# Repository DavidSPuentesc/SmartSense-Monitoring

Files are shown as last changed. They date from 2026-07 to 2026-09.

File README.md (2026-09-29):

# SmartSense Monitoring



Proyecto académico de monitoreo de temperatura superficial industrial con
PT100 de tres hilos, MAX31865, ESP32-C6, comunicación LoRa y consulta histórica
en un dashboard local. Apoya monitoreo de condición; no implementa ni valida
mantenimiento predictivo.

## Contenido del repositorio

- [SmartSense_Trabajo_Grado.tex](SmartSense_Trabajo_Grado.tex): tesis monográfica de una columna, clase `report`, fuera del formato IEEE.
- `tesis/`: preliminares, diez capítulos, anexos, bibliografía autor-fecha y registro compartido `datos-evidencia.tex`.
- [hardwarex/SmartSense_HardwareX.tex](hardwarex/SmartSense_HardwareX.tex): artículo HardwareX.
- `SmartSense_IEEE.tex`: fuente histórica conservada.
- `figuras/`: imágenes y fotografías usadas por ambos documentos.
- `figuras_anteproyecto/`: diagramas del anteproyecto.
- `Entrega_SmartSense/`: entregas anteriores.
- `compilar_trabajo_grado.ps1` y `hardwarex/compilar_hardwarex.ps1`: compilación de los documentos actuales en Windows.
- `compilar_ieee.ps1`: compilación del documento histórico.
- `COMPILAR_LATEX.md`: instrucciones de compilación.

La carpeta `.tools` no se sube porque contiene un ejecutable local. Cada
integrante puede instalar Tectonic o una distribución de LaTeX en su equipo.

## PDF para compartir

| Documento | Entregable actual |
|---|---|
| Trabajo de grado | [SmartSense_Trabajo_Grado.pdf](PDF_Para_Compartir/SmartSense_Trabajo_Grado.pdf) |
| Artículo HardwareX | [SmartSense_HardwareX.pdf](PDF_Para_Compartir/SmartSense_HardwareX.pdf) |

Los archivos previos `PDF_Para_Compartir/Articulo_SmartSense_HardwareX.pdf` y
`PDF_Para_Compartir/Tesis_SmartSense_Monitoring.pdf`, cuando estén presentes,
pertenecen al usuario y deben conservarse sin sobrescribir. Los nuevos
entregables usan los nombres de la tabla. Las fuentes, los PDF compilados
actuales y las nuevas copias de entrega quedan versionados en esta rama.

## Compilación

En Windows:

```powershell
powershell.exe -NoProfile -ExecutionPolicy Bypass -File .\compilar_trabajo_grado.ps1
powershell.exe -NoProfile -ExecutionPolicy Bypass -File .\hardwarex\compilar_hardwarex.ps1
```

Los resultados son `SmartSense_Trabajo_Grado.pdf` en la raíz y
`hardwarex/SmartSense_HardwareX.pdf`. Los scripts no copian automáticamente a
la carpeta de entrega. Véase [COMPILAR_LATEX.md](COMPILAR_LATEX.md) para la
selección de compilador, limpieza limitada de auxiliares, verificación y copia.

## Evidencia y reproducibilidad

Los tres archivos de nodos suman 51.338 muestras: A/C abarcan 8 de mayo a 9 de
junio de 2026 (32 días); B abarca 10 de mayo a 20 de julio. No son 32 días
completos comunes. Disponibilidad durante actividad inferida y PDR estimado
usan filtros distintos. La autonomía se extrapola de cinco días; 688 m es
una cota inferior del recorrido. Frente al Fluke, seis parejas con foto y hora
verificables contra el CSV difieren 0,15 °C de media absoluta y 0,23 °C como máximo.

Hay firmware, hardware, carcasa STL/3MF, BOM, figuras, scripts y las fuentes de la
tesis y del artículo. Faltan los CSV primarios del piloto, cuya publicación depende
de la empresa aliada, y la clase de tolerancia de la PT100. El repositorio está
publicado como versión `v1.0-tesis` y archivado en Zenodo con el DOI de concepto
[10.5281/zenodo.22903028](https://doi.org/10.5281/zenodo.22903028), que resuelve a la
versión más reciente (esta versión: 10.5281/zenodo.22903029).

Las licencias están descritas en [LICENSES/README.md](LICENSES/README.md):
CERN-OHL-S v2 para hardware (incluida la BOM), MIT para firmware/software/análisis
y CC-BY 4.0 para documentación. La réplica local está en `docker/` y el firmware
LoRa en `sensores espnow lora/version con lora y pagina local/`.

Para colaborar, repartir capítulos o figuras en ramas y revisar los cambios
antes de integrarlos. No presentar ensayos nuevos sin sus registros primarios.

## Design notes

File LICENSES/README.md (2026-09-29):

# Licencias de SmartSense Monitoring

Este proyecto es open source. Cada parte tiene su licencia (como exige HardwareX):

| Parte del proyecto | Archivos | Licencia |
|---|---|---|
| **Hardware** (esquemáticos KiCad, cableado, carcasa PLA / CAD / STL) | `hardware/`, `figuras/esquematico-*`, CAD de la carcasa | **CERN-OHL-S v2** — `CERN-OHL-S-v2.txt` |
| **Firmware y software** (sketches Arduino, réplica Docker, scripts de análisis) | `sensores espnow lora/`, `docker/`, `analisis/` | **MIT** — `MIT.txt` |
| **Documentación** (manuscritos, figuras, tablas, README y PDF) | `SmartSense_IEEE.tex`, `hardwarex/`, `SmartSense_Trabajo_Grado.tex`, `tesis/`, `*.md`; los PDF de trabajo `SmartSense_Trabajo_Grado.pdf` y `hardwarex/SmartSense_HardwareX.pdf`; y los PDF de entrega versionados `PDF_Para_Compartir/SmartSense_Trabajo_Grado.pdf` y `PDF_Para_Compartir/SmartSense_HardwareX.pdf` | **CC-BY 4.0** — `CC-BY-4.0.txt` |

Las copias históricas conservadas localmente en `PDF_Para_Compartir/Articulo_SmartSense_HardwareX.pdf` y `PDF_Para_Compartir/Tesis_SmartSense_Monitoring.pdf` también son documentación bajo CC-BY 4.0, pero no forman parte de la entrega versionada. Los dos PDF de entrega vigentes sí son `PDF_Para_Compartir/SmartSense_Trabajo_Grado.pdf` y `PDF_Para_Compartir/SmartSense_HardwareX.pdf`. Esta asignación no modifica las licencias de los materiales de terceros citados o incorporados bajo sus propios términos.

El mapa es coherente con las declaraciones del artículo HardwareX: CERN-OHL-S v2 para hardware, MIT para firmware/software/análisis y CC-BY 4.0 para documentación. La tesis y sus PDF aplican esta misma licencia de documentación.

## Depósito en Zenodo

Versión `v1.0-tesis` archivada el 22 de septiembre de 2026: DOI de concepto
[10.5281/zenodo.22903028](https://doi.org/10.5281/zenodo.22903028), que resuelve a la
versión más reciente (esta versión: 10.5281/zenodo.22903029). El depósito incluye los
esquemáticos KiCad editables, la BOM y las conexiones, el firmware, la réplica Docker,
los scripts de análisis, los STL/3MF de la carcasa, las fuentes de la tesis y del
artículo y estos archivos de licencia. Cada release nuevo en GitHub genera una versión
nueva bajo el mismo DOI de concepto.

`secrets.h` está fuera del repositorio y el árbol versionado no contiene credenciales.
La clave que quedó en el historial de git es la del punto de acceso del propio
prototipo, sin valor fuera de él.

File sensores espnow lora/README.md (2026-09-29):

# Sensores ESP-NOW y LoRa

Repositorio de desarrollo del sistema SmartSense para adquisición de
temperatura, comunicación entre nodos y visualización local.

## Versiones incluidas

- `version con espnow/`: prototipo de comunicación ESP-NOW.
- `version con pagina web en wifi local/`: versión con interfaz web en la red
  Wi-Fi local.
- `version con lora y pagina local/`: versión actual con nodos LoRa, maestro
  con pantalla, dashboard local y módulos de alarma.

La copia `.rar`, los cachés de Python y los ajustes personales de VS Code no
se versionan.

## Trabajo en paralelo

Antes de comenzar una tarea:

```powershell
git switch main
git pull
git switch -c nombre/tarea
```

Al terminar:

```powershell
git add .
git commit -m "Describe el cambio"
git push -u origin nombre/tarea
```

Después se abre un *pull request* hacia `main`. Cada persona debe trabajar en
una rama diferente y evitar editar simultáneamente el mismo sketch.

## Seguridad

Las credenciales locales de las pruebas de Wi-Fi y actualización OTA van en
`secrets.h`, que Git ignora; cada sketch trae una plantilla `secrets.example.h`.

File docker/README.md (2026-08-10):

# Réplica Docker — SmartSense Monitoring

Réplica local y **neutra** (sin marca de empresa) del dashboard, pensada para:

- Cargar de forma masiva los exportes CSV de la planta (botón **Cargar CSV**).
- Explorar el histórico por sensor y generar las figuras del artículo/tesis.
- Servir de demo genérica reutilizable para cualquier empresa (nombre configurable en `.env`).

Está programado en **Python (Flask)** con almacenamiento **SQLite**; la página es HTML + JavaScript plano.

## Uso

```bash
docker compose up --build
```

Abrir <http://localhost:8500>. Los datos quedan en `./data/lecturas.db` (SQLite, persistente entre reinicios).

> El puerto por defecto es **8500** porque la franja 8080–8161 la ocupan los contenedores de securapp en esta máquina (por eso al abrir el 8080 aparecía la app de RAMO).

El `.env` es **opcional**: si existe, Compose lo lee solo (copiar de `.env.example` para cambiar el nombre visible o el puerto).

## Formato del CSV

Encabezado flexible (se aceptan `,` o `;` y coma decimal de Excel). Columnas reconocidas:

| Dato | Encabezados aceptados | Obligatorio |
|---|---|---|
| Sensor | `sensor`, `mac`, `nodo`, `nombre`, `id` | Sí |
| Fecha y hora | `timestamp`, `ts`, `fecha_hora`, `datetime` — o `fecha` + `hora` en columnas separadas | Sí |
| Temperatura (°C) | `temperatura`, `temp`, `temp_c`, `temperature` | Sí |
| Batería (%) | `bateria`, `battery`, `bat` | No |

Formato canónico recomendado:

```csv
sensor,timestamp,temperatura_c,bateria_pct
Nodo-1,2026-01-15 10:00:00,25.4,87
```

Las filas duplicadas (mismo sensor + misma marca de tiempo) se ignoran, así que se puede recargar el mismo archivo sin duplicar datos.

## Validaciones incluidas

- Archivo: solo `.csv`/`.txt`, no vacío, máximo 64 MB.
- Encabezado irreconocible → mensaje que dice exactamente qué columna falta y qué nombres se aceptan.
- Por fila: fecha/hora inválida, temperatura no numérica o fuera del rango físico de una PT100 (−200 a 850 °C) → la fila se rechaza y se reporta con número de línea y motivo (primeras 10).
- Batería fuera de 0–100 % → se descarta la batería pero **se conserva** la lectura de temperatura.
- Fechas del histórico: formato AAAA-MM-DD; si el rango viene invertido se corrige solo.
- Todos los errores del servidor responden JSON con mensaje claro (nunca una página HTML de error).

## Verificación rápida

```bash
python app.py selftest
```

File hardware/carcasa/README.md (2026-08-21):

# Carcasas impresas en PLA (design files)

Archivos de la carcasa del nodo sensor y del gateway, para impresión 3D.

| Archivo | Qué es |
|---|---|
| `carcasa-sensor.stl` | Cuerpo de la carcasa del nodo sensor |
| `tapa-sensor.stl` | Tapa del nodo sensor |
| `carcasa-gateway.stl` | Cuerpo de la carcasa del gateway/visualizador |
| `tapa-gateway.stl` | Tapa del gateway |
| `sensor.3mf.zip` | Proyecto 3MF del nodo (laminado/orientación de impresión) |

**Formato:** solo STL + 3MF (archivos para imprimir). No se dispone del CAD
editable original. Para HardwareX, el STL es un design file válido; el CAD
editable se documentará si se rehace el modelo.

**Nota IP:** la carcasa PLA impresa no tiene una clasificación IP certificada;
está pensada para ambiente controlado / interior. Para exteriores o zonas con
polvo/humedad se recomienda rediseñar con sellos apuntando a IP54/IP65.

Licencia: CERN-OHL-S v2 (ver `LICENSES/`).

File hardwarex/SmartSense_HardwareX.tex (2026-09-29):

% SmartSense Monitoring - HardwareX article
% Built on the official HardwareX article template (Version 2, June 2021).
% Template instructions (italic text) have been removed as required before submission.
\documentclass[11pt, letterpaper]{article}
\usepackage[utf8]{inputenc}
\usepackage[margin=1.5cm]{geometry}
\usepackage{titlesec}
\usepackage{tabu}
\usepackage{enumitem}
\usepackage{amssymb}
\usepackage{xcolor}
\usepackage{graphicx}
\graphicspath{{../figuras/}}
\usepackage{placeins}

\usepackage{lmodern}
\usepackage{hyperref}
\hypersetup{colorlinks=true, linkcolor=blue, filecolor=magenta, urlcolor=blue}
\urlstyle{same}

\titleformat{\section}[block]{\hspace{1em}\bfseries}{\thesection.}{0.5em}{}
\titleformat{\subsection}[block]{\hspace{1em}}{\thesubsection}{0.5em}{}

\setlength{\parindent}{0pt}
\setlength{\parskip}{10pt}

\begin{document}
\begin{flushleft}

\textbf{Article title}\\
SmartSense Monitoring: an open-source wireless PT100 node and gateway for surface-temperature monitoring of industrial equipment

\textbf{Authors}\\
Jesus Andre Bojaca Lopez, David Santiago Puentes Cardenas*, Jhon Edwin Vera, Sergio Francisco Mora Martinez

\textbf{Affiliations}\\
Electronic Engineering Program, Faculty of Engineering, Universidad ECCI, Bogota D.C., Colombia

\textbf{Corresponding author's email address and Twitter handle}\\
davids.puentesc@ecci.edu.co

\textbf{Abstract}\\
SmartSense Monitoring is an open-source wireless PT100 node and gateway for industrial surface-temperature monitoring. Each battery-powered node combines a XIAO ESP32-C6, a three-wire PT100 probe, a MAX31865 front-end and an Ebyte E220 LoRa radio at 433~MHz. The gateway stores a rolling 30-day history locally and serves a Wi-Fi dashboard without a cloud service. A three-node evaluation includes a 32-day pilot deployment and an extended Node B record, totalling 51{,}338 samples across the individual recording windows. Raw availability was 76.0\%, 32.3\% and 75.1\%; link availability conditioned on inferred gateway-active periods was 97.8--98.4\%. Arrival intervals support an inferred PDR of 95.3--96.6\%. Six time-stamped paired readings against an infrared thermometer, taken with the surface stable, differ by 0.15~$^{\circ}$C on average and 0.23~$^{\circ}$C at most after offset adjustment, without establishing absolute accuracy. A five-day partial discharge supports estimated autonomy of 177 days by linear extrapolation and 291--307 days using a LiPo-curve model, not demonstrated service lifetime. A temperature rise was later associated with a bearing anomaly during inspection, supporting condition monitoring without validated diagnosis or prediction. Hardware, firmware, software and analysis artifacts are versioned in a public repository; absent primary CSV files and incomplete component identification limit full replication of the evaluation.

\textbf{Keywords}\\
Open-source hardware; LoRa; PT100; RTD; MAX31865; ESP32-C6; industrial temperature monitoring; condition monitoring

\newpage
\textbf{Specifications table}\\
\vskip 0.2cm
\tabulinesep=1ex
\begin{tabu} to \linewidth {|X[l]|X[3,l]|}
\hline \textbf{Hardware name} & SmartSense Monitoring \\
\hline \textbf{Subject area} &
  \begin{itemize}[noitemsep, topsep=0pt]
  \item Engineering and material science
  \item Educational tools and open source alternatives to existing infrastructure
  \end{itemize} \\
\hline \textbf{Hardware type} &
  \begin{itemize}[noitemsep, topsep=0pt]
  \item Measuring physical properties and in-lab sensors
  \item Field measurements and sensors
  \item Electrical engineering and computer science
  \end{itemize} \\
\hline \textbf{Closest commercial analog} & Industrial wireless RTD/condition-monitoring loggers such as the Advantech WISE-2410 and commercial PT100 wireless data loggers. \\
\hline \textbf{Open source license} & Hardware: CERN-OHL-S v2. Firmware and software: MIT License. Documentation: CC-BY 4.0. \\
\hline \textbf{Cost of hardware} & Itemized total: 627{,}000~COP ($\approx$157~USD at the project conversion assumption of 4{,}000~COP/USD). Node-specific parts: 149{,}000~COP ($\approx$37~USD), before shared wiring; see Bill of materials. \\
\hline \textbf{Source file repository} & \href{https://github.com/DavidSPuentesc/SmartSense-Monitoring}{SmartSense-Monitoring on GitHub}; archived on Zenodo, DOI \href{https://doi.org/10.5281/zenodo.22903028}{10.5281/zenodo.22903028} (concept DOI resolving to the latest version; release v1.0-tesis: 10.5281/zenodo.22903029). \\
\hline
\end{tabu}
\end{flushleft}

\newpage
\section{Hardware in context}

Continuous temperature monitoring of motors and other industrial equipment helps identify conditions associated with friction, overload, poor ventilation or mechanical degradation. In a manual inspection, an operator obtains only the value at the instant of measurement; if that value is not systematically recorded, the thermal evolution of the equipment cannot be reconstructed or related to its operating and stop cycles.

Wireless sensor networks distribute measurement points without installing communication cabling at each location [1,2,6]. For low-data-rate applications, LoRa provides a long-range, low-power alternative suited to battery-powered nodes, whose range and scalability have been characterised experimentally [3,7,8]. Relevant precedents include LoRaWAN temperature monitoring with a local-server option [9], an open condition-monitoring sensor with vibration and acoustic measurements [10], and the local SD-based HIGROTERM logger [12]. SmartSense contributes the integration of an external three-wire PT100 and MAX31865, point-to-point radio, battery operation and a gateway-hosted daily history and dashboard. Its contribution is this documented platform and pilot evaluation, rather than invention of its constituent technologies or superiority over all existing systems. It supports condition-based maintenance [4,11] but does not implement or validate a predictive-maintenance algorithm.

A PT100 RTD was selected for its established industrial use, three-wire lead compensation with the MAX31865 and availability in a magnetic surface probe suitable for motor housings. The installed probe is a ZUIDID magnetic three-wire PT100 (AliExpress item 1005008619909588): a thin-film element in a 19~$\times$~9.5~mm probe with a protective tube and spring sheath, epoxy-encapsulated with thermally conductive silicone, a standard cable rated $-60$ to 200~$^{\circ}$C and a three-wire U-terminal [14]. The seller does not state the tolerance class, and the $-60$ to 200~$^{\circ}$C figure is the cable rating, so the generic RTD conversion range cannot be assigned to the complete installed probe. The field comparison below characterises agreement in a narrow temperature interval, not the full measurement range or inter-node repeatability.

Compared with proprietary industrial loggers such as the Advantech WISE-2410, SmartSense Monitoring trades integrated vibration sensing for full openness and local-first operation. Table~\ref{tab:comparison} contrasts both systems by capability rather than price alone, making it suitable for pilot plants and educational settings where flexibility and reproducibility matter more than a turnkey platform.

\begin{table}[h]
\centering
\tabulinesep=1ex
\begin{tabu} to \linewidth {|X|X[c]|X[c]|X[0.6,c]|}
\hline
\textbf{Feature} & \textbf{SmartSense} & \textbf{WISE-2410} & \textbf{Advantage} \\\hline
Open hardware & Project schematics and enclosure files, CERN-OHL-S v2 & Commercial design; no open hardware release identified & SmartSense \\\hline
External PT100 & Yes, three-wire surface probe & Integrated temperature sensor; no external PT100 specified & SmartSense \\\hline
Communication & LoRa 433~MHz (point-to-point) & LoRaWAN & Different \\\hline
Vibration sensing & No & Yes & WISE-2410 \\\hline
Local history & microSD or LittleFS; rolling 30-day store & Depends on gateway/application integration & SmartSense \\\hline
Cloud dependency & None for local dashboard & LoRaWAN gateway/server required; cloud is not inherently mandatory & SmartSense \\\hline
IP rating & Not demonstrated & IP66 specified & WISE-2410 \\\hline
Autonomy evidence & Estimated from 5-day partial discharge: 177 or 291--307 days; 1000~mAh, 120~s cycle & Up to 2 years specified; hourly updates [5] & WISE-2410 (specified); SmartSense pending \\\hline
Software openness & MIT node/gateway firmware and software & WISE Studio utility; open firmware not identified & SmartSense \\\hline
Cost basis & 149{,}000~COP per node in listed parts ($\approx$37~USD); excludes shared wiring & No comparable dated quotation available & Not comparable \\\hline
\end{tabu}
\caption{Functional comparison with Advantech WISE-2410 [5]. WISE-2410 retains advantages in vibration, IP66 protection and specified lifetime. Autonomy uses different update intervals and evidence types; no controlled superiority claim follows. SmartSense cost uses the project BOM and a 4{,}000~COP/USD conversion assumption.}
\label{tab:comparison}
\end{table}

\section{Hardware description}

SmartSense Monitoring consists of one or more battery-powered sensor nodes and a gateway/visualizer. Each node acquires the surface temperature of a machine with a magnetic PT100 probe and a MAX31865 RTD front-end, estimates its battery state, and transmits the reading over a 433~MHz LoRa link before entering deep sleep. The gateway receives the frames, identifies each node by its MAC address, applies a configurable offset, stores the samples locally and presents them on an integrated touch display and a Wi-Fi web dashboard.

The documented radio configuration uses 9600~bit/s UART (8N1), 2.4~kbit/s air rate, channel 23 in the stated 433~MHz band and fixed addressing. The radio is an Ebyte E220-400T22D (Semtech LLCC68, 410.125--493.125~MHz), so channel 23 corresponds to 433.125~MHz, its factory frequency. The transmit power is 22~dBm, the module's maximum and factory default, which is also the value (power code 0) written by the firmware's one-time configuration routine; the datasheet gives a typical receiver sensitivity of $-127$~dBm at 2.4~kbit/s [13]. A 120~s nominal cycle provides 720 expected samples per node per day, balancing thermal-history resolution with traffic, storage and battery demand for this pilot.

\begin{itemize}
\item[$\bullet$] It provides automatic periodic surface-temperature logging using commercially available modules and an itemized bill of materials.
\item[$\bullet$] It operates fully offline: the gateway serves its own dashboard over a local Wi-Fi access point, so no cloud account or Internet connection is required.
\item[$\bullet$] It preserves a per-sensor daily history, enabling the study of thermal trends, transients and machine on/off cycles that a spot measurement cannot capture.
\item[$\bullet$] It is a modular basis for further work: additional nodes, alternative RTD probes, or extra variables (e.g. current, vibration) can be integrated by reusing the node design.
\item[$\bullet$] Published project schematics and source code support teaching wireless sensor networks, RTD acquisition and local data handling; the purchased modules retain their manufacturer-specific internals.
\end{itemize}

\section*{\textit{Design files}}

The complete repository, with the editable KiCad schematics, node and gateway firmware, software, BOM, enclosure files, analysis scripts, figures, licenses and the manuscript sources, is released as version \texttt{v1.0-tesis} on GitHub (\href{https://github.com/DavidSPuentesc/SmartSense-Monitoring}{DavidSPuentesc/SmartSense-Monitoring}) and archived on Zenodo under the concept DOI \href{https://doi.org/10.5281/zenodo.22903028}{10.5281/zenodo.22903028}, which resolves to the latest version (this release: 10.5281/zenodo.22903029).

The primary historical and range-test CSV files read by the scripts are not included in the archived version; their publication depends on the partner company\textquotesingle s authorization. The tolerance class of the PT100 probe is not stated by its seller. The repository therefore supports inspection and reconstruction of the documented design, but not yet exact replication of every reported experiment.

\section{Design files summary}
\vskip 0.1cm
\begingroup\small
\tabulinesep=1ex
\begin{tabu} to \linewidth {|X[1.4,l]|X[1,l]|X[1,l]|X[1.5,l]|}
\hline
\textbf{Design filename} & \textbf{File type} & \textbf{Open source license} & \textbf{Location of the file} \\\hline
Node schematic (nodo\_sensor) & KiCad schematic + PDF/SVG & CERN-OHL-S v2 & \texttt{hardware/kicad/} in identified snapshot \\\hline
Gateway schematic (gateway) & KiCad schematic + PDF/SVG & CERN-OHL-S v2 & \texttt{hardware/kicad/} in identified snapshot \\\hline
\nolinkurl{smartsense.kicad_sym} & KiCad symbol library & CERN-OHL-S v2 & \texttt{hardware/kicad/} \\\hline
Node firmware (Nodo\_Lora) & Arduino C++ (.ino) & MIT & Firmware directory specified below \\\hline
Gateway firmware (\nolinkurl{maestro_Lora_pantalla}) & Arduino C++ (.ino) + web assets & MIT & Firmware directory specified below \\\hline
Bill of materials (BOM.csv) & CSV spreadsheet & CERN-OHL-S v2 & \texttt{hardware/BOM.csv} \\\hline
Enclosure (node, gateway, lids) & STL + zipped 3MF & CERN-OHL-S v2 & \texttt{hardware/carcasa/} \\\hline
\end{tabu}
\endgroup

\vskip 0.3cm
The schematics document SPI, UART, switched sensor power and the battery divider. Both firmware folders are under \texttt{sensores espnow lora/version con lora y pagina local/}; they contain acquisition, reception, storage and dashboard logic. The BOM and existing PLA enclosure STL/3MF files are in the paths above. These project files do not replace missing probe specifications or a frozen record of the pilot configuration.

\section*{\textit{Bill of materials}}

Costs reproduce the project BOM, reviewed on 15 September 2026, in Colombian pesos (COP). USD equivalents use the project's approximate conversion assumption of 1~USD~=~4{,}000~COP, not a verified dated exchange-rate quotation. Supplier invoices and purchase dates are not included. The table covers three nodes and one gateway; prices are historical project entries rather than current market quotations.

\section{Bill of materials summary}
\vskip 0.2cm
\begingroup\small
\tabulinesep=1ex
\begin{tabu} to \linewidth {|X[0.8,l]|X[1.6,l]|X[0.4,c]|X[0.9,r]|X[0.9,r]|X[1.2,l]|X[1.1,l]|}
\hline
\textbf{ID} & \textbf{Component} & \textbf{Qty.} & \textbf{Unit cost (COP)} & \textbf{Total (COP)} & \textbf{Source} & \textbf{Material} \\\hline
U1 & Seeed Studio XIAO ESP32-C6 (node) & 3 & 30{,}000 & 90{,}000 & \href{https://www.seeedstudio.com/}{Seeed Studio} & Semiconductor \\\hline
U2 & ESP32-C6 Touch LCD 1.47 board (gateway) & 1 & 90{,}000 & 90{,}000 & Local distributor & Semiconductor \\\hline
U3 & Ebyte E220-400T22D LoRa module (LLCC68, 22~dBm) + antenna & 4 & 30{,}000 & 120{,}000 & \href{https://www.cdebyte.com/products/E220-400T22D}{Ebyte} & Semiconductor \\\hline
RT1 & ZUIDID magnetic three-wire PT100 probe (thin film; cable rated $-60$ to 200~$^{\circ}$C) & 3 & 30{,}000 & 90{,}000 & \href{https://www.aliexpress.com/item/1005008619909588.html}{AliExpress} [14] & Metal \\\hline
U4 & MAX31865 RTD front-end module & 3 & 14{,}000 & 42{,}000 & \href{https://www.sigmaelectronica.net/}{Sigma Electr\'onica} & Semiconductor \\\hline
BT1 & LiPo battery 3.7~V 1000~mAh & 3 & 30{,}000 & 90{,}000 & \href{https://www.didacticaselectronicas.com/}{Did\'acticas Electr\'onicas} & Other \\\hline
U5 & LiPo charge and protection module (TP4056 or equiv.) & 3 & 5{,}000 & 15{,}000 & Local distributor & Semiconductor \\\hline
R1 & Resistor 344.8~k$\Omega$ (battery divider) & 3 & -- & -- & Local distributor & Other \\\hline
R2 & Resistor 994.3~k$\Omega$ (battery divider) & 3 & -- & -- & Local distributor & Other \\\hline
MEC1 & 3D-printed PLA enclosure & 4 & 10{,}000 & 40{,}000 & Self-printed & Polymer \\\hline
W1 & Wires, connectors, headers, hardware, adhesives & 1 & 50{,}000 & 50{,}000 & Local distributor & Other \\\hline
\end{tabu}
\endgroup
\vskip 0.2cm
Itemized total: 627{,}000~COP ($\approx$157~USD at the stated conversion). Node-specific parts sum to 149{,}000~COP per node, including the 1000~mAh cell and enclosure; gateway board, radio and enclosure sum to 130{,}000~COP. Shared wiring/hardware contributes 50{,}000~COP, including battery-divider resistors. These entries do not establish a labor, shipping or certification cost.

\section{Build instructions}

The following steps describe the construction of one sensor node and the gateway. Refer to the node and gateway schematics (Design files) and to the Bill of materials for component designators.

\textbf{Sensor node}
\begin{enumerate}[noitemsep]
\item Use a three-wire magnetic PT100 probe (the pilot used a ZUIDID thin-film probe, AliExpress item 1005008619909588, cable rated $-60$ to 200~$^{\circ}$C, tolerance class not stated [14]); record the tolerance class when available before replication. Configure the MAX31865 module in three-wire mode (bridge the 2/3-wire jumper), and connect the PT100 leads: the two leads from the same probe end to F+ and RTD+, and the remaining lead to RTD-, bridged to F-.
\item Wire the MAX31865 SPI bus to the XIAO ESP32-C6: CLK\,$\rightarrow$\,D6 (GPIO16), SDO\,$\rightarrow$\,D5 (GPIO23), SDI\,$\rightarrow$\,D4 (GPIO22), CS\,$\rightarrow$\,D3 (GPIO21). Power the module VIN from D2 (GPIO2) so the firmware can switch it off during deep sleep.
\item Connect the E220 LoRa module by UART: E220 TXD\,$\rightarrow$\,D7 (GPIO17), RXD\,$\rightarrow$\,D8 (GPIO19), M0\,$\rightarrow$\,D10 (GPIO18), M1\,$\rightarrow$\,D9 (GPIO20); power VCC/GND from 3V3/GND.
\item Build the battery divider: VBAT\,--\,R1 (344.8~k$\Omega$)\,--\,A0 (GPIO0)\,--\,R2 (994.3~k$\Omega$)\,--\,GND. Connect the LiPo cell through the TP4056 charge/protection module to the XIAO battery pads.
\item Flash the node firmware (\texttt{Nodo\_Lora.ino}) with the Arduino IDE and the ESP32 board package. Install the Adafruit\_MAX31865 library. Set \texttt{RREF} to the measured reference resistance of your MAX31865 module (421.1~$\Omega$ in this build).
\item Fit the components in the 3D-printed PLA enclosure and attach the PT100 magnetically to the target surface.
\end{enumerate}

\textbf{Gateway}
\begin{enumerate}[noitemsep]
\item Connect the E220 module to the ESP32-C6 Touch LCD board: E220 TXD\,$\rightarrow$\,GPIO8 (gateway RX), RXD\,$\rightarrow$\,GPIO7 (gateway TX), and both M0 and M1 to GPIO9; power VCC/GND from 3V3/GND.
\item Optionally wire a critical-alarm output (LED, buzzer or relay driver) to GPIO16.
\item Flash the gateway firmware (\texttt{maestro\_Lora\_pantalla.ino}) and upload the web dashboard assets to the on-board storage (LittleFS). Insert a microSD card for the history.
\end{enumerate}

\textbf{Safety.} Use a fused LiPo cell with the TP4056 protection module and observe LiPo handling precautions. Ensure the PT100 and enclosure are rated for the surface temperature of the monitored equipment and mounted so they do not interfere with moving parts.

\begin{figure}[h]\centering
\begin{minipage}[b]{0.44\linewidth}\centering
  
\end{minipage}\hfill
\begin{minipage}[b]{0.44\linewidth}\centering
  
\end{minipage}
\caption{Assembled sensor node mounted on a motor housing: the PT100 probe with the MAX31865 module (left) and the node enclosure with the LoRa antenna (right).}
\label{fig:node-photo}
\end{figure}

\begin{figure}[h]\centering
\hspace{3mm}
\hspace{3mm}

\caption{Final 3D-printed PLA enclosures. Left: cylindrical node enclosure with the SMA antenna. Centre: node lid with the USB-C charging port and antenna. Right: gateway enclosure with the touch-screen window, antenna and the label of its paired node. STL and 3MF files are in \texttt{hardware/carcasa/}.}
\label{fig:enclosures}
\end{figure}

\section{Operation instructions}

\begin{enumerate}[noitemsep]
\item Power the gateway. It creates a Wi-Fi access point (\texttt{Sensores\_Temp}) and serves the dashboard at \texttt{http://192.168.4.1}.
\item Power each node. The reviewed firmware defaults to 60~s of sleep, configurable between 5 and 7200~s; the pilot used 120~s. Activity after waking adds to this sleep duration. Verify the retained setting before replication. The gateway registers each node by its MAC address.
\item In the dashboard, assign names to sensors, group them by machine, set the sampling interval, apply a per-node temperature offset, and configure warning and critical thresholds.
\item Monitor the live values (temperature, battery, connectivity) and consult the per-day 24-hour history, including minimum, maximum and average, and compare sensors of the same machine.
\item Preserve copies of the per-sensor stored history before the 30-day rotation removes older dates. The project analysed exported CSVs and the software replica can import them; direct web CSV download is not verified in the reviewed gateway firmware and is not claimed as a demonstrated interface function.
\end{enumerate}

\begin{figure}[h]\centering

\caption{Local web dashboard: per-sensor temperature history over the deployment, with minimum, maximum and mean statistics. Shown here running on the open-source software replica with generic sensor labels.}
\label{fig:dashboard}
\end{figure}

\textbf{Safety.} The critical-alarm output is a supervisory aid, not a safety interlock; do not use it as the sole protection for equipment or personnel.

\section{Validation and characterization}

The three-node evaluation includes a 32-day pilot deployment (8 May--9 June 2026 for Nodes A and C), with Node B recorded from 10 May to 20 July 2026. The 51{,}338 samples are the sum of these individual files, not a count over 32 complete days common to all three nodes. Figures comparing nodes use their overlapping interval. The nominal cycle was 120~s and the documented median inter-arrival interval was 121~s. Separate partial-discharge and radio-range tests were performed in August.

\textbf{Availability.} Table~\ref{tab:avail} separates raw system-level data availability from link availability conditioned on inferred gateway-active periods. The generator \texttt{analisis/figuras\_validacion.py} uses 121~s as the expected cadence. Raw availability divides received samples by the expected count across each node's first-to-last-record span. Conditioned availability removes the entire duration of each inter-arrival gap exceeding 363~s before computing the expected count. Simultaneous gaps in Fig.~\ref{fig:cobertura} support a common-cause interpretation, including gateway power interruptions during plant stoppages; they do not independently prove the power state or distinguish reception, clock and storage failures. Thus 97.8--98.4\% describes classified active periods, not overall system availability, and the excluded hours cannot all be asserted to be confirmed power-off hours.

\begin{table}[h]
\centering
\tabulinesep=1ex
\begin{tabu} to \linewidth {|X|X[c]|X[c]|X[c]|X[c]|X[c]|}
\hline
\textbf{Node} & \textbf{Samples} & \textbf{Raw avail.} & \textbf{Conditioned link avail.} & \textbf{Gaps} & \textbf{Hours excluded} \\\hline
Node A & 17{,}537 & 76.0\% & 98.4\% & 66 & 176 \\\hline
Node B & 16{,}487 & 32.3\% & 98.3\% & 73 & 1154 \\\hline
Node C & 17{,}314 & 75.1\% & 97.8\% & 81 & 180 \\\hline
\end{tabu}
\caption{Documented availability in the individual recording windows. Node B's longer file includes a gap of approximately 33 days; its raw availability is not a comparison over the same calendar span as A and C. Gap counts and excluded hours are temporal classifications, not a direct power log.}
\label{tab:avail}
\end{table}

\textbf{Reception cadence and inferred packet delivery.} Retained short intervals cluster near a 121~s median (Fig.~\ref{fig:intervalos}). The separate generator \texttt{analisis/perdida\_paquetes.py} uses a 120~s nominal cycle and excludes intervals longer than 1800~s. For retained gaps it rounds the interval divided by 120~s to $k$, infers $k-1$ missing frames when $k\geq2$, and computes received/(received + inferred missing). The documented inferred PDR is 96.55\%, 96.07\% and 95.32\% for A, B and C, respectively: 95.3--96.6\% rounded, with inferred loss of 3.5--4.7\%. Each estimate uses its individual node file, including Node B's extension. These filters and denominators differ from availability; neither metric is a direct sent-versus-received count. Without a historical sequence counter and send log, cadence assumptions cannot distinguish radio loss from absent acquisition or persistence.

\textbf{Representative 60-minute window.} The historical window of 10 May 2026, 00:00--01:00 (Fig.~\ref{fig:prueba60}), contains 29, 30 and 30 records for A, B and C against 30 nominally expected at a 120~s cycle: received/expected ratios of 96.7\%, 100\% and 100\%. The denominator is a schedule, not an observed transmission count. The script selects a window with at least 25 records per node, so this is a coverage-selected illustration, not an independent test or an unbiased estimate for all hours. RSSI was enabled later for the range test; the interface used did not expose SNR. A sequence counter added after the deployment supports future direct PDR testing but cannot recover historical sends. End-to-end latency and service recovery require synchronized node/gateway measurements.

\textbf{Range test.} On 20 August 2026 a node moved away from the gateway and back in an urban non-line-of-sight path with buildings in between (Fig.~\ref{fig:distancia}). Valid packets were received at the farthest observed distance, approximately 688~m, with RSSI near $-98$~dBm at 20:44--20:54, compared with approximately $-15$~dBm nearby. The test ended voluntarily with the link still operational: at least 688~m is a demonstrated lower bound in this geometry. Against the E220-400T22D datasheet sensitivity of $-127$~dBm typical at 2.4~kbit/s ($-126$ to $-129$~dBm) [13], the $-98$~dBm RSSI leaves a margin of about 29~dB; this is a margin to the manufacturer's figure, not a measured link-failure point. The recorded battery indicator stayed near 94\% during 2.6~h; this voltage-derived indication does not measure charge consumption. Motion and changing obstacles prevent a controlled RSSI--distance characterization; fixed positions and repeated trials remain future work.

\begin{figure}[h]\centering

\caption{Urban obstructed-path test of 20 August 2026: per-packet RSSI (blue) and voltage-derived battery indication (green) against time during a mobile outward and return route. The link remained operational near 688~m at approximately $-98$~dBm; distance was not a controlled fixed-position sweep.}
\label{fig:distancia}
\end{figure}

\begin{figure}[h]\centering

\caption{Temperature during a coverage-selected historical hour with three nodes. The original plot label ``test'' identifies this illustrative window, not a separate trial with a transmission counter.}
\label{fig:prueba60}
\end{figure}

\textbf{Temperature field comparison.} The purpose was to assess consistency of the installed node with a field reference on the suction-fan motor. Each Fluke 62 MAX reading was photographed next to the probe, and the photo time recorded by the phone locates it in the exported CSV; the node reading at that instant is interpolated between the two surrounding samples (\texttt{analisis/parejas\_fluke.py}), so every pair can be checked against the record (Table~\ref{tab:thermal-pairs}). The six pairs taken with the surface stable (changing less than 0.1~$^{\circ}$C/min), over three visits, give a signed mean difference of $-0.07$~$^{\circ}$C, a mean absolute difference of 0.15~$^{\circ}$C, an RMSE of 0.16~$^{\circ}$C and a maximum of 0.23~$^{\circ}$C between 51.6 and 67.6~$^{\circ}$C. The pair of 10 May was taken while the motor was starting after a stop and the surface rose 0.34~$^{\circ}$C/min; the housing seen by the Fluke warms ahead of the magnetic probe's contact point, and its $-3.6$~$^{\circ}$C difference reflects that thermal lag. With all seven pairs the mean absolute difference is 0.64~$^{\circ}$C and the RMSE 1.37~$^{\circ}$C. Earlier field readings from a visit whose record was not exported are not used.

\begin{table}[h]
\centering
\begin{tabular}{lrrrr}
\hline
Date and time & Fluke ($^{\circ}$C) & SmartSense ($^{\circ}$C) & $\Delta T$ ($^{\circ}$C) & Rate ($^{\circ}$C/min) \\
\hline
10 May 22:54:00 & 37.4 & 33.8 & $-3.6$ & $+0.34$ \\
12 May 14:17:15 & 51.7 & 51.6 & $-0.1$ & $-0.08$ \\
25 May 17:09:02 & 67.7 & 67.6 & $-0.1$ & $-0.01$ \\
25 May 17:15:18 & 67.7 & 67.5 & $-0.2$ & $-0.01$ \\
25 May 19:20:49 & 65.3 & 65.2 & $-0.1$ & $-0.02$ \\
5 June 17:14:19 & 62.5 & 62.3 & $-0.2$ & $-0.04$ \\
5 June 17:30:01 & 61.4 & 61.6 & $+0.2$ & $-0.04$ \\
\hline
\end{tabular}
\caption{Field-comparison pairs with photo time. SmartSense is the Node A reading interpolated at the photo time; the rate is the surface change over the surrounding ten minutes.}
\label{tab:thermal-pairs}
\end{table}

The FLIR image (Fig.~\ref{fig:termica}), attributed in the field record to a C8 camera, corroborates the location and approximate 70--71~$^{\circ}$C magnitude of the hotspot; it is not synchronized with the paired readings. The result is field consistency, not traceable calibration. The Fluke was also used to adjust the offset, so the comparison is not independent. The project cites instrument specifications of $\pm$1.5~$^{\circ}$C for the Fluke and $\pm$2~$^{\circ}$C for the FLIR, with no current Fluke calibration certificate. These limits exceed the order of the 1~$^{\circ}$C target and are not a combined uncertainty budget for the installed system. Emissivity and viewed area affect infrared readings; contact and mounting affect the PT100. Complementary characterization must use a calibrated contact reference, separate adjustment from verification, compare the three nodes at multiple temperatures and account for reference, conversion, lead, mounting and repeatability contributions. Absolute accuracy and inter-node repeatability remain unestablished.

\textbf{Field observation (case study).} The suction-fan motor history includes rises and falls and a recorded maximum of 70.0~$^{\circ}$C (Fig.~\ref{fig:serie}). Plant observations associated rising segments with periods when the machine stopped while the fan continued spinning unloaded; no synchronized machine-state log establishes the timing or lag of each transition. The thermal image then provides spatial context for the hotspot (Fig.~\ref{fig:termica}). Subsequent inspection associated the case with a bearing anomaly, which the plant team serviced during the machine stops of 30--31 May and 7--8 June 2026, after the 23 May peak; the exported history shows the probe near ambient temperature during those stops. This sequence---thermal history, operational context, thermal image and later inspection association---illustrates the use of historical data in condition monitoring. It does not establish diagnosis, prediction, lead time, causality, sensitivity or false-alarm performance; load, ventilation, mounting and other factors were not controlled.

\begin{figure}[h]\centering

\caption{Thermal image of the suction-fan motor, attributed to a FLIR C8 in the field record, locating a hotspot near 70--71~$^{\circ}$C. It supplies spatial context without proving a bearing cause or the PT100's absolute accuracy.}
\label{fig:termica}
\end{figure}

\textbf{Instrumented activity and temperature range.} A firmware-instrumented interval was 2.279~s in eight of ten documented starts, with small variations reported for the remaining two. Instrumentation begins after initial serial setup and delay, so this is not total physical power-on-to-service time or synchronized network latency. Dividing by the 120~s cycle gives approximately 1.9\% instrumented duty cycle; complete reset recovery remains to be measured through reception and persistence at the gateway. Across the individual historical files, surface temperature spanned 15.3--70.0~$^{\circ}$C, with per-node means of 39.5--45.4~$^{\circ}$C. These statistics describe recorded thermal behaviour, not calibrated range or measurement uncertainty.

\textbf{Estimated battery autonomy.} A controlled five-day partial discharge under the nominal 120~s operating cycle used the same 1000~mAh cell type fitted to the nodes, from 13 to 18 August 2026. Two voltage readings, 4.112~V and 4.089~V over 120~h, give a slope of approximately 0.19~mV/h. The generator \texttt{analisis/autonomia\_bateria.py} extrapolates that slope to 3.30~V for a conservative linear estimate of 177 days. Its assumed typical LiPo open-circuit-voltage/state-of-charge curve, fitted to the same two points, gives 291--307 days at cutoffs of 3.30 and 3.00~V, respectively (Fig.~\ref{fig:autonomia}). This range expresses two cutoffs under one model, not a statistical confidence interval. The curve is a project modeling assumption without a documented primary cell characterization. A component-level model built from datasheet currents and firmware timings (\texttt{analisis/modelo\_consumo.py}, Monte Carlo) gives 42--54 days, i.e. 3.5--6.4 times more consumption than the discharge implies; until node current is measured, autonomy is bounded between about 1.5 and 10 months.

Both values are estimated autonomy, not experimentally demonstrated lifetime. The linear result is conservative relative to the LiPo model but is not a guaranteed physical lower bound. Temperature, load, relaxation, ADC resolution, aging and self-discharge can alter the projection from this small voltage drop. Model-implied average current is approximately 0.13--0.24~mA; neither it nor the assumed microcontroller sleep current is an integrated measurement of the complete node. The 1.9\% instrumented duty cycle does not establish energy consumption. A full discharge to a specified cutoff and current logging by operating state are needed.

\begin{figure}[h]\centering

\caption{Two measured voltage points over five days with a 1000~mAh cell and extrapolated curves. Estimated autonomy is 177 days (linear, 3.30~V cutoff) or 291--307 days (assumed LiPo curve, 3.30/3.00~V cutoffs). The original plot's lower-bound label compares models; it does not guarantee service lifetime.}
\label{fig:autonomia}
\end{figure}

\begin{figure}[h]\centering

\caption{Node A surface-temperature history during the 32-day pilot deployment. The 70.0~$^{\circ}$C peak is a historical observation; its annotation does not identify a mechanical cause.}
\label{fig:serie}
\end{figure}

\begin{figure}[h]\centering

\caption{Data coverage in the three-node overlapping interval. White gaps retain missing data. The original ``gateway down'' plot label is an interpretation compatible with simultaneous interruptions, not an independently verified power-state record.}
\label{fig:cobertura}
\end{figure}

\begin{figure}[h]\centering

\caption{Short inter-arrival intervals retained after excluding gaps longer than 363~s, with logarithmic frame-count axis. The plotted range concentrates around the 121~s median and does not represent the full outage distribution.}
\label{fig:intervalos}
\end{figure}

\textbf{Capabilities and limitations.}
\begin{itemize}[noitemsep]
\item Acquires periodic surface-temperature readings with a three-wire PT100 and configurable per-node offset; the tolerance class of the probe is not stated by the seller.
\item Raw availability is 76.0\%, 32.3\% and 75.1\% in the individual windows; conditioned link availability is 97.8--98.4\% and PDR is inferred at 95.3--96.6\%, using different gap filters.
\item Operates locally with a rolling 30-day per-sensor store; older dates are removed after rotation. Pre-rotation exports preserved the records analysed beyond 30 days, including Node B's longer history. LittleFS is an alternative storage medium, not a mirrored backup. Direct web CSV export is unverified and primary CSVs are absent from the reviewed repository.
\item Six time-stamped pairs in steady state agree with the same Fluke used for the offset within 0.23~$^{\circ}$C; a pair taken during a warm-up differs by 3.6~$^{\circ}$C. Absolute accuracy requires an independent calibrated contact reference and an uncertainty budget.
\item A five-day partial discharge supports estimated autonomy of 177 days or 291--307 days under the stated model and cutoff assumptions; extended lifetime and complete-node current consumption were not experimentally demonstrated.
\item LoRa range of at least $\approx$688~m in a non-line-of-sight urban path, with the link operating down to $\approx-98$~dBm RSSI (test stopped voluntarily, not by link failure).
\item The interface used did not expose SNR, and synchronized end-to-end latency and complete service recovery were not measured. Three deployed nodes do not constitute controlled inter-node repeatability or a network-capacity test.
\end{itemize}

\FloatBarrier

\noindent
\textbf{Ethics statements}\\
This work did not involve human subjects or animal experiments.

\noindent
\textbf{CRediT author statement}\\
\textbf{Jesus Andre Bojaca Lopez}: Conceptualization, Methodology, Software, Investigation, Writing -- Original draft. \textbf{David Santiago Puentes Cardenas}: Conceptualization, Hardware, Software, Validation, Data curation, Writing -- Review \& Editing. \textbf{Jhon Edwin Vera}: Supervision. \textbf{Sergio Francisco Mora Martinez}: Supervision.

\noindent
\textbf{Declaration of generative AI and AI-assisted technologies in the writing process}\\
During the preparation of this work the authors used generative AI tools (ChatGPT, OpenAI, and Claude, Anthropic) to assist with language editing, restructuring and consistency checks of the manuscript. After using these tools, the authors reviewed and edited the content as needed and take full responsibility for the content of the publication.

\noindent
\textbf{Acknowledgements}\\
The authors thank the partner company that provided access to the pilot plant. This research did not receive any specific grant from funding agencies in the public, commercial, or not-for-profit sectors.

\noindent
\textbf{References}\par
\begin{enumerate}[label={[\arabic*]}, noitemsep]
\item I. F. Akyildiz, W. Su, Y. Sankarasubramaniam, and E. Cayirci, ``Wireless sensor networks: A survey,'' \textit{Computer Networks}, vol. 38, no. 4, pp. 393--422, 2002.
\item J. Yick, B. Mukherjee, and D. Ghosal, ``Wireless sensor network survey,'' \textit{Computer Networks}, vol. 52, no. 12, pp. 2292--2330, 2008.
\item M. Centenaro, L. Vangelista, A. Zanella, and M. Zorzi, ``Long-range communications in unlicensed bands: the rising stars in the IoT and smart city scenarios,'' \textit{IEEE Wireless Communications}, vol. 23, no. 5, pp. 60--67, 2016.
\item A. K. S. Jardine, D. Lin, and D. Banjevic, ``A review on machinery diagnostics and prognostics implementing condition-based maintenance,'' \textit{Mechanical Systems and Signal Processing}, vol. 20, no. 7, pp. 1483--1510, 2006.
\item Advantech Co., Ltd., ``WISE-2410 LoRaWAN wireless condition monitoring sensor,'' Data Sheet, 23 October 2024. \href{https://advdownload.advantech.com/productfile/PIS/WISE-2410/file/WISE-2410_DS\%28102324\%2920241023133301.pdf}{Manufacturer datasheet}, accessed 15 September 2026.
\item G. Mois, S. Folea, and T. Sanislav, ``Analysis of three IoT-based wireless sensors for environmental monitoring,'' \textit{IEEE Trans. Instrum. Meas.}, vol. 66, no. 8, pp. 2056--2064, 2017.
\item A. Augustin, J. Yi, T. Clausen, and W. M. Townsley, ``A study of LoRa: Long range \& low power networks for the Internet of Things,'' \textit{Sensors}, vol. 16, no. 9, art. 1466, 2016.
\item M. Bor, U. Roedig, T. Voigt, and J. M. Alonso, ``Do LoRa low-power wide-area networks scale?'' in \textit{Proc. 19th ACM MSWiM}, 2016, pp. 59--67.
\item T. Polonelli, D. Brunelli, A. Bartolini, and L. Benini, ``A LoRaWAN wireless sensor network for data center temperature monitoring,'' in \textit{Applications in Electronics Pervading Industry, Environment and Society}, LNEE, vol. 573, Springer, 2019.
\item M. O. Jakobsen, ``Low cost MEMS accelerometer and microphone based condition monitoring sensor, with LoRa and Bluetooth Low Energy radio,'' \textit{HardwareX}, vol. 18, art. e00525, 2024.
\item Z. M. Çınar, A. A. Nuhu, Q. Zeeshan, O. Korhan, M. Asmael, and B. Safaei, ``Machine learning in predictive maintenance towards sustainable smart manufacturing in Industry 4.0,'' \textit{Sustainability}, vol. 12, no. 19, art. 8211, 2020.
\item R. R. Ribeiro, E. Bauer, and R. Lameiras, ``HIGROTERM: An open-source and low-cost temperature and humidity monitoring system for laboratory applications,'' \textit{Inventions}, vol. 6, no. 4, art. 84, 2021.
\item Chengdu Ebyte Electronic Technology Co., Ltd., ``E220-400T22D user manual: 433/470~MHz 22~dBm LoRa wireless module,'' v1.0, 2020. \href{https://www.cdebyte.com/products/E220-400T22D}{Manufacturer page}, accessed 17 September 2026.
\item ZUIDID, ``Magnetic RTD PT100 sensor, high temperature, oil and corrosion resistant,'' AliExpress item 1005008619909588 product page (thin-film element, 19~$\times$~9.5~mm probe, cable rated $-60$ to 200~$^{\circ}$C, three-wire U-terminal), accessed 23 September 2026. \href{https://www.aliexpress.com/item/1005008619909588.html}{Product page}.
\end{enumerate}

\end{document}

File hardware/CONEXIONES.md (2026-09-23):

# SmartSense Monitoring — Tabla de conexiones (verificada contra firmware)

Fuente de verdad: `Nodo_Lora.ino`, `maestro_Lora_pantalla.ino`, `Display_ST7789.h`, `SD_Card.h`.
Estas tablas son el insumo directo para dibujar el esquemático en KiCad (ver `GUIA_KICAD.md`).

## 1. Nodo sensor (XIAO ESP32-C6)

### 1.1 Módulo LoRa Ebyte E220-400T22D (UART)

| E220 | XIAO ESP32-C6 | GPIO | Nota |
|---|---|---|---|
| TXD | D7 | GPIO17 | UART RX del nodo (`PIN_E220_RX`) |
| RXD | D8 | GPIO19 | UART TX del nodo (`PIN_E220_TX`), 9600 bps 8N1 |
| M0 | D10 | GPIO18 | Selección de modo |
| M1 | D9 | GPIO20 | Selección de modo |
| AUX | — | — | Sin conectar (no usado por firmware) |
| VCC | 3V3 | — | |
| GND | GND | — | |

### 1.2 Acondicionador MAX31865 (módulo tipo Adafruit, SPI por software)

| MAX31865 | XIAO ESP32-C6 | GPIO | Nota |
|---|---|---|---|
| CLK | D6 | GPIO16 | `PIN_SCK` |
| SDO | D5 | GPIO23 | `PIN_MISO` |
| SDI | D4 | GPIO22 | `PIN_MOSI` |
| CS | D3 | GPIO21 | `PIN_CS` |
| VIN | D2 | GPIO2 | `PIN_SENSOR_PWR`: el módulo se alimenta desde un GPIO para poder apagarlo en deep sleep |
| GND | GND | — | |
| RDY | — | — | Sin conectar |

Parámetros de firmware: `RREF = 421,1 Ω` (valor calibrado del módulo usado; el nominal típico de estos módulos es 430 Ω), `RNOMINAL = 100 Ω` (PT100).

### 1.3 Sonda PT100 de 3 hilos → bornes del MAX31865

Sonda: PT100 magnética de tres hilos marca ZUIDID, artículo 1005008619909588 de AliExpress: elemento de película delgada, sonda de 19 × 9,5 mm con tubo protector y funda de resorte, encapsulado en resina epoxi con silicona térmica, cable estándar de −60 a +200 °C y terminal en U de tres hilos. El vendedor no indica la clase de tolerancia; el presupuesto de incertidumbre de la tesis asume clase B.

- Puente **2/3-Wire** del módulo: soldado (modo 3 hilos).
- Los dos hilos del mismo extremo de la sonda → bornes **F+** y **RTD+**.
- El hilo restante → borne **RTD−** (unido a **F−** por el puente del módulo).

> Verificar contra el montaje físico real de los nodos; la referencia es la guía oficial del módulo Adafruit MAX31865.

### 1.4 Batería y medición de carga

| Elemento | Conexión |
|---|---|
| Batería LiPo (3,7 V, 1000 mAh) | BAT+ / BAT− → pads de batería del XIAO (regulador a bordo) |
| Módulo de carga/protección (tipo TP4056) | Entre la celda y los pads BAT del XIAO |
| Divisor resistivo | BAT+ → **R1 = 344,8 kΩ** → nodo A0 (GPIO0, `BAT_ADC_PIN`) → **R2 = 994,3 kΩ** → GND |

Factor del divisor: (R1+R2)/R2 ≈ 1,347 → 4,2 V de celda ≈ 3,12 V en el ADC.
Calibración en firmware: `BAT_CAL_K = 1,000`, `BAT_CAL_B = 0,090` (dejar como constantes ajustables: cada divisor real varía).

## 2. Gateway / visualizador (placa integrada ESP32-C6 Touch LCD 1.47)

La pantalla ST7789, el táctil y la ranura microSD vienen **integrados en la placa** (SPI: SCLK=GPIO1, MOSI=GPIO2, MISO=GPIO3, LCD_CS=GPIO14, DC=GPIO15, SD_CS=GPIO4; táctil I2C: SDA=GPIO18, SCL=GPIO19). En el esquemático se documentan solo las conexiones externas:

| Elemento externo | Placa gateway | GPIO | Nota |
|---|---|---|---|
| E220 TXD | — | GPIO8 | UART RX del gateway (`PIN_E220_RX`) |
| E220 RXD | — | GPIO7 | UART TX del gateway (`PIN_E220_TX`), 9600 bps 8N1 |
| E220 M0 **y** M1 | — | GPIO9 | Ambos pines del E220 unidos al mismo GPIO |
| E220 VCC / GND | 3V3 / GND | — | |
| Salida alarma crítica | — | GPIO16 | `PIN_ALARMA_CRITICA` (LED/buzzer/relé según instalación) |

## 3. Parámetros del enlace LoRa (ambos extremos)

| Parámetro | Valor |
|---|---|
| UART | 9600 bps, 8N1 |
| Tasa aérea | 2,4 kbps |
| Módulo | Ebyte E220-400T22D (LLCC68), 410,125 a 493,125 MHz, antena SMA |
| Canal | 23 → 433,125 MHz (frecuencia = 410,125 MHz + canal × 1 MHz; valor de fábrica) |
| Potencia | 22 dBm (código 0 de `AT+POWER`; valor de fábrica y máximo del módulo) |
| Sensibilidad (ficha) | −127 dBm típ. a 2,4 kbps (−126 a −129) |
| Consumo (ficha) | TX 110 mA típ. · RX 16,8 mA · sueño 5 µA |
| Modo | Transmisión fija (fixed), paquete 200 bytes |
| Direcciones | Maestro = 1 · Nodos = dirección propia (ej. 13) |

La rutina `configureE220()` del firmware escribe estos valores con comandos AT (`AT+ADDR`, `AT+CHANNEL=23`, `AT+RATE=2`, `AT+TRANS=1`, `AT+PACKET=0`, `AT+POWER=0`). Está desactivada en el arranque normal (`AUTO_CONFIGURE_ON_BOOT = false`), así que el módulo trabaja con los parámetros que tiene guardados; al reproducir el sistema, leerlos desde el módulo. Ficha: *E220-400T22D User Manual* (Ebyte).

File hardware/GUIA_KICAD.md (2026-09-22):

# Esquemáticos KiCad — SmartSense

Los esquemáticos **ya están generados y validados** (ERC de KiCad 10: 0 errores, 0 advertencias)
en `hardware/kicad/`:

| Archivo | Contenido |
|---|---|
| `nodo_sensor.kicad_sch` | Nodo: XIAO ESP32-C6 + MAX31865/PT100 + E220-433 + batería con divisor |
| `gateway.kicad_sch` | Gateway: placa ESP32-C6 Touch LCD 1.47 + E220-433 + salida de alarma |
| `smartsense.kicad_sym` | Biblioteca de símbolos propia (editable) |
| `nodo_sensor.pdf` / `gateway.pdf` | Exportes listos para usar como figuras del artículo |
| `svg/*.svg` | Los mismos exportes en vectorial |
| `gen_esquematicos.py` | Generador: produce todo lo anterior desde `CONEXIONES.md` |

Estilo: conexión por etiquetas de red (dos pines con la misma etiqueta están conectados),
que es como se documentan esquemáticos de módulos comerciales interconectados.

## Editar

Abrir el `.kicad_sch` con KiCad (instalado en `%LOCALAPPDATA%\Programs\KiCad\10.0`) y retocar
lo que se quiera — son archivos normales de KiCad. Si el cambio es de conexiones, mejor editar
`gen_esquematicos.py` y regenerar, para que `CONEXIONES.md`, el script y el dibujo no se
desincronicen:

```bash
cd hardware/kicad
python gen_esquematicos.py
kicad-cli sch erc nodo_sensor.kicad_sch     # debe dar 0 errores
kicad-cli sch export pdf -o nodo_sensor.pdf nodo_sensor.kicad_sch
```

(`kicad-cli` está en `%LOCALAPPDATA%\Programs\KiCad\10.0\bin\`.)

## Qué se publica en Zenodo (design files del artículo)

Publicado: versión `v1.0-tesis`, DOI 10.5281/zenodo.22903028 (22 de septiembre de 2026).

- Carpeta `hardware/kicad/` completa (proyecto editable — requisito OSHWA/HardwareX).
- PDF/SVG del esquemático.
- `BOM.csv` (esta carpeta).
- STL + fuente CAD de la carcasa PLA (agregar cuando estén).
- Firmware (los tres sketches de la versión LoRa, ya sin credenciales).

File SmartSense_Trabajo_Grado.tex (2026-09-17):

\documentclass[11pt,letterpaper,oneside]{report}
\usepackage[utf8]{inputenc}
\usepackage[T1]{fontenc}
\usepackage[spanish,es-nodecimaldot]{babel}
\addto\captionsspanish{\renewcommand{\tablename}{Tabla}\renewcommand{\listtablename}{Índice de tablas}}
\usepackage{newtxtext,newtxmath}
\usepackage[top=2.8cm,bottom=2.35cm,left=2.54cm,right=2.54cm]{geometry}
\usepackage{setspace,graphicx,booktabs,tabularx,array,longtable}
% Tectonic's current newtxmath and amssymb packages both define \Bbbk.
\let\Bbbk\relax
\usepackage{amsmath,amssymb,siunitx,xcolor,url}
% Absolute page anchors stay unique across title pages and numbering changes.
\usepackage[hidelinks,hypertexnames=false]{hyperref}
\usepackage[round,authoryear]{natbib}
\renewcommand{\bibsection}{\chapter*{Referencias bibliográficas}\addcontentsline{toc}{chapter}{Referencias bibliográficas}}
\graphicspath{{figuras/}}
\sisetup{output-decimal-marker={,}}
\input{tesis/datos-evidencia}

\begin{document}
\onehalfspacing
\pagenumbering{gobble}
\input{tesis/preliminares/portada}
\input{tesis/preliminares/agradecimientos}
\input{tesis/preliminares/resumen}
\pagenumbering{roman}
\tableofcontents
\listoffigures
\listoftables
\clearpage
\pagenumbering{arabic}
\input{tesis/capitulos/01-introduccion}
\input{tesis/capitulos/02-planteamiento-problema}
\input{tesis/capitulos/03-objetivos}
\input{tesis/capitulos/04-estado-arte}
\input{tesis/capitulos/05-marco-referencia}
\input{tesis/capitulos/06-diseno-metodologico}
\input{tesis/capitulos/06b-fundamentos}
\input{tesis/capitulos/07-desarrollo-implementacion}
\input{tesis/capitulos/08-resultados-evidencias}
\input{tesis/capitulos/09-discusion-limitaciones}
\input{tesis/capitulos/10-conclusiones}
\bibliographystyle{apalike}
\bibliography{tesis/referencias}
\clearpage
\appendix
\input{tesis/anexos/anexos}
\end{document}

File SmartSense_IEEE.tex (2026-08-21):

\documentclass[conference]{IEEEtran}

\usepackage[utf8]{inputenc}
\usepackage[T1]{fontenc}
\usepackage[spanish,es-nodecimaldot]{babel}
\usepackage{cite}
\usepackage{amsmath,amssymb}
\usepackage{graphicx}
\usepackage{booktabs}
\usepackage{tabularx}
\usepackage{array}
\usepackage{xcolor}
\usepackage{url}
\usepackage[hidelinks]{hyperref}
\usepackage{siunitx}
\usepackage{microtype}

\graphicspath{{figuras/}}
\sisetup{output-decimal-marker={,}}

\newcommand{\figpendiente}[2]{%
  \begin{figure}[!t]
    \centering
    \fbox{\parbox[c][3.2cm][c]{0.92\columnwidth}{%
      \centering\small\textit{Insertar: #1}}}
    \caption{#2}
    \label{fig:#1}
  \end{figure}}

\title{SmartSense Monitoring: Sistema Inalámbrico para el Monitoreo y Análisis Histórico de Temperatura en Equipos Industriales}

\author{
\IEEEauthorblockN{Jesus Andre Bojaca Lopez y David Santiago Puentes Cárdenas}
\IEEEauthorblockA{
Programa de Ingeniería Electrónica, Facultad de Ingeniería\\
Universidad ECCI, Bogotá D.C., Colombia\\
\{jesusa.bojacal, davids.puentesc\}@ecci.edu.co\\[3pt]
\textit{Tutores:} Prof. Jhon Edwin Vera y Prof. Sergio Francisco Mora Martínez}
}

\begin{document}

\maketitle

\begin{abstract}
Este artículo presenta el diseño, implementación y evaluación preliminar de SmartSense Monitoring, un sistema inalámbrico para medir temperatura superficial en equipos de una planta piloto. La solución está compuesta por nodos con microcontrolador XIAO ESP32-C6, sondas PT100 de tres hilos, acondicionadores MAX31865, alimentación mediante batería y comunicación LoRa con módulos Ebyte E220. Un gateway con ESP32-C6 recibe las mediciones, las almacena en una tarjeta microSD y las presenta mediante una pantalla local y un dashboard web. A diferencia de una inspección manual puntual, la solución conserva el comportamiento térmico durante las 24 horas, permite consultar días anteriores, comparar sensores, aplicar compensaciones de temperatura y configurar alarmas. Durante la validación en planta, el histórico permitió observar un incremento de temperatura en el motor de un succionador después de la parada de la máquina; el comportamiento se relacionó posteriormente con una condición anómala de los rodamientos. El sistema se comparó cualitativamente con una pistola de temperatura Fluke y con un sensor Advantech WISE-2410 en la configuración disponible en planta. Los resultados funcionales verificaron la adquisición, transmisión, almacenamiento, visualización histórica, compensación y gestión de alarmas. A partir de un registro real de 32 días con tres nodos (\num{51338} muestras), la disponibilidad del enlace superó el \SI{97}{\percent} una vez descontadas las paradas de planta. La evaluación cuantitativa de exactitud, autonomía y latencia se completará con las pruebas controladas correspondientes.
\end{abstract}

\begin{IEEEkeywords}
Internet de las cosas industrial, LoRa, PT100, MAX31865, monitoreo de temperatura, monitoreo de condición, dashboard, ESP32-C6.
\end{IEEEkeywords}

\section{Introducción}

El seguimiento de temperatura en motores y otros equipos industriales permite identificar cambios asociados con fricción, sobrecarga, ventilación deficiente o degradación mecánica. En una inspección manual, el operario obtiene únicamente el valor correspondiente al instante de la medición. Si este valor no se registra de manera sistemática, no es posible reconstruir la evolución térmica del equipo ni relacionarla con sus ciclos de operación y parada.

Las redes de sensores inalámbricos permiten distribuir puntos de medición sin instalar cableado de comunicación en cada ubicación \cite{akyildiz2002,yick2008,mois2017}. Para aplicaciones de baja tasa de datos, LoRa ofrece una alternativa de largo alcance y bajo consumo adecuada para nodos alimentados por batería, cuyo alcance y escalabilidad se han caracterizado experimentalmente \cite{centenaro2016,semtech2015,augustin2016,bor2016}. Diversos trabajos han empleado LoRa para el monitoreo de temperatura y de condición en entornos industriales y de infraestructura \cite{polonelli2019,jakobsen2024}. Asimismo, se han publicado plataformas de hardware abierto y bajo costo para el monitoreo de temperatura \cite{higroterm2021,jakobsen2024}, aunque frecuentemente orientadas a sensores ambientales tipo DHT y no a sondas RTD industriales como la PT100. El seguimiento continuo de variables como la temperatura constituye la base del monitoreo de condición (\textit{condition monitoring}) que sustenta el mantenimiento basado en condición en la Industria 4.0 \cite{cinar2020,jardine2006}. Es importante precisar que este trabajo aporta la plataforma de \emph{adquisición y monitoreo} de temperatura; no implementa ni valida un algoritmo de mantenimiento predictivo. Estas características se aprovecharon en SmartSense Monitoring para construir una plataforma local, modular y configurable.

El propósito del proyecto fue implementar y validar un sistema capaz de medir temperatura superficial, transmitirla de manera inalámbrica, conservar un histórico por sensor y facilitar el análisis del comportamiento térmico. El trabajo evolucionó desde un anteproyecto hasta un prototipo funcional instalado en una planta piloto. Por tanto, este documento describe las actividades realizadas y los resultados evidenciados, en lugar de presentar únicamente resultados esperados.

Aunque las redes de sensores inalámbricos, la tecnología LoRa y los sensores RTD son tecnologías conocidas, la revisión del estado del arte muestra que su integración suele orientarse a variables ambientales y depender de plataformas en la nube. El aporte de este trabajo no fue inventar un componente nuevo, sino el \emph{diseño y la validación experimental de una arquitectura inalámbrica de bajo costo para el monitoreo térmico superficial distribuido en una planta piloto}, que integra adquisición RTD industrial (PT100/MAX31865), comunicación LoRa, alimentación autónoma y visualización local, y que evalúa simultáneamente el desempeño de comunicación, la medición y la autonomía bajo condiciones reales de operación.

En términos concretos, las contribuciones fueron: 1) integración de nodos PT100 de tres hilos con comunicación LoRa y operación por batería; 2) almacenamiento diario con respaldo local que opera sin Internet; 3) dashboard de 24 horas con comparación de sensores; 4) compensación configurable de temperatura; y 5) alarmas térmicas visuales, sonoras y mediante salida física. La validación se apoyó en un despliegue real de 32 días en la planta.

\section{Arquitectura del sistema}

La arquitectura implementada, mostrada en la Fig.~\ref{fig:arquitectura-detalle}, está formada por nodos sensores, un enlace LoRa, un gateway y clientes locales conectados por Wi-Fi. Cada nodo adquiere la temperatura y el estado estimado de batería mediante la cadena PT100~$\rightarrow$~MAX31865~$\rightarrow$~ESP32-C6, y transmite por LoRa de 433~MHz al gateway. El gateway recibe las tramas, identifica el nodo, aplica la compensación configurada, almacena la muestra y actualiza la pantalla local y el dashboard web.

\begin{figure*}[!t]
  \centering
  
  \caption{Cadena de señal por nodo y flujo de datos. Cada uno de los tres nodos ejecuta la cadena PT100 (tres hilos)~$\rightarrow$~MAX31865~$\rightarrow$~ESP32-C6, con alimentación por batería, y transmite por LoRa de 433~MHz al gateway. El gateway presenta la lectura en la pantalla local y sirve el dashboard web con el histórico por Wi-Fi local.}
  \label{fig:arquitectura-detalle}
\end{figure*}

\subsection{Nodo sensor}

Cada nodo fue construido con un Seeed Studio XIAO ESP32-C6, una sonda PT100 magnética de tres hilos, un MAX31865, una batería LiPo y un módulo Ebyte E220. La PT100 empleada es de tolerancia Clase~B según la norma IEC~60751 (\SI{\pm 0.3}{\celsius} a \SI{0}{\celsius}), en encapsulado magnético para montaje sobre superficies; su referencia exacta de fabricante se detalla en la lista de materiales publicada. El MAX31865 fue configurado mediante la biblioteca de Adafruit en el modo \texttt{MAX31865\_3WIRE}. Se utilizó una resistencia nominal de \SI{100}{\ohm} y una resistencia de referencia caracterizada en \SI{421.1}{\ohm}.

Se optó por una sonda PT100 en lugar de un sensor digital como el DS18B20 por varias razones. La PT100 es el estándar en instrumentación industrial (IEC~60751), con excelente estabilidad a largo plazo y baja deriva, lo que favorece un monitoreo prolongado. Su naturaleza resistiva permite un acondicionamiento analógico preciso: el MAX31865 es un convertidor RTD-a-digital diseñado específicamente para PT100 de dos, tres y cuatro hilos, con compensación de la resistencia de los conductores. La PT100 ofrece además un rango mucho más amplio (\SIrange{-200}{850}{\celsius}) que el DS18B20 (\SIrange{-55}{125}{\celsius}), adecuado para superficies industriales que pueden acercarse o superar el límite del sensor digital, y está disponible en encapsulados de superficie y magnéticos apropiados para el montaje sobre motores. En conjunto ---estabilidad, comportamiento industrial, precisión, rango, naturaleza resistiva, acondicionamiento y compatibilidad con el MAX31865--- estas características la hacen preferible para el monitoreo de temperatura superficial de equipos.

En cada ciclo se efectuaron varias conversiones de temperatura y se descartaron valores inválidos. El firmware también consultó el registro de fallas del MAX31865 para detectar problemas de conexión o lecturas fuera de rango. La tensión de batería se obtuvo mediante el convertidor analógico-digital del ESP32-C6 y un divisor resistivo. El porcentaje estimado se calculó entre \SI{3.30}{\volt} y \SI{4.10}{\volt}.

La trama de aplicación incluyó el identificador del nodo, temperatura, porcentaje de batería y dirección MAC. Después de la transmisión, el nodo ingresó en sueño profundo. El periodo puede configurarse entre 5 y 7200 segundos; durante el despliegue evaluado se utilizó un intervalo de 120 segundos (mediana medida de 121 s).

La Fig.~\ref{fig:esquematico-nodo} presenta el esquemático de conexiones del nodo: la interfaz SPI hacia el MAX31865, el enlace UART hacia el módulo E220, la alimentación del acondicionador conmutada por un pin digital para reducir el consumo durante el sueño profundo, y el divisor resistivo utilizado para estimar la carga de la batería.

\begin{figure*}[!t]
  \centering
  
  \caption{Esquemático de conexiones del nodo sensor: XIAO ESP32-C6, acondicionador MAX31865 con sonda PT100 de tres hilos, módulo LoRa Ebyte E220-433, circuito de carga y divisor resistivo para la estimación de batería. Los saltos largos se indican con etiquetas de red (VBAT, GND, VBAT\_SENSE).}
  \label{fig:esquematico-nodo}
\end{figure*}

\subsection{Comunicación LoRa}

La comunicación se implementó con módulos UART Ebyte E220 configurados mediante comandos AT. Se utilizó direccionamiento fijo, un canal común para los nodos y el gateway, velocidad serial de 9600 bit/s y velocidad aérea de 2,4 kbit/s. La dirección MAC identifica de manera persistente cada sensor, mientras que la dirección de radio permite encaminar los mensajes.

El firmware del gateway posee un campo reservado para RSSI, pero la versión revisada no habilita ni procesa dicho valor desde el E220. Tampoco se procesa la relación señal-ruido (SNR). En consecuencia, estas variables no se presentan como resultados experimentales del prototipo actual.

\subsection{Gateway y persistencia}

El gateway fue implementado con un ESP32-C6, pantalla táctil con controlador ST7789, módulo E220 y tarjeta microSD. La tarjeta se utiliza como medio principal para los históricos. Si no está disponible, LittleFS funciona como respaldo.

Para cada dirección MAC se crea un directorio independiente y un archivo por fecha en la microSD (con LittleFS como respaldo). Cada línea contiene el segundo transcurrido desde el inicio del día y la temperatura representada con resolución de \SI{0.1}{\celsius}. El firmware conserva una ventana móvil de 30 días por sensor: al superarse la capacidad, se eliminan los días más antiguos. El registro de 32 días analizado en este trabajo corresponde al archivo CSV exportado del gateway antes de dicha rotación, por lo que no existe conflicto entre la ventana de 30 días y la duración del despliegue. La hora se sincroniza desde el navegador y se ajusta a la zona horaria UTC--5, por lo cual el sistema puede trabajar localmente sin conexión permanente a Internet.

La Fig.~\ref{fig:esquematico-gateway} resume las conexiones externas del gateway. La pantalla, el panel táctil y la ranura microSD están integrados en la placa; las conexiones agregadas corresponden al módulo E220 por UART, con las líneas de modo M0 y M1 unidas a un mismo pin, y a la salida digital para la señalización de alarma crítica.

\begin{figure*}[!t]
  \centering
  
  \caption{Esquemático de conexiones externas del gateway/visualizador: placa ESP32-C6 con pantalla táctil, módulo LoRa Ebyte E220-433 y salida de alarma crítica.}
  \label{fig:esquematico-gateway}
\end{figure*}

\section{Dashboard y funciones de supervisión}

El gateway crea el punto de acceso Wi-Fi \texttt{Sensores\_Temp} y publica el dashboard en la dirección local \texttt{192.168.4.1}. La actualización de los datos se realiza mediante eventos enviados por el servidor aproximadamente cada segundo.

La interfaz implementada permite visualizar temperatura, batería y conectividad; consultar fechas disponibles; representar las 24 horas; obtener mínimo, máximo y promedio; comparar sensores de una misma máquina; asignar nombres; configurar el intervalo de muestreo; aplicar compensaciones; y establecer umbrales de advertencia y condición crítica.

La Fig.~\ref{fig:dashboard-principal} muestra nueve sensores registrados y organizados en cinco grupos: Twin, Molino 1, Empaque A, Cuarto Frío y sensores aún sin asignar. Cada tarjeta presenta la última temperatura, batería, estado de conexión, intervalo térmico y una minigráfica. La agrupación permite comparar sensores pertenecientes a una misma máquina y reduce el tiempo necesario para localizar una condición anómala. La interfaz también integra accesos a emergencias, configuración y selección del diseño visual.

\begin{figure*}[!t]
  \centering
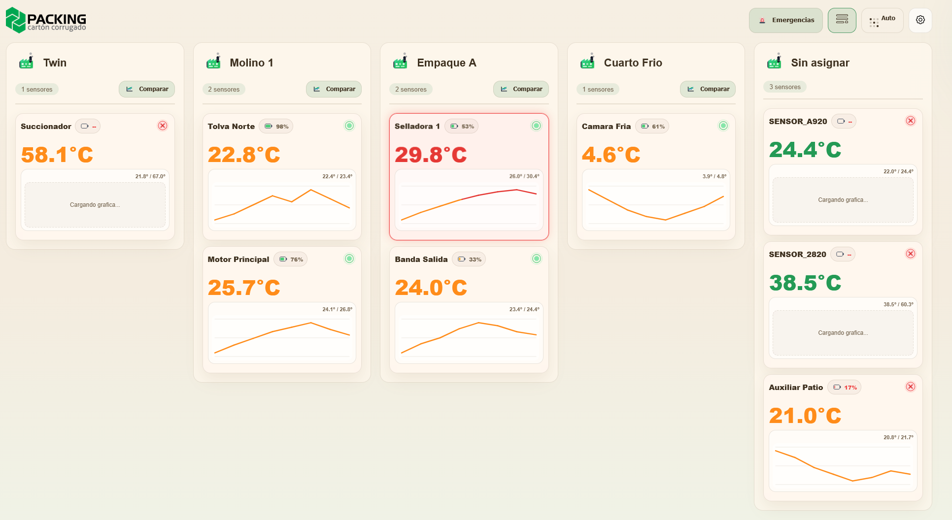
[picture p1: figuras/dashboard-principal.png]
  
  \caption{Interfaz principal de SmartSense Monitoring con los sensores agrupados por máquina. La captura evidencia la supervisión simultánea de nueve registros y la presentación de temperatura, batería, conectividad y tendencia reciente.}
  \label{fig:dashboard-principal}
\end{figure*}

\subsection{Compensación de temperatura}

Para aproximar la lectura de cada PT100 al instrumento de referencia se implementó una compensación configurable. El usuario captura una referencia en condición fría y posteriormente establece un ajuste en condición caliente. Entre ambos puntos, el firmware aplica una compensación progresiva.

Si $T_r$ es la temperatura cruda, $T_f$ la referencia fría, $T_c$ el punto de calibración caliente y $O$ el offset establecido, la compensación dentro del intervalo puede expresarse como

\begin{equation}
T_{corr}=T_r+O\left(\frac{T_r-T_f}{T_c-T_f}\right),
\label{eq:offset}
\end{equation}

limitando el factor de interpolación entre cero y uno. Por debajo de la referencia fría no se aplica corrección y, por encima del punto caliente, se aplica el offset completo.

\subsection{Alarmas}

Cada nodo posee un umbral de advertencia y un umbral crítico configurables. Al superar el primero, el dashboard cambia la representación visual. Al superar el segundo, se activa el estado crítico, una alarma sonora opcional en el navegador y la salida física definida en el gateway. El usuario puede silenciar la alarma sin eliminar el registro del evento.

La arquitectura permite integrar posteriormente módulos de relés o variables de control. Sin embargo, cualquier acción automática sobre maquinaria debe diferenciarse de las alarmas ya verificadas y validarse bajo criterios de seguridad industrial.

\section{Metodología de evaluación}

La validación se estructuró en cuatro etapas. Primero se verificó la lectura de las PT100 y el reporte de fallas del MAX31865. Luego se comprobó el envío de tramas y la identificación de los nodos. En la tercera etapa se validaron el almacenamiento, la consulta por fecha y las funciones del dashboard. Finalmente, el sistema se instaló temporalmente en equipos de la planta para observar el comportamiento térmico durante la operación.

\subsection{Instrumento de referencia}

El instrumento de referencia empleado fue un termómetro infrarrojo \textbf{Fluke 62 MAX}, con rango de \SIrange{-30}{500}{\celsius}, exactitud de \SI{\pm 1.5}{\celsius} o \SI{\pm 1.5}{\percent} de la lectura (el mayor de ambos), repetibilidad de \SI{\pm 0.8}{\celsius}, relación distancia-punto de 10:1, respuesta espectral de \SIrange{8}{14}{\micro\meter} y emisividad fija de \num{0.95}. La medición es sin contacto sobre la superficie del equipo.

El instrumento se empleó como \emph{referencia de campo} y no dispuso de un certificado de calibración vigente, lo que constituye una limitación reconocida. Deben señalarse además dos limitaciones metodológicas que condicionan la comparación. Primero, la exactitud del propio Fluke (\SI{\pm 1.5}{\celsius}) es mayor que el criterio de error objetivo del sistema (\SI{\pm 1}{\celsius}); por lo tanto, sirve para verificar la coherencia de las lecturas, pero una validación estricta de \SI{\pm 1}{\celsius} requeriría un patrón de menor incertidumbre y con calibración trazable (por ejemplo, una sonda de contacto o RTD de referencia calibrada). Segundo, la emisividad fija de \num{0.95} y la naturaleza sin contacto introducen error adicional frente a la medición por contacto de la PT100, en especial sobre superficies metálicas. Por estas razones, los resultados se reportan como \emph{diferencia respecto al instrumento de referencia} y no como una calibración formal.

La comparación se realizó tomando muestras pareadas de forma simultánea y en el mismo punto de la superficie del motor del succionador. Se registraron cinco parejas de lecturas (Tabla~\ref{tab:mediciones}) en el rango de \SIrange{65}{71}{\celsius}, correspondiente a la condición caliente del motor. Se reconoce como limitación que la comparación se concentró en un nodo y en un rango de temperatura estrecho; una caracterización más completa debería abarcar los tres nodos de forma simultánea y un rango más amplio, desde temperatura ambiente hasta la máxima de operación. Para $n$ pares de datos, el error absoluto medio se calculó mediante

\begin{equation}
\mathrm{MAE}=\frac{1}{n}\sum_{i=1}^{n}\left|T_{SS,i}-T_{ref,i}\right|.
\label{eq:mae}
\end{equation}

A partir del registro se calcularon la temperatura mínima, máxima y promedio por sensor. Las mediciones pareadas frente al Fluke 62 MAX se muestran en la Tabla~\ref{tab:mediciones}: las lecturas del SmartSense coincidieron con la referencia dentro de \SI{\pm 0.4}{\celsius}, con una diferencia media cercana a \SI{0.1}{\celsius}. No obstante, como el offset del sistema se ajustó con el mismo Fluke y la exactitud de este es \SI{\pm 1.5}{\celsius}, esta comparación demuestra que la compensación funciona y que el sistema reproduce la referencia, pero no constituye una validación independiente de exactitud \SI{\leq 1}{\celsius}; para ello se requeriría un patrón de contacto calibrado (termocupla o RTD de referencia).

\begin{table}[!t]
\caption{Formato de medición pareada en planta}
\label{tab:mediciones}
\centering
\footnotesize
\begin{tabular}{@{}lccc@{}}
\toprule
Hora & SmartSense & Fluke 62 MAX & $|\Delta|$ \\
 & (\si{\celsius}) & (\si{\celsius}) & (\si{\celsius}) \\
\midrule
06:40 & 71,0 & 71,0 & 0,0 \\
07:06 & 70,6 & 70,6 & 0,0 \\
07:58 & 69,7 & 69,6 & 0,1 \\
08:09 & 69,5 & 69,4 & 0,1 \\
09:49 & 65,1 & 65,2 & 0,1 \\
\bottomrule
\end{tabular}
\end{table}

\section{Comparación con métodos disponibles}

\subsection{Medición manual con pistola Fluke}

En el primer escenario, un operario se desplaza hasta el equipo y obtiene una lectura puntual. Por ejemplo, una medición de \SI{60}{\celsius} en el motor del succionador describe únicamente el instante de la inspección. El procedimiento resulta útil como verificación directa, pero depende de la disponibilidad del operario y no conserva automáticamente la evolución anterior y posterior.

\subsection{Advantech WISE-2410}

El WISE-2410 disponible en la planta es un dispositivo industrial de monitoreo de condición que integra acelerómetro de tres ejes, temperatura, procesamiento local y LoRaWAN \cite{wise2410}. Su capacidad de medir vibración constituye una ventaja para el diagnóstico mecánico.

La comparación de visualización se restringió a la configuración y plataforma disponibles en la planta. En esta implementación, el equipo de trabajo observó una ventana temporal limitada y no dispuso de la misma flexibilidad para ajustar la lectura térmica o consultar directamente un día completo. Esta observación no se presenta como una limitación general del WISE-2410, pues sus capacidades dependen del gateway, servidor y aplicación empleados.

\subsection{SmartSense Monitoring}

SmartSense presentó el historial de la fecha seleccionada sobre un eje de 24 horas, compensación independiente por nodo, comparación entre sensores y umbrales configurables. Además, funcionó mediante una red local sin depender de servicios externos.

\begin{table*}[!t]
\caption{Comparación cualitativa de los métodos evaluados}
\label{tab:comparacion}
\centering
\footnotesize
\begin{tabularx}{\textwidth}{@{}p{2.8cm}XXX@{}}
\toprule
\textbf{Criterio} & \textbf{Pistola Fluke} & \textbf{WISE-2410 evaluado} & \textbf{SmartSense Monitoring} \\
\midrule
Adquisición & Puntual y manual & Automática y periódica & Automática y periódica \\
Dependencia del operario & Alta & Baja & Baja \\
Histórico & Requiere registro externo & Depende de la plataforma instalada & Archivo diario por sensor \\
Visualización observada & Un valor instantáneo & Ventana disponible en planta & Fecha seleccionable y 24 horas \\
Ajuste térmico & Depende del instrumento & No disponible para el equipo en la interfaz evaluada & Offset configurable por nodo \\
Alarmas & No incorporadas & Dependen de la integración & Advertencia, crítica, visual y sonora \\
Comparación entre sensores & No & Depende de la plataforma & Incluida en el dashboard \\
Variables & Temperatura & Vibración y temperatura & Temperatura, batería, conexión y alarmas \\
Operación sin Internet & Sí & Depende de la arquitectura & Sí, mediante servidor local \\
\bottomrule
\end{tabularx}
\end{table*}

\section{Resultados obtenidos}

\subsection{Criterios de aceptación y resultados}

La Tabla~\ref{tab:criterios} contrasta cada criterio de aceptación definido para el proyecto con el resultado obtenido. La disponibilidad del enlace, el PDR y la pérdida de paquetes se determinaron a partir del registro real de 32 días; el error de temperatura, con las mediciones pareadas frente al Fluke; la recuperación tras reinicio, a partir del tiempo activo por ciclo; y la autonomía, mediante una prueba de descarga de batería. Únicamente la latencia se deja como trabajo futuro, por requerir sincronización de reloj. Cada resultado indica en la nota de la tabla su método y sus salvedades; ninguno se declara cumplido sin evidencia.

\begin{table}[!t]
\caption{Criterios de aceptación frente a resultados obtenidos}
\label{tab:criterios}
\centering
\footnotesize
\begin{tabularx}{\columnwidth}{@{}Xccc@{}}
\toprule
\textbf{Métrica} & \textbf{Criterio} & \textbf{Resultado} & \textbf{¿Cumple?} \\
\midrule
Disponibilidad del enlace & $\geq$\,\SI{95}{\percent} & \SIrange{97.8}{98.4}{\percent} & Sí \\
PDR & $\geq$\,\SI{95}{\percent} & \SIrange{95.3}{96.6}{\percent}$^{a}$ & Sí \\
Pérdida de paquetes & $\leq$\,\SI{5}{\percent} & \SIrange{3.5}{4.7}{\percent}$^{a}$ & Sí \\
Latencia promedio & $\leq$\,\SI{5}{\second} & Trabajo futuro$^{b}$ & -- \\
Error de temperatura & $\leq$\,\SI{1}{\celsius} & $\leq$\,\SI{0.4}{\celsius} vs Fluke$^{c}$ & Sí* \\
Autonomía & $\geq$\,\SI{8}{\hour} & $\approx$\,\num{177}\,d$^{d}$ & Sí \\
Recuperación (reinicio) & $\leq$\,\SI{120}{\second} & \SI{2.279}{\second}$^{e}$ & Sí \\
\bottomrule
\end{tabularx}
\vskip 0.15cm
{\footnotesize $^{a}$Estimado por análisis de intervalos de llegada (Sección~\ref{sec:perdida}); se confirmará con el contador de secuencia por nodo incorporado al firmware. $^{b}$No medida; requiere sincronización de reloj nodo--gateway. Se deja como trabajo futuro. $^{c}$Diferencia respecto al Fluke 62 MAX (Tabla~\ref{tab:mediciones}). *Concordancia dentro de la incertidumbre del propio Fluke (\SI{\pm 1.5}{\celsius}); como el offset se ajustó con ese instrumento, no es una validación independiente. $^{d}$Prueba de descarga de \num{5} días con batería de \SI{1000}{\milli\ampere\hour}, extrapolada al voltaje de corte (Sección~\ref{sec:autonomia}); cota inferior conservadora. $^{e}$Tiempo desde el reinicio del nodo hasta transmitir el primer paquete (igual al tiempo activo por ciclo). La recuperación ante bloqueo del enlace es una caracterización complementaria.}
\end{table}

La Tabla~\ref{tab:resultados} resume las funciones verificadas mediante revisión del firmware y pruebas funcionales del prototipo.

\subsection{Disponibilidad y diferencia con el PDR}

Conviene distinguir dos indicadores que a menudo se confunden. El \emph{PDR} (\textit{packet delivery ratio}) mide el desempeño del \emph{enlace}: es la razón entre paquetes recibidos y paquetes enviados por el nodo, y requiere un contador de secuencia en la trama para conocer cuántos se enviaron. La \emph{disponibilidad de datos} mide la fracción de mediciones efectivamente disponibles para el usuario respecto de las esperadas según el intervalo de muestreo. En este sistema ambos indicadores son numéricamente cercanos, salvo cuando el gateway estuvo apagado: esos periodos reducen la disponibilidad cruda pero no representan fallas del enlace, por lo que se contabilizan por separado.

\subsection{Pérdida de paquetes}
\label{sec:perdida}

Dado que el registro histórico no incluía un contador de secuencia, la pérdida de paquetes se estimó a partir de los intervalos entre llegadas. El ciclo de muestreo nominal fue de \SI{120}{\second}. Dentro de los tramos activos (excluyendo los periodos de gateway apagado, identificados por intervalos mayores a \SI{30}{\minute}), un intervalo cercano a $k$ veces el ciclo indica que faltaron $k-1$ paquetes entre dos recepciones consecutivas. El número de paquetes esperados se obtiene entonces como la suma de recibidos más los inferidos como perdidos.

Con este criterio, la pérdida estimada fue de \SI{3.45}{\percent} en el Nodo~A, \SI{3.93}{\percent} en el Nodo~B y \SI{4.68}{\percent} en el Nodo~C, equivalente a un PDR estimado entre \SI{95.3}{\percent} y \SI{96.6}{\percent}. Los tres nodos cumplen el criterio de pérdida $\leq$\,\SI{5}{\percent} y de PDR $\geq$\,\SI{95}{\percent}. Estos valores, obtenidos por inferencia temporal, se confirmarán con la medición directa de enviados y recibidos mediante el contador de secuencia incorporado al firmware.

\subsection{Prueba representativa de 60 minutos}
\label{sec:prueba60}

El protocolo de validación definió una prueba continua mínima de 60 minutos. El despliegue de 32 días contiene numerosas ventanas equivalentes; la Fig.~\ref{fig:prueba60} presenta una ventana representativa de una hora (10 de mayo de 2026, 00:00--01:00) con los tres nodos activos, y la Tabla~\ref{tab:prueba60} resume sus indicadores. En \SI{60}{\minute}, a un ciclo de \SI{120}{\second}, se esperaban \num{30} paquetes por nodo; se recibieron 29, 30 y 30, con un PDR de \SIlist{96.7;100;100}{\percent}.

\begin{figure}[!t]
  \centering
  
  \caption{Ventana representativa de 60 minutos del despliegue: temperatura de los tres nodos (10 de mayo de 2026, 00:00--01:00), durante el enfriamiento nocturno de las máquinas.}
  \label{fig:prueba60}
\end{figure}

\begin{table}[!t]
\caption{Indicadores de la ventana de 60 minutos}
\label{tab:prueba60}
\centering
\footnotesize
\begin{tabularx}{\columnwidth}{@{}Xcccc@{}}
\toprule
\textbf{Nodo} & \textbf{Esperados} & \textbf{Recibidos} & \textbf{Perdidos} & \textbf{PDR} \\
\midrule
Nodo A & 30 & 29 & 1 & \SI{96.7}{\percent} \\
Nodo B & 30 & 30 & 0 & \SI{100}{\percent} \\
Nodo C & 30 & 30 & 0 & \SI{100}{\percent} \\
\bottomrule
\end{tabularx}
\end{table}

En esta ventana se registraron la temperatura y el PDR (recibidos frente a esperados). La batería se caracterizó por separado en la prueba de descarga (Sección~\ref{sec:autonomia}) y la recuperación tras reinicio fue de \SI{2.279}{\second}. En el registro del despliegue de 32 días no se habilitó el \textbf{RSSI}; posteriormente se incorporó al firmware y se midió en la prueba de alcance (Sección~\ref{sec:alcance}). El \textbf{SNR} no lo expone el módulo E220 y la \textbf{latencia} extremo a extremo requiere sincronización de reloj entre el nodo y el gateway; ambos se dejan como trabajo futuro. Para obtener el PDR con conteo directo de enviados y recibidos, se incorporó al firmware un contador de secuencia por nodo que permite repetir la prueba de forma instrumentada.

\subsection{Prueba de alcance al aire libre}
\label{sec:alcance}

El 20 de agosto de 2026 se realizó una prueba de alcance en exteriores, en un entorno urbano con edificios entre el nodo y el gateway (sin línea de vista directa). El nodo se alejó del gateway hasta aproximadamente \SI{688}{\meter} y regresó, registrando el RSSI y la batería de cada paquete (Fig.~\ref{fig:distancia}). El RSSI descendió desde cerca de \SI{-15}{dBm} junto al gateway hasta aproximadamente \SI{-98}{dBm} en el punto más lejano (ventana 20:44--20:54). En ese punto el enlace seguía entregando paquetes válidos con margen respecto al umbral de sensibilidad de LoRa (típicamente inferior a \SI{-120}{dBm}); la prueba se detuvo de forma voluntaria y no por pérdida del enlace, por lo que \SI{688}{\meter} constituye una cota inferior del alcance, tanto más destacable por tratarse de una trayectoria obstruida. La batería se mantuvo alrededor del \SI{94}{\percent} durante las \SI{2.6}{\hour} de la prueba, coherente con el bajo ciclo de trabajo y con la autonomía estimada. La medición se hizo desplazándose y no a distancias fijas controladas, por lo que la curva refleja el recorrido; una caracterización RSSI--distancia con posiciones fijas queda como trabajo futuro.

\begin{figure}[!t]
  \centering
  
  \caption{Prueba de alcance con obstrucciones (20 de agosto de 2026, edificios de por medio): RSSI (azul) y batería (verde) frente al tiempo, mientras el nodo se alejaba del gateway y regresaba. En el punto más lejano ($\approx$\SI{688}{\meter}) el RSSI llegó a $\approx$\SI{-98}{dBm} con el enlace aún operativo y con margen.}
  \label{fig:distancia}
\end{figure}

\subsection{Tiempo activo por ciclo}

El tiempo activo por ciclo ---desde el arranque del nodo hasta completar la lectura y la transmisión, inmediatamente antes de entrar en sueño profundo--- se midió a partir del registro del firmware. En diez arranques consecutivos, el valor fue de \SI{2.279}{\second} en ocho de las diez muestras, con variaciones menores en las restantes. Con un ciclo de muestreo de \SI{120}{\second}, este tiempo corresponde a un ciclo de trabajo (fracción de tiempo activo) de aproximadamente \SI{1.9}{\percent}.

Dado este bajo ciclo de trabajo, el nodo permanece en sueño profundo el \SI{98.1}{\percent} del tiempo y solo consume una corriente apreciable durante el pico activo. Esta característica determina la autonomía, que se estimó experimentalmente en la Sección~\ref{sec:autonomia}.

Este mismo tiempo activo define la \emph{recuperación tras un reinicio del nodo}: al restablecerse la alimentación, el nodo arranca, adquiere y transmite el primer paquete en aproximadamente \SI{2.279}{\second}, muy por debajo del criterio de \SI{120}{\second}. La recuperación ante un bloqueo del enlace mientras el nodo permanece activo (sin reinicio) corresponde a un ciclo de muestreo y se plantea como caracterización complementaria.

\subsection{Autonomía: prueba de descarga}
\label{sec:autonomia}

Para estimar la autonomía se realizó una prueba de descarga con una batería de \SI{1000}{\milli\ampere\hour}, registrando el voltaje del nodo en operación normal. Entre el 13 y el 18 de agosto de 2026 (\SI{120}{\hour}) el voltaje descendió de \SI{4.112}{\volt} a \SI{4.089}{\volt}, es decir una tasa de \SI{0.19}{\milli\volt\per\hour}.

La descarga de una batería LiPo no es lineal: cae con rapidez en la zona alta, presenta una meseta central prolongada y decae de nuevo al final. Por ello se estimó la autonomía de dos formas (Fig.~\ref{fig:autonomia-descarga}). Una extrapolación lineal desde la zona alta ofrece una cota inferior conservadora de \num{177} días hasta \SI{3.30}{\volt} (\num{242} hasta \SI{3.00}{\volt}). Modelando la forma real de la curva mediante una característica tensión--estado de carga típica de un LiPo, calibrada con los puntos medidos, la autonomía estimada asciende a \numrange{291}{307} días, del orden de \num{10} meses. En ambos casos la corriente promedio es del orden de \SIrange{0.13}{0.24}{\milli\ampere} y la autonomía supera ampliamente el criterio de \SI{8}{\hour}.

La Fig.~\ref{fig:autonomia-ciclo} muestra el modelo de consumo por ciclo: el nodo permanece en sueño profundo (\SI{\approx 15}{\micro\ampere}) durante el \SI{98.1}{\percent} del tiempo y presenta un pico activo de \SI{2.279}{\second} ---arranque, lectura y transmisión LoRa---. Este perfil pulsado, con un ciclo de trabajo de solo \SI{1.9}{\percent}, es coherente con la corriente promedio de la prueba de descarga. Con la batería de \SI{2000}{\milli\ampere\hour} del prototipo, la autonomía se duplicaría, del orden de un año.

\begin{figure}[!t]
  \centering
  
  \caption{Prueba de descarga de la batería de \SI{1000}{\milli\ampere\hour}: puntos medidos (13--18 de agosto de 2026), modelo no lineal de descarga LiPo (curva tensión--estado de carga calibrada) y extrapolación lineal como cota inferior. El modelo estima la autonomía en unos \num{10} meses.}
  \label{fig:autonomia-descarga}
\end{figure}

\begin{figure}[!t]
  \centering
  
  \caption{Modelo de consumo por ciclo: sueño profundo (\SI{\approx 15}{\micro\ampere}) durante la mayor parte del ciclo y un pico activo de \SI{2.279}{\second} para la lectura y transmisión. La corriente promedio resultante (\SI{\approx 0.24}{\milli\ampere}) coincide con la de la prueba de descarga.}
  \label{fig:autonomia-ciclo}
\end{figure}

\begin{table}[!t]
\caption{Resultados funcionales verificados}
\label{tab:resultados}
\centering
\footnotesize
\begin{tabularx}{\columnwidth}{@{}Xc@{}}
\toprule
\textbf{Función} & \textbf{Estado} \\
\midrule
Lectura de PT100 de tres hilos & Implementada \\
Detección de fallas del MAX31865 & Implementada \\
Identificación individual de nodos & Implementada \\
Temperatura y batería en la trama & Implementada \\
Sueño profundo y periodo configurable & Implementada \\
Almacenamiento microSD/LittleFS & Implementada \\
Histórico por sensor y fecha & Implementada \\
Gráfica diaria de 24 horas & Implementada \\
Mínimo, máximo y promedio & Implementada \\
Comparación de sensores & Implementada \\
Offset progresivo por nodo & Implementada \\
Umbrales y alarmas & Implementada \\
Exportación directa CSV & Por verificar \\
RSSI y SNR experimentales & No implementados \\
\bottomrule
\end{tabularx}
\end{table}

\subsection{Despliegue de 32 días y disponibilidad}

Se analizó un registro real de la planta con \num{51338} muestras provenientes de tres nodos, con un intervalo de muestreo mediano de \SI{121}{\second}. La Tabla~\ref{tab:estadisticas} resume la temperatura registrada por cada sensor durante el despliegue. La Fig.~\ref{fig:val-serie} presenta la serie completa de temperatura de uno de los nodos, en la que se aprecia el máximo de \SI{70.0}{\celsius} asociado al caso del succionador.

\begin{table}[!t]
\caption{Estadísticas de temperatura por sensor durante el despliegue}
\label{tab:estadisticas}
\centering
\footnotesize
\begin{tabularx}{\columnwidth}{@{}Xccccc@{}}
\toprule
\textbf{Nodo} & \textbf{Muestras} & \textbf{Mín.} & \textbf{Máx.} & \textbf{Prom.} & \textbf{Desv.} \\
 & & (\si{\celsius}) & (\si{\celsius}) & (\si{\celsius}) & (\si{\celsius}) \\
\midrule
Nodo A & \num{17537} & 17,1 & 70,0 & 45,4 & 20,1 \\
Nodo B & \num{16487} & 15,3 & 62,4 & 39,5 & 14,5 \\
Nodo C & \num{17314} & 16,4 & 65,0 & 44,7 & 16,7 \\
\bottomrule
\end{tabularx}
\vskip 0.15cm
{\footnotesize Nodos A y C: del 8 de mayo al 9 de junio de 2026 (32 días). Nodo B: del 10 de mayo al 20 de julio de 2026 (72 días). La desviación estándar alta refleja los ciclos de marcha y parada de las máquinas.}
\end{table}

La Fig.~\ref{fig:comparacion} compara las series de temperatura de los tres nodos en la ventana común, donde se aprecia que cada máquina presenta un comportamiento térmico distinto y que las interrupciones son simultáneas. La Fig.~\ref{fig:distribucion} resume la distribución de temperatura por nodo: el Nodo A (succionador) es el más caliente, con la mediana más alta y el mayor rango.

\begin{figure}[!t]
  \centering
  
  \caption{Series de temperatura de los tres nodos en la ventana común de medición. Cada nodo corresponde a una máquina distinta; las interrupciones simultáneas confirman que fueron periodos de gateway apagado.}
  \label{fig:comparacion}
\end{figure}

\begin{figure}[!t]
  \centering
  
  \caption{Distribución de temperatura por nodo (mediana, cuartiles y rango). El Nodo A, sobre el motor del succionador, presenta la mediana y el máximo más altos.}
  \label{fig:distribucion}
\end{figure}

La Fig.~\ref{fig:val-cobertura} muestra la cobertura de datos de los tres nodos. Las interrupciones no se distribuyen de forma independiente entre nodos, sino que ocurren de manera \emph{simultánea} en los tres, con el mismo instante de inicio. Este comportamiento indica que las interrupciones no correspondieron a fallas del enlace LoRa —que afectarían a un nodo a la vez— sino a periodos en los que el gateway permaneció apagado durante paradas de planta y de energía.

En consecuencia, la Tabla~\ref{tab:disponibilidad} reporta dos indicadores. La disponibilidad cruda considera todo el intervalo de despliegue, incluidos los periodos de gateway apagado. La disponibilidad del enlace excluye dichos periodos, identificados por su simultaneidad, y estima la fracción de tramas efectivamente recibidas mientras el sistema estuvo activo. La disponibilidad del enlace se mantuvo por encima del \SI{97}{\percent} en los tres nodos. La Fig.~\ref{fig:val-intervalos} confirma la regularidad de la recepción durante los tramos activos: la mayoría de los intervalos entre llegadas se concentraron alrededor de la mediana de \SI{121}{\second}.

\begin{figure}[!t]
  \centering
  
  \caption{Serie de temperatura superficial de un nodo durante el despliegue de 32 días, con el máximo asociado al caso del succionador.}
  \label{fig:val-serie}
\end{figure}

\begin{figure}[!t]
  \centering
  
  \caption{Cobertura de datos de los tres nodos. Las interrupciones son simultáneas en todos los nodos, lo que corresponde a periodos de gateway apagado (paradas de planta) y no a fallas del enlace LoRa.}
  \label{fig:val-cobertura}
\end{figure}

\begin{table}[!t]
\caption{Disponibilidad por nodo durante el despliegue}
\label{tab:disponibilidad}
\centering
\footnotesize
\begin{tabularx}{\columnwidth}{@{}Xccccc@{}}
\toprule
\textbf{Nodo} & \textbf{Muestras} & \textbf{Cruda} & \textbf{Enlace} & \textbf{Paradas} & \textbf{h fuera} \\
\midrule
Nodo A & \num{17537} & \SI{76.0}{\percent} & \SI{98.4}{\percent} & 66 & 176 \\
Nodo B & \num{16487} & \SI{32.3}{\percent} & \SI{98.3}{\percent} & 73 & 1154 \\
Nodo C & \num{17314} & \SI{75.1}{\percent} & \SI{97.8}{\percent} & 81 & 180 \\
\bottomrule
\end{tabularx}
\vskip 0.2cm
{\footnotesize La disponibilidad del enlace excluye los periodos de gateway apagado, identificados por ser simultáneos en los tres nodos. El Nodo B incluye una parada prolongada de aproximadamente 33 días.}
\end{table}

\begin{figure}[!t]
  \centering
  
  \caption{Distribución de los intervalos entre llegadas durante los tramos activos. La escala vertical es logarítmica; la mayoría de las tramas se recibieron con una cadencia cercana a la mediana de \SI{121}{\second}.}
  \label{fig:val-intervalos}
\end{figure}

\subsection{Caso del motor del succionador}

La Fig.~\ref{fig:historico-succionador} corresponde al succionador de la máquina Twin y presenta una jornada completa, desde aproximadamente las 00:01 hasta las 23:59. Al inicio se observó una condición relativamente estable cercana a \SIrange{48}{49}{\celsius}. Alrededor de la 01:30 ocurrió un incremento rápido hasta una zona superior a \SI{63}{\celsius}. Después del transitorio, la mayor parte de la curva permaneció aproximadamente entre \SIrange{57}{61}{\celsius}, con ciclos repetidos de calentamiento y enfriamiento.

Se identificaron varios picos breves por encima de \SI{63}{\celsius}. El mayor ocurrió cerca del mediodía y el dashboard mostró una máxima de \SI{67.0}{\celsius}. También se observaron descensos hasta la zona de \SIrange{52}{55}{\celsius} durante la tarde, seguidos por recuperaciones progresivas. A partir de aproximadamente las 21:00, la temperatura aumentó de forma gradual y se estabilizó alrededor de \SIrange{60}{61}{\celsius} hasta finalizar el día. El cambio de color de la curva representa los umbrales configurados: verde para la zona inferior, naranja para advertencia y rojo para condición térmica alta.

Este patrón muestra que el calentamiento no correspondió a un único evento aislado. La serie histórica permitió observar transitorios y repeticiones que no podrían reconstruirse con una medición manual ocasional. De acuerdo con la operación observada en planta, los tramos ascendentes corresponden a periodos en los que la Twin se detuvo y el motor del succionador permaneció girando en vacío. Los descensos se presentaron cuando la máquina volvió a operar. Esta relación aporta contexto al comportamiento térmico, aunque las horas exactas deberán confirmarse con un registro de marcha y parada.

La revisión posterior relacionó el patrón con una condición anómala en los rodamientos. Se presenta como \emph{observación de campo} y no como una detección predictiva validada: se describe lo que se observó (el incremento térmico) y lo que se confirmó después (la inspección). Una imagen térmica tomada con una cámara FLIR C8 confirmó el punto caliente sobre la carcasa del motor en torno a \SIrange{70}{71}{\celsius} (Fig.~\ref{fig:termica}), de forma coherente con la lectura de la PT100 y del termómetro infrarrojo.
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

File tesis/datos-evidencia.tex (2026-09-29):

% Central evidence ledger. Do not redefine these values in thesis chapters.
\newcommand{\NumeroNodos}{3}
\newcommand{\TotalMuestras}{51\,338}
% Historical macro name: 32 days describe A/C, not complete three-node overlap.
\newcommand{\DuracionComunDias}{32}
\newcommand{\PeriodoNominal}{120~s}
\newcommand{\PeriodoMediano}{121~s}
\newcommand{\DisponibilidadEnlace}{97.8--98.4\,\%}
\newcommand{\PDREstimado}{95.3--96.6\,\%}
\newcommand{\PerdidaEstimada}{3.5--4.7\,\%}
\newcommand{\DiferenciaTermicaMaxima}{0.23~\textdegree C}
% Seis parejas Fluke-SmartSense en regimen estable con foto y hora verificables (analisis/parejas_fluke.py).
\newcommand{\DiferenciaTermicaMedia}{0.15~\textdegree C}
\newcommand{\RMSETermico}{0.16~\textdegree C}
\newcommand{\NumeroParejas}{seis}
\newcommand{\DuracionDescarga}{5~días}
\newcommand{\AutonomiaLinealEstimada}{177~días}
% Source of truth: analisis/autonomia_bateria.py, LiPo OCV--SoC interpolation
% calibrated to V0=4.112 V and V5=4.089 V over H=120 h. Its output is
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

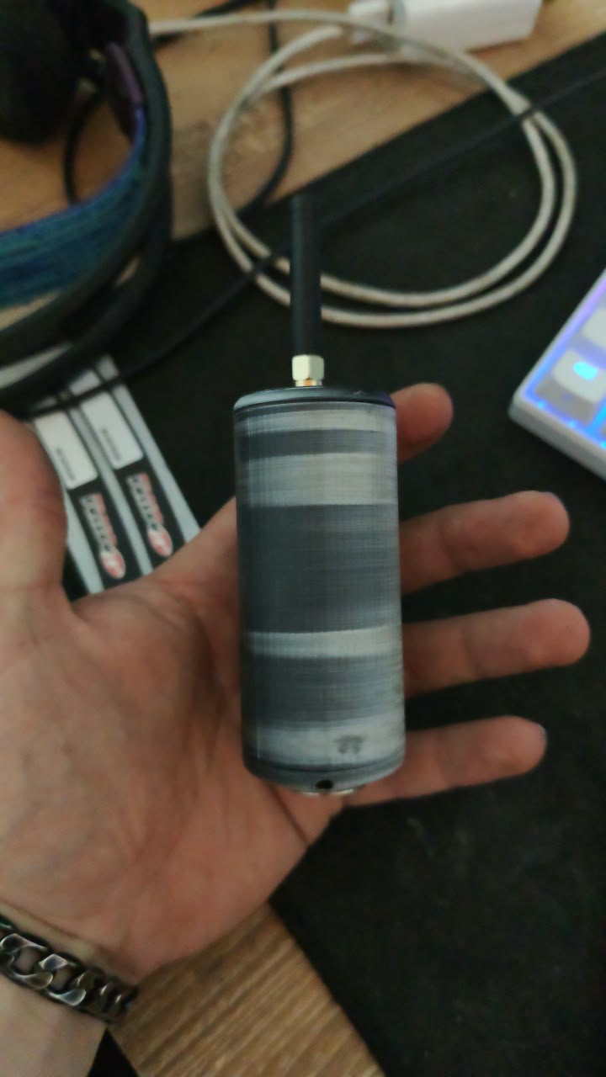
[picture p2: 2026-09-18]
figuras/Fotos diseño final/WhatsApp Image 2026-09-18 at 8.51.23 AM.jpeg

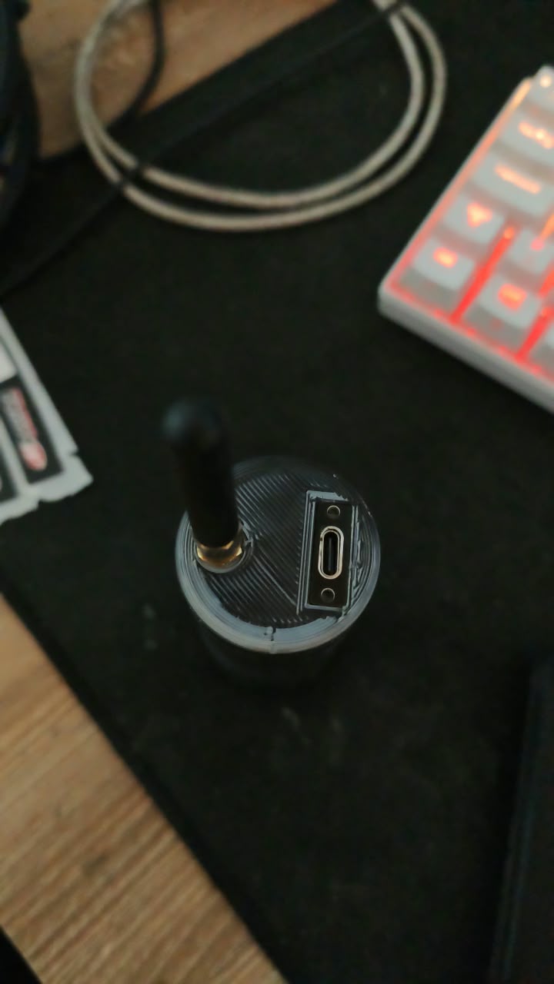
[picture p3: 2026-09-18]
figuras/Fotos diseño final/WhatsApp Image 2026-09-18 at 8.51.27 AM.jpeg

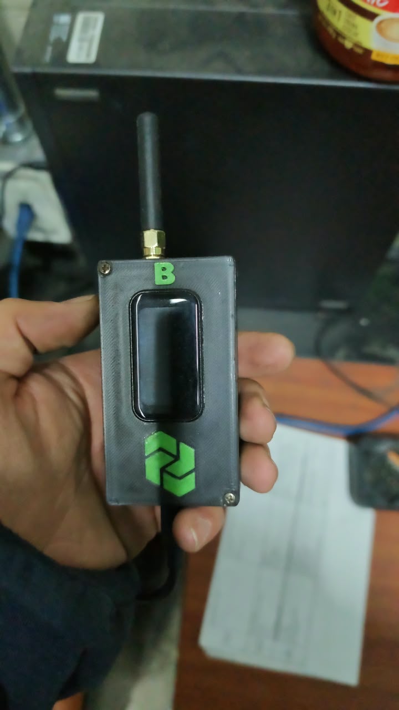
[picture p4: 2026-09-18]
figuras/Fotos diseño final/WhatsApp Image 2026-09-18 at 5.23.30 AM.jpeg

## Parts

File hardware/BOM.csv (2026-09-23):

Designator | Component | Number | Cost per unit - COP | Total cost - COP | Source of materials | Material type
U1 | Seeed Studio XIAO ESP32-C6 (nodo sensor) | 3 | 30000 | 90000 | https://www.seeedstudio.com/ | Semi-conductor
U2 | Placa ESP32-C6 Touch LCD 1.47 (gateway/visualizador) | 1 | 90000 | 90000 | Distribuidor local | Semi-conductor
U3 | Modulo LoRa Ebyte E220-400T22D (LLCC68; 410.125-493.125 MHz; 22 dBm; antena SMA) | 4 | 30000 | 120000 | https://www.cdebyte.com/products/E220-400T22D | Semi-conductor
RT1 | Sonda PT100 magnetica de 3 hilos ZUIDID (elemento de pelicula delgada; sonda 19x9.5 mm; cable -60 a +200 C; terminal en U; clase de tolerancia no indicada) | 3 | 30000 | 90000 | https://www.aliexpress.com/item/1005008619909588.html | Metal
U4 | Modulo acondicionador MAX31865 | 3 | 14000 | 42000 | https://www.sigmaelectronica.net/ | Semi-conductor
BT1 | Bateria LiPo 3.7 V 1000 mAh | 3 | 30000 | 90000 | https://www.didacticaselectronicas.com/ | Other
U5 | Modulo de carga/proteccion LiPo (TP4056 o equivalente) | 3 | 5000 | 15000 | Distribuidor local | Semi-conductor
R1 | Resistencia 344.8 kOhm (divisor bateria) | 3 | incluido en cableado | 0 | Distribuidor local | Other
R2 | Resistencia 994.3 kOhm (divisor bateria) | 3 | incluido en cableado | 0 | Distribuidor local | Other
MEC1 | Carcasa impresa en PLA | 4 | 10000 | 40000 | Impresion propia | Polymer
W1 | Cables, conectores, pines, tornilleria y adhesivos | 1 | 50000 | 50000 | Distribuidor local | Other

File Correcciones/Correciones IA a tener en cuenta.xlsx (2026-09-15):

Sección del artículo | Aspecto a fortalecer | ¿Qué problema tiene actualmente? | ¿Qué debes hacer? | Evidencia/producto que debes generar | Criterio para darlo por cerrado
Validation / Results | Validación de temperatura | El ±0,4 °C se obtiene frente al Fluke utilizado durante el ajuste; por tanto, no es una validación independiente. | Realizar una prueba con una referencia independiente y calibrada. Medir varios puntos de temperatura y repetir las mediciones. | Tabla de referencia vs. SmartSense + error, MAE, RMSE y desviación. | Puedes afirmar cuantitativamente el desempeño térmico del sistema con una referencia independiente.
Validation / Battery | Autonomía | La autonomía está estimada teóricamente entre 4,8 y 147 días y el propio artículo reconoce que falta verificar el consumo real. | Medir experimentalmente corriente en sleep, adquisición, procesamiento y transmisión. | Corriente por estado + consumo promedio + estimación/medición de autonomía. | Existe un valor experimental defendible de autonomía, no solo un rango teórico.
Reproducibility / Data availability | Repositorio abierto | El artículo afirma que los archivos estarán disponibles, pero algunos todavía están pendientes de publicación. | Completar y publicar hardware, firmware, software, CAD/STL, BOM, configuración y documentación. | Repositorio público + DOI + versión identificada. | Un tercero puede reconstruir el sistema siguiendo el artículo y descargando los archivos.
Abstract / Introduction / Conclusion | Predictive maintenance | El sistema no implementa ni valida un algoritmo de mantenimiento predictivo. | Cambiar el claim hacia condition monitoring / condition-based maintenance support. | Matriz Claim → Evidence y nueva formulación conceptual. | Ninguna afirmación dice que SmartSense "demuestra predictive maintenance".
Title / Abstract | "Long-term" | El piloto dura 32 días, por lo que "long-term" puede ser una afirmación demasiado amplia. | Justificar el término o utilizar "long-duration field deployment/pilot deployment". | Título y abstract ajustados. | El título refleja exactamente lo demostrado experimentalmente.
Results | Disponibilidad >97 % | El >97 % corresponde a periodos en los que el gateway estaba activo, no necesariamente a disponibilidad total del sistema. | Separar "system availability" de "link availability during active gateway periods". | Tabla con ambas métricas, si los datos lo permiten. | El lector puede entender exactamente qué representa el 97 %.
Results / Case study | Anomalía del rodamiento | Se observa un incremento térmico asociado posteriormente a una anomalía, pero no se demuestra detección predictiva. | Presentarlo como field observation/case study, indicando qué se observó y qué se confirmó posteriormente. | Gráfica temporal: temperatura → evento → inspección/mantenimiento. | Se afirma únicamente lo que los datos permiten demostrar.
Hardware Description | PT100 | "Industrial-grade PT100" es demasiado genérico. | Identificar fabricante, referencia, clase/tolerancia, rango y características relevantes. | Ficha técnica + especificación completa en tabla. | El sensor queda completamente identificado y reproducible.
Wireless communication | Caracterización LoRa | Hay disponibilidad y pérdida de paquetes, pero falta caracterización más completa del enlace. | Incorporar, si están disponibles, RSSI, SNR, distancia, condiciones de instalación y configuración de transmisión. | Tabla de parámetros de comunicación + métricas. | El lector puede evaluar bajo qué condiciones funcionó el enlace.
Validation | Repetibilidad | No queda suficientemente demostrada la consistencia entre los tres nodos. | Comparar nodos bajo condiciones equivalentes. | Gráfica/tablas de Node A, B y C + estadísticos. | Se demuestra que el comportamiento no depende de un único nodo.
Hardware Description / Data | Almacenamiento | Se menciona capacidad de 30 días, mientras el experimento dura 32 días. | Explicar exactamente dónde se almacenaron los datos, cómo se gestionan y qué ocurre al superar la capacidad. | Diagrama del flujo de almacenamiento + explicación. | No existe ambigüedad sobre la gestión de datos durante el piloto.
Hardware in Context | Comparación con soluciones comerciales | Se afirma ventaja económica frente a soluciones comerciales, pero las funcionalidades no están normalizadas. | Hacer comparación técnica justa: costo, sensores, comunicación, almacenamiento, batería, IP, software, apertura, etc. | Tabla SmartSense vs. alternativas. | Las conclusiones competitivas se basan en características comparables.
Introduction / Hardware in Context | Estado del arte | Las referencias actuales son pocas para justificar completamente la novedad y comparación. | Incorporar trabajos recientes y específicos de monitorización térmica, LoRa industrial, open hardware y condition monitoring. | Tabla comparativa del estado del arte. | Queda claramente identificado qué hacen otros sistemas y qué aporta SmartSense.
Cost | Costo del sistema | Hay valores en COP/USD que necesitan mayor claridad. | Indicar fecha/tasa de cambio y separar costo de nodo, gateway, batería, enclosure, etc. | Tabla de costos reproducible. | Otro investigador puede estimar el costo del sistema.
Figures | Presentación gráfica | Algunas figuras pueden fortalecerse para facilitar la lectura técnica. | Mejorar resolución, tamaños de letra, unidades, leyendas y pies de figura. | Figuras finales de publicación. | Todas las figuras se entienden sin depender excesivamente del texto.
References | Bibliografía | Hay referencias fundamentales, pero puede fortalecerse la literatura reciente y específica. | Actualizar referencias y verificar que cada claim importante tenga respaldo. | Bibliografía revisada + matriz claim/referencia. | No quedan afirmaciones importantes sin respaldo bibliográfico.
Manuscript overall | Coherencia narrativa | Conviven tres ideas: open hardware, monitoreo industrial y predictive maintenance. | Hacer que open-source industrial temperature monitoring sea la narrativa principal y las otras sean contexto/aplicación. | Esquema narrativo definitivo. | Todas las secciones conducen a la misma contribución.

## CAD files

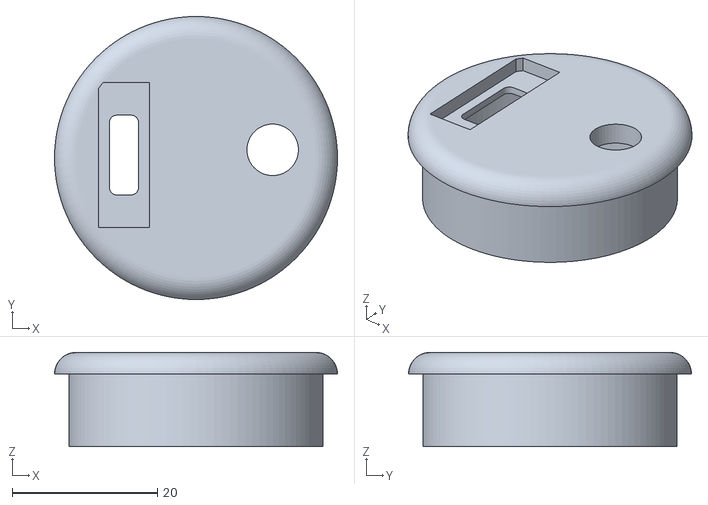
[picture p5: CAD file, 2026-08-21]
hardware/carcasa/tapa-sensor.stl
39.0 x 39.0 x 13.0

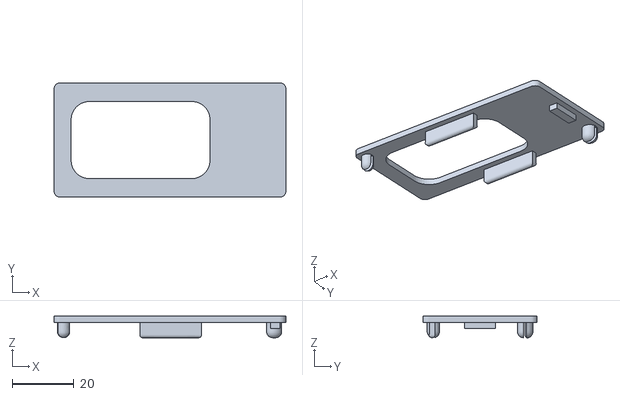
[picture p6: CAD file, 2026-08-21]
hardware/carcasa/tapa-gateway.stl
75.0 x 37.0 x 7.00

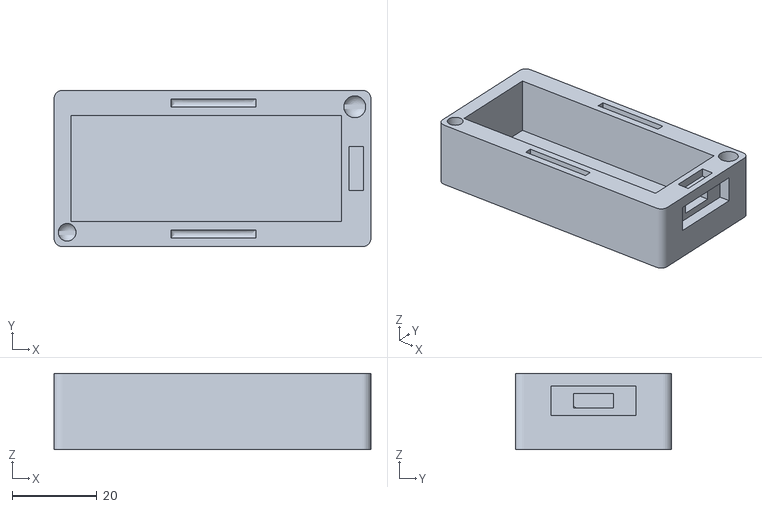
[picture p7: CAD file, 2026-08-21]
hardware/carcasa/carcasa-gateway.stl
75.0 x 37.0 x 18.0

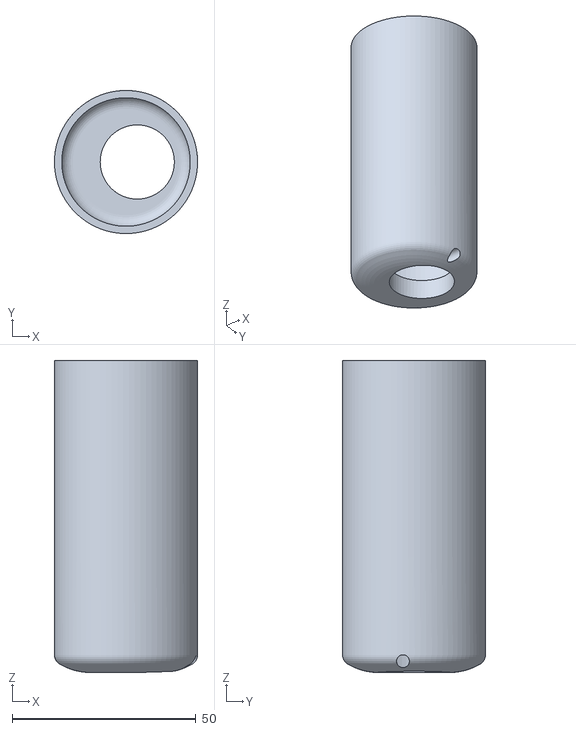
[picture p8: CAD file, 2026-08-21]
hardware/carcasa/carcasa-sensor.stl
39.0 x 39.0 x 85.0

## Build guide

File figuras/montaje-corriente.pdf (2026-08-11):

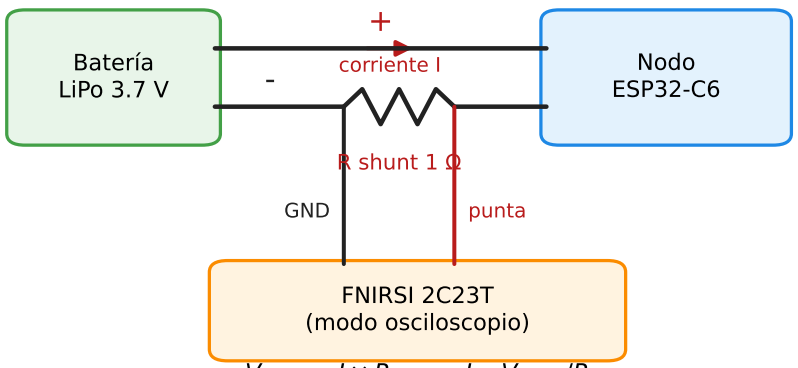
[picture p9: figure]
Batería LiPo 3.7 V; Nodo ESP32-C6; FNIRSI 2C23T (modo osciloscopio); corriente I; R shunt 1 Ω; GND; punta

Vshunt = I × R ⇒ I = Vshunt/R

### Medición de corriente con shunt de lado bajo

El osciloscopio lee la caída en el shunt; el promedio del pulso da la corriente activa

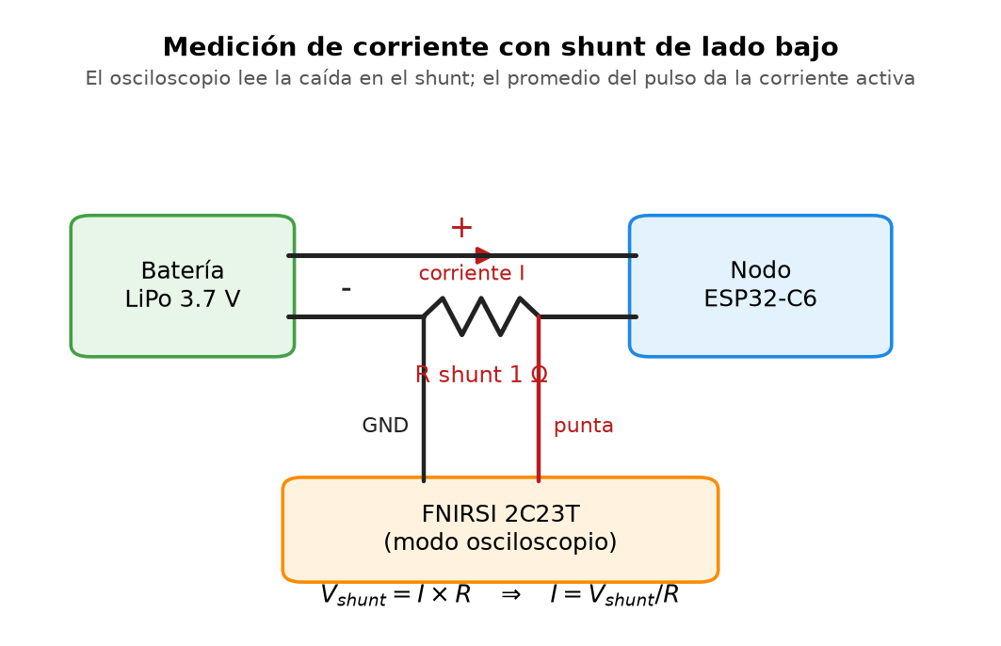
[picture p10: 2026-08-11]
figuras/montaje-corriente.png

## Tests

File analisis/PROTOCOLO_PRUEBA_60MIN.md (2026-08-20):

# Protocolo de prueba instrumentada (60 min)

Firmware actualizado para capturar, por paquete: **PDR (contador SEQ), temperatura,
batería (voltaje real), RSSI y tiempo encendido**. El gateway imprime una línea
`CSV,...` por paquete en el monitor serie.

## ANTES de la prueba (hoy) — verificación obligatoria

Los cambios de firmware NO se pudieron compilar/probar aquí. Tras flashear:

1. Reflashear los **3 nodos** (`Nodo_Lora.ino`) y el **gateway** (`maestro_Lora_pantalla.ino`).
2. Abrir el Monitor Serie del gateway (115200) y confirmar:
   - Aparece `[E220][RSSI] Habilitando byte de RSSI...` y una respuesta del módulo.
   - **Sigue llegando la recepción normal** (líneas `[PDR]` y `CSV,` cuando un nodo transmite).
   - En las líneas `CSV,` el penúltimo campo (`rssi_raw`) es **distinto de -1** (llegó RSSI).
3. Si la recepción se rompió o `rssi_raw` siempre es -1:
   - Poner `#define TRY_RSSI 0` en el gateway y reflashear (se pierde RSSI pero todo lo demás funciona).
   - El comando `AT+RSSI=1` puede variar según la variante del módulo; ese es el punto a revisar.

## Durante la prueba

1. Cargar los 3 nodos al 100 % y anotar el voltaje inicial de cada uno.
2. Encender el gateway con el **Monitor Serie grabando a un archivo** (Arduino IDE: no graba;
   usar PuTTY/`pio device monitor -f log`/CoolTerm para guardar a `.txt`).
3. Encender los 3 nodos a la vez. Anotar **hora de inicio** y la **distancia** nodo–gateway.
4. Dejar correr **60 min** (o bajar el intervalo a 30 s desde el dashboard para más paquetes).
5. Al terminar, guardar el `.txt` del monitor serie.

## Después

```
python analisis/analizar_prueba.py  <log_del_monitor_serie.txt>
```
Saca por nodo: PDR/pérdida, temperatura (min/máx/prom), batería (inicio/fin) y RSSI (min/máx/prom).

## Qué queda fuera (limitaciones honestas)

- **SNR**: el E220 no lo expone (necesitaría un SX1262 pelado).
- **Latencia extremo a extremo**: requiere sincronizar el reloj nodo↔gateway.
- **MAE ≤1 °C**: requiere una termocupla/RTD calibrada (el Fluke y la FLIR son IR).

## Formato de la línea CSV (para futuras pruebas)

```
CSV,epoch,mac,id,seq,temp_c,vbat,bat_pct,rssi_dbm,rssi_raw,up_ms
```

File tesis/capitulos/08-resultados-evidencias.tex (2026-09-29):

\chapter{Resultados y evidencias}
\label{cap:resultados}

\section{Resultados y nivel de evidencia}
SmartSense produjo registros identificados de \NumeroNodos{} nodos, conservó series de temperatura superficial y permitió su consulta local. La evaluación combina el histórico de planta, comparaciones térmicas y ensayos complementarios de agosto de 2026. No todos esos resultados corresponden a la misma ventana temporal ni tienen el mismo alcance: un registro recibido es una observación; atribuir un hueco a un apagado es una inferencia; extrapolar la descarga es una estimación.

La tabla~\ref{tab:resultados-evidencia} relaciona cada resultado con su método y su limitación; las cifras se desarrollan en las secciones siguientes. Las estadísticas del histórico provienen de los scripts del proyecto ejecutados sobre el CSV exportado del gateway, que no está en el repositorio (sección~\ref{sec:anexos-reproducibilidad}).

\begingroup
\footnotesize\singlespacing
\setlength{\tabcolsep}{3pt}
\begin{longtable}{@{}>{\raggedright\arraybackslash}p{2.1cm}>{\raggedright\arraybackslash}p{2.25cm}>{\raggedright\arraybackslash}p{2.15cm}>{\raggedright\arraybackslash}p{1.95cm}>{\raggedright\arraybackslash}p{2.35cm}>{\raggedright\arraybackslash}p{3.1cm}@{}}
\caption{Resultados, métodos y alcance de la evidencia disponible.}\label{tab:resultados-evidencia}\\
\toprule
\textbf{Resultado} & \textbf{Método} & \textbf{Valor} & \textbf{Tipo de evidencia} & \textbf{Interpretación} & \textbf{Limitación} \\
\midrule\endfirsthead
\multicolumn{6}{l}{Tabla~\thetable{} (continuación)}\\
\toprule
\textbf{Resultado} & \textbf{Método} & \textbf{Valor} & \textbf{Tipo de evidencia} & \textbf{Interpretación} & \textbf{Limitación} \\
\midrule\endhead
\bottomrule\endfoot
Nodos & Identificación por MAC y registros separados. & \NumeroNodos{} nodos. & Funcional y documental. & Adquisición distribuida en el piloto. & No es una prueba de capacidad máxima de red. \\
Muestras & Conteo documentado por sensor. & \TotalMuestras{}. & Histórico observado. & Volumen total del archivo analizado. & A y C abarcan \DuracionComunDias{} días; B incluye una extensión. No son todas de una ventana común idéntica. \\
Temperatura & Mínimos y máximos por nodo. & 15.3--70.0~\textdegree C. & Histórico observado. & Intervalo registrado en el conjunto. & No es el rango calibrado de la sonda; las parejas de campo son otro registro. \\
Concordancia & Parejas Fluke--SmartSense con foto y hora, emparejadas con el CSV. & \NumeroParejas{} parejas estables: media absoluta \DiferenciaTermicaMedia{}, máximo \DiferenciaTermicaMaxima{}. & Comparación de campo verificable. & Concordancia con la referencia tras ajustar offset. & Referencia infrarroja sin certificado, usada también en el ajuste; una pareja en arranque difiere 3.6~\textdegree C. \\
Disponibilidad cruda & Recibidos frente a esperados en la ventana individual, con 121~s. & A: 76.0\,\%; B: 32.3\,\%; C: 75.1\,\%. & Cálculo sobre registros. & Cobertura que recibió el usuario, incluidos huecos. & Las ventanas tienen distinta duración. \\
Disponibilidad de enlace & Se excluyen intervalos mayores de 363~s. & \DisponibilidadEnlace{}. & Cálculo condicionado a actividad inferida. & Cobertura en los tramos clasificados como activos. & La exclusión no prueba alimentación del gateway ni causa de cada hueco. \\
PDR histórico & Estimado por intervalos, 120~s; exclusión sobre 1800~s. & \PDREstimado{}. & Inferencia temporal. & Entrega estimada durante periodos activos. & Sin contador de envíos; población distinta de disponibilidad. \\
Ventana de 60 min & Recibidos frente a esperados en una hora seleccionada. & A: 29/30; B: 30/30; C: 30/30. & Conteo histórico con denominador nominal. & Cobertura de una hora con los tres nodos. & Seleccionada por cobertura; no es PDR directo ni ensayo independiente. \\
Arranque y recuperación & Intervalo instrumentado en diez arranques. & \TiempoActivo{} en ocho registros. & Temporización de firmware documentada. & Actividad observada dentro del tramo instrumentado. & No garantiza tiempo físico total desde energización ni recuperación del enlace. \\
Alcance y RSSI & Recorrido urbano móvil, NLOS. & Al menos \DistanciaDemostrada{}; cerca de \RSSILejano{}. & Ensayo de campo documentado. & Enlace operativo en el punto más lejano visitado. & Cota inferior; geometría variable. \\
Autonomía & Descarga parcial de \DuracionDescarga{} y dos modelos. & Lineal: \AutonomiaLinealEstimada{}; LiPo: \AutonomiaModeloEstimada{}. & Autonomía estimada. & Proyección bajo los supuestos del ensayo. & Sin descarga hasta corte ni corriente integral medida por estado. \\
\end{longtable}
\endgroup

\section{Despliegue de 32 días y cobertura real}
\label{sec:resultados-despliegue}
\subsection{Población y estadísticas por nodo}
El piloto de \DuracionComunDias{} días es el tramo del 8 de mayo al 9 de junio de 2026 que cubren los nodos A y C; el nodo B empieza el 10 de mayo y su archivo llega hasta el 20 de julio, unos 72 días. Las comparaciones gráficas se recortan al tramo común y la tabla~\ref{tab:resultados-estadisticas} conserva la ventana de cada sensor.

\begin{table}[htbp]
\centering\small
\caption[Estadísticas documentadas por nodo y ventana individual.]{Estadísticas documentadas por nodo, calculadas sobre su archivo individual. Las fechas corresponden a 2026.}
\label{tab:resultados-estadisticas}
\begin{tabularx}{\textwidth}{@{}lXrrrrr@{}}
\toprule
\textbf{Nodo} & \textbf{Fechas} & \textbf{Muestras} & \textbf{Mín.} & \textbf{Máx.} & \textbf{Media} & \textbf{Desv.} \\
 & & & \multicolumn{4}{c}{Temperatura (\textdegree C)} \\
\midrule
A & 8 mayo--9 junio & 17\,537 & 17.1 & 70.0 & 45.4 & 20.1 \\
B & 10 mayo--20 julio & 16\,487 & 15.3 & 62.4 & 39.5 & 14.5 \\
C & 8 mayo--9 junio & 17\,314 & 16.4 & 65.0 & 44.7 & 16.7 \\
\bottomrule
\end{tabularx}
\end{table}

En total son \TotalMuestras{} registros con una cadencia mediana de \PeriodoMediano{}. El rango de 15.3 a \SI{70.0}{\celsius} es el de las temperaturas registradas; la media y el máximo más altos son del nodo A, el del succionador. Las desviaciones estándar reflejan los calentamientos y enfriamientos de la operación, no la repetibilidad del instrumento.

La figura~\ref{fig:resultados-comparacion} contrasta las trayectorias en el tramo común y la figura~\ref{fig:resultados-serie} amplía la serie del nodo A con su máximo de \SI{70.0}{\celsius}. Las líneas que unen los puntos no son mediciones dentro de los huecos; la cobertura real está en la figura~\ref{fig:resultados-cobertura}.

\begin{figure}[htbp]
\centering

\caption[Series de los tres nodos en el solapamiento temporal.]{Series de los tres nodos recortadas a su solapamiento temporal. La gráfica permite comparar tendencias; las líneas entre registros no sustituyen las muestras ausentes. Fuente: figura existente generada por \texttt{analisis/graficas\_extra.py}.}
\label{fig:resultados-comparacion}
\end{figure}

\begin{figure}[htbp]
\centering

\caption[Temperatura superficial del Nodo A durante 32 días.]{Temperatura superficial del Nodo A durante el tramo de 32 días, con máximo histórico de 70.0~\textdegree C. La anotación localiza un máximo de la serie, sin identificar una causa mecánica. Fuente: figura existente de \texttt{analisis/figuras\_validacion.py}.}
\label{fig:resultados-serie}
\end{figure}

\subsection{Qué ocurrió durante el piloto}
\label{sec:resultados-cronologia}
La tabla~\ref{tab:resultados-cronologia} y la figura~\ref{fig:resultados-cronologia} reconstruyen el piloto a partir del propio CSV (\texttt{analisis/cronologia.py}). Los días en que el succionador estuvo detenido se reconocen porque la media diaria del nodo A cae por debajo de 30~\textdegree C, con la sonda cerca de la temperatura ambiente; los periodos en que el gateway no registró se reconocen porque el hueco aparece a la misma hora en los tres nodos.

\begin{table}[htbp]
\centering\small
\caption[Cronología del piloto y de los ensayos posteriores.]{Cronología del piloto reconstruida del CSV y ensayos posteriores. Todas las fechas son de 2026.}
\label{tab:resultados-cronologia}
\begin{tabularx}{\textwidth}{@{}>{\raggedright\arraybackslash}p{3.4cm}X@{}}
\toprule
\textbf{Fecha} & \textbf{Evento} \\
\midrule
8 y 9 de mayo & Instalación de los nodos A y C (primer registro a las 14:07) y operación del succionador con máximos diarios de 64.6 y 65.0~\textdegree C. \\
10 de mayo & Parada de un día del succionador (media 24.6~\textdegree C); inicio del registro del nodo B. \\
11 y 12 de mayo & Operación, máximos diarios de 67.2 y 66.5~\textdegree C. \\
13 al 19 de mayo & Gateway sin registrar en cuatro intervalos simultáneos en los tres nodos, de 13, 25, 17 y 88~h, atribuidos a paradas de planta. \\
14 al 21 de mayo & Succionador detenido en los días con registro; la sonda marca entre 19 y 27~\textdegree C. \\
22 de mayo & Reinicio de la operación; máximo diario 69.8~\textdegree C. \\
23 de mayo & Máximo histórico del succionador: 70.0~\textdegree C a las 15:26. \\
24 de mayo & Parada de un día (media 24.8~\textdegree C). \\
25 al 29 de mayo & Operación, máximos diarios de 65 a 69~\textdegree C. \\
30 y 31 de mayo & Parada desde la mañana del 30; el 31 la sonda marca entre 18 y 22~\textdegree C. Primera intervención del rodamiento según el equipo de planta. \\
1 al 5 de junio & Operación, máximos diarios de 65 a 68~\textdegree C. \\
6 al 8 de junio & Parada desde la tarde del 6; el 7 y el 8 la sonda marca entre 17 y 26~\textdegree C. Segunda intervención del rodamiento según el equipo de planta. \\
9 de junio & Último registro de los nodos A y C a las 21:12. \\
17 de junio al 20 de julio & Nodo B con registro esporádico, con huecos de 185 y 792~h. \\
13 al 18 de agosto & Descarga parcial de la celda de 1000~mAh: de 4.112 a 4.089~V en 120~h. \\
20 de agosto & Prueba de alcance urbana: 688~m con RSSI de $-98$~dBm. \\
\bottomrule
\end{tabularx}
\end{table}

\begin{figure}[htbp]
\centering

\caption[Cronología del nodo A e hitos del proyecto.]{Arriba: media y máximo diarios del nodo A, con los días de máquina detenida sombreados y los periodos sin registro del gateway rayados. Abajo: hitos del proyecto de mayo a agosto. Fuente: \texttt{analisis/cronologia.py} sobre el CSV exportado del gateway.}
\label{fig:resultados-cronologia}
\end{figure}

La secuencia que importa para el caso del succionador es: operación con máximos crecientes, máximo histórico de 70.0~\textdegree C el 23 de mayo y paradas posteriores el 24, el 30 y 31 de mayo y del 6 al 8 de junio, en las que la sonda vuelve a la temperatura ambiente. Según el equipo de planta, el rodamiento del motor se intervino en las paradas del 30 y 31 de mayo y del 7 y 8 de junio, es decir, después del máximo del 23 de mayo: la serie mostró primero el calentamiento y la intervención vino en las dos paradas siguientes. Las paradas de planta con el gateway apagado explican la disponibilidad cruda de la sección siguiente.

\subsection{Disponibilidad cruda y disponibilidad durante actividad inferida}
\label{sec:resultados-disponibilidad}
La tabla~\ref{tab:resultados-disponibilidad} presenta las dos métricas juntas para que la exclusión de interrupciones no oculte la cobertura que tuvo el usuario. El cálculo, de \texttt{analisis/figuras\_validacion.py}, usa $T=121$~s, marca como hueco todo intervalo mayor de $3T=363$~s y resta la duración de esos huecos al tiempo entre la primera y la última muestra para el denominador del enlace; es una exclusión distinta de la de 30 minutos que usa el PDR.

\begin{table}[htbp]
\centering\small
\caption[Disponibilidad cruda y condicionada en las ventanas individuales.]{Disponibilidad documentada en las ventanas individuales de la tabla~\ref{tab:resultados-estadisticas}. Los huecos y horas son clasificaciones temporales, no un registro directo de apagados.}
\label{tab:resultados-disponibilidad}
\begin{tabularx}{\textwidth}{@{}lXXrr@{}}
\toprule
\textbf{Nodo} & \textbf{Cruda (\%)} & \textbf{Enlace condicionado (\%)} & \textbf{Huecos} & \textbf{Horas excluidas} \\
\midrule
A & 76.0 & 98.4 & 66 & 176 \\
B & 32.3 & 98.3 & 73 & 1154 \\
C & 75.1 & 97.8 & 81 & 180 \\
\bottomrule
\end{tabularx}
\end{table}

El nodo B tiene una ventana mayor y un hueco de unos 33 días, así que su 32.3\,\% no es comparable con el 76.0\,\% de A sobre el mismo calendario. La disponibilidad condicionada de \DisponibilidadEnlace{} describe los tramos en que el gateway registraba; cuando no registra, el usuario se queda sin serie aunque los nodos sigan transmitiendo.

Que varias interrupciones coincidan en los tres nodos, como se ve en la figura~\ref{fig:resultados-cobertura} y en la cronología, respalda la lectura de gateway apagado durante las paradas de planta; sin bitácora de alimentación no se descarta una falla común de recepción, reloj o almacenamiento, ni un hueco aislado prueba una falla de radio. Por eso se conservan las dos métricas y el criterio de exclusión.

\begin{figure}[htbp]
\centering

\caption[Cobertura y huecos del registro de los tres nodos.]{Cobertura en el solapamiento de los tres nodos; los espacios blancos conservan los huecos del registro. El rótulo histórico \textit{gateway down} expresa una interpretación compatible con la simultaneidad, no una comprobación independiente de alimentación. Fuente: generador de figuras de validación del proyecto.}
\label{fig:resultados-cobertura}
\end{figure}

\section{Entrega estimada de paquetes y ventana de 60 minutos}
\label{sec:resultados-pdr}
El PDR del despliegue es estimado por intervalos con la ecuación~\ref{eq:metodo-perdida-inferida}, periodo nominal de \PeriodoNominal{} y exclusión de intervalos mayores de 1800~s (tabla~\ref{tab:resultados-pdr}). Cada valor corresponde al archivo de su nodo, y la estimación supone que el nodo mantuvo la cadencia; el número real de envíos no se conoce.

\begin{table}[htbp]
\centering
\caption{Pérdida y PDR estimados por intervalos en periodos clasificados como activos.}
\label{tab:resultados-pdr}
\begin{tabular}{lrr}
\toprule
\textbf{Nodo} & \textbf{Pérdida estimada (\%)} & \textbf{PDR estimado (\%)} \\
\midrule
A & 3.45 & 96.55 \\
B & 3.93 & 96.07 \\
C & 4.68 & 95.32 \\
\bottomrule
\end{tabular}
\end{table}

En resumen, \PDREstimado{} de PDR y \PerdidaEstimada{} de pérdida, que cumplen los criterios de al menos 95\,\% y hasta 5\,\% bajo este estimador. No contradicen la disponibilidad de enlace de \DisponibilidadEnlace{}: cambian la cadencia, los huecos excluidos y el denominador. El contador \texttt{SEQ} se añadió después del despliegue y no reconstruye los envíos históricos.

La figura~\ref{fig:resultados-intervalos} muestra las llegadas concentradas cerca de \PeriodoMediano{}: son los intervalos cortos, no la distribución de las interrupciones. Esa regularidad basta para seguir tendencias térmicas a esa cadencia.

\begin{figure}[htbp]
\centering

\caption[Intervalos cortos entre recepciones y cadencia mediana.]{Histograma de los intervalos entre recepciones consecutivas menores de 363~s, con eje de conteo logarítmico; la distribución se concentra alrededor de la mediana de 121~s. Los huecos mayores aparecen en la figura~\ref{fig:resultados-cobertura}. Fuente: figura de \texttt{analisis/figuras\_validacion.py}.}
\label{fig:resultados-intervalos}
\end{figure}

\subsection{Hora representativa seleccionada por cobertura}
\label{sec:resultados-60min}
En la hora del 10 de mayo de 2026, de 00:00 a 01:00, se contaron 29, 30 y 30 registros para A, B y C frente a los 30 esperados por nominal (tabla~\ref{tab:resultados-60min}). El déficit de una muestra en A no dice si fue una pérdida de radio o de otro tipo.

\begin{table}[htbp]
\centering\small
\caption{Cobertura nominal de la ventana representativa de 60 minutos.}
\label{tab:resultados-60min}
\begin{tabular}{lrrr}
\toprule
\textbf{Nodo} & \textbf{Esperados nominales} & \textbf{Recibidos} & \textbf{Recibidos/esperados (\%)} \\
\midrule
A & 30 & 29 & 96.7 \\
B & 30 & 30 & 100.0 \\
C & 30 & 30 & 100.0 \\
\bottomrule
\end{tabular}
\end{table}

La hora se eligió con el criterio de al menos 25 registros por nodo (sección~\ref{sec:metodo-60min}), así que ilustra la continuidad con buena cobertura y no representa todo el despliegue. La figura~\ref{fig:resultados-60min} muestra las temperaturas de esa ventana; corriente, RSSI y latencia no se midieron en ella.

\begin{figure}[htbp]
\centering

\caption[Temperatura durante la hora seleccionada del histórico.]{Temperatura de los tres nodos durante la hora seleccionada del histórico. El término \textit{test} del rótulo original identifica esa ventana ilustrativa; no corresponde a un nuevo ensayo con conteo directo de envíos. Fuente: figura existente de \texttt{analisis/prueba\_60min.py}.}
\label{fig:resultados-60min}
\end{figure}

\section{Concordancia térmica de campo}
\label{sec:resultados-termica}
La comparación de campo usa las fotografías del Fluke 62 MAX sobre el motor del succionador (figura~\ref{fig:resultados-fluke-campo}) cuya hora se pudo recuperar del teléfono. Cada foto se empareja con la lectura del nodo A interpolada en ese instante, de modo que cualquier pareja puede verificarse contra el CSV exportado. La tabla~\ref{tab:resultados-parejas} reúne las siete parejas disponibles.

\begin{table}[htbp]
\centering\small
\caption[Parejas SmartSense y Fluke 62 MAX con hora verificable.]{Parejas de la comparación de campo con hora de la fotografía. SmartSense es la lectura del nodo A interpolada en la hora de la foto; la tasa es el cambio de la superficie en los diez minutos alrededor. Fuente: \texttt{analisis/parejas\_fluke.py}.}
\label{tab:resultados-parejas}
\begin{tabular}{lrrrr}
\toprule
\textbf{Fecha y hora} & \textbf{Fluke (\textdegree C)} & \textbf{SmartSense (\textdegree C)} & $\boldsymbol{\Delta T}$ \textbf{(\textdegree C)} & \textbf{Tasa (\textdegree C/min)} \\
\midrule
10/05 22:54:00 & 37.4 & 33.8 & $-3.6$ & $+0.34$ \\
12/05 14:17:15 & 51.7 & 51.6 & $-0.1$ & $-0.08$ \\
25/05 17:09:02 & 67.7 & 67.6 & $-0.1$ & $-0.01$ \\
25/05 17:15:18 & 67.7 & 67.5 & $-0.2$ & $-0.01$ \\
25/05 19:20:49 & 65.3 & 65.2 & $-0.1$ & $-0.02$ \\
05/06 17:14:19 & 62.5 & 62.3 & $-0.2$ & $-0.04$ \\
05/06 17:30:01 & 61.4 & 61.6 & $+0.2$ & $-0.04$ \\
\bottomrule
\end{tabular}
\end{table}

\begin{figure}[htbp]
\centering
\begin{minipage}[t]{0.42\textwidth}\centering

\end{minipage}\hfill
\begin{minipage}[t]{0.42\textwidth}\centering

\end{minipage}
\caption[Comparación de campo con el Fluke 62 MAX sobre el motor.]{Izquierda: lectura del Fluke 62 MAX apuntando a la carcasa del motor del succionador durante la comparación de campo. Derecha: caja de conexión de la sonda PT100 magnética fijada sobre las aletas del motor. Fuente: registro fotográfico del proyecto.}
\label{fig:resultados-fluke-campo}
\end{figure}

Las seis parejas tomadas con el motor en régimen estable, con cambios menores de 0.1~\textdegree C por minuto, dan una diferencia media con signo de $-\SI{0.07}{\celsius}$, una media absoluta de \DiferenciaTermicaMedia{}, un RMSE de \RMSETermico{} y un máximo de \DiferenciaTermicaMaxima{}, entre 51.6 y \SI{67.6}{\celsius} y en tres visitas distintas. Cinco de las seis diferencias son negativas: SmartSense tiende a marcar una o dos décimas por debajo del Fluke. La pareja del 10 de mayo a las 22:54 se tomó cuando el motor arrancaba después de una parada y la superficie subía 0.34~\textdegree C por minuto; la carcasa que observa el Fluke se calienta antes que el punto de contacto de la sonda magnética, y la diferencia de $-\SI{3.6}{\celsius}$ refleja ese retardo térmico más que un error de medición. Con las siete parejas, la media absoluta sube a \SI{0.64}{\celsius} y el RMSE a \SI{1.37}{\celsius}; ambas cifras se reportan para que la exclusión quede visible.

Otras cinco lecturas de campo, de 65 a \SI{71}{\celsius}, se tomaron en una visita cuyo registro no quedó en el CSV exportado, por lo que no se pueden verificar y se conservan solo como observación, fuera de la estadística.

El Fluke sirvió también para ajustar el offset, así que la comparación no es independiente. Sus especificaciones son $\pm\SI{1.5}{\celsius}$ y las de la FLIR $\pm\SI{2}{\celsius}$, sin certificado vigente del Fluke; la lectura infrarroja depende de la emisividad, el área observada y la geometría, y la PT100 del contacto y la fijación.

Por eso la conclusión es \EstadoTemperatura{}: la tabla no establece una exactitud absoluta menor de \SI{1}{\celsius}. El presupuesto por especificaciones de la sección~\ref{sec:fund-incertidumbre} acota la incertidumbre expandida en \IncertidumbreTipoB{} ($k=2$) a 70~\textdegree C con una sonda de clase B, sin contacto ni montaje; establecer la exactitud requiere una referencia de contacto calibrada y comparaciones independientes del ajuste en varias temperaturas y en los tres nodos \citep{jcgm2012,jcgm2008}. La imagen térmica de la sección~\ref{sec:resultados-succionador} aporta contexto espacial, no validación metrológica.

\section{Alcance y señal recibida}
\label{sec:resultados-alcance}
El ensayo del 20 de agosto de 2026 registró un enlace operativo a \emph{al menos \DistanciaDemostrada{}} en un recorrido urbano con edificios interpuestos y sin línea de vista directa. El RSSI pasó de valores próximos a $-15$~dBm junto al gateway a aproximadamente \RSSILejano{} en el punto más lejano, durante la ventana cercana a 20:44--20:54. La figura~\ref{fig:resultados-alcance} muestra la evolución temporal durante el alejamiento y el regreso.

\begin{figure}[htbp]
\centering

\caption[RSSI y batería durante el recorrido con obstrucciones.]{RSSI y porcentaje indicado de batería durante el recorrido móvil con obstrucciones. El enlace seguía operativo cerca de 688~m; la abscisa es tiempo, no distancia fija controlada. Fuente: figura existente de \texttt{analisis/prueba\_distancia.py}.}
\label{fig:resultados-alcance}
\end{figure}

El recorrido terminó por decisión, así que el resultado es una \EstadoAlcance{}: no se ensayaron posiciones fijas ni se llegó al punto de pérdida. Frente a la sensibilidad típica de ficha del E220-400T22D a 2.4~kbps, $-127$~dBm (entre $-126$ y $-129$), el RSSI de \RSSILejano{} deja un margen cercano a 29~dB \citep{e220manual}, que es un margen sobre el dato del fabricante. Otra planta, con otras estructuras e interferencias, puede comportarse distinto.

El indicador de batería se mantuvo cerca del 94\,\% durante las 2.6~h del ensayo; es el porcentaje derivado de tensión del capítulo~\ref{cap:implementacion}, no una medida de carga consumida. El RSSI es de este ensayo, no del despliegue de mayo y junio, y el módulo no expone SNR.

\section{Intervalo activo y recuperación tras reinicio}
\label{sec:resultados-arranque}
En diez arranques instrumentados, ocho dieron \TiempoActivo{} y los otros dos variaron en milisegundos (uno de ellos, 2.277~s, consta en las capturas del monitor serie). Es el intervalo que el firmware mide entre su marca de arranque y el sueño, y con \PeriodoNominal{} da el ciclo de trabajo de \CicloTrabajo{} de la ecuación~\ref{eq:metodo-duty}.

El intervalo empieza después de inicializar el puerto serie y una pausa de 200~ms (sección~\ref{sec:metodo-autonomia}), así que no incluye el arranque previo ni la recepción en el gateway. La recuperación tras un corte, la recuperación ante bloqueo del enlace y la latencia extremo a extremo requieren ensayos con relojes sincronizados; el criterio de 120~s del anteproyecto se evalúa con esa salvedad en la sección~\ref{sec:resultados-anteproyecto}.
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

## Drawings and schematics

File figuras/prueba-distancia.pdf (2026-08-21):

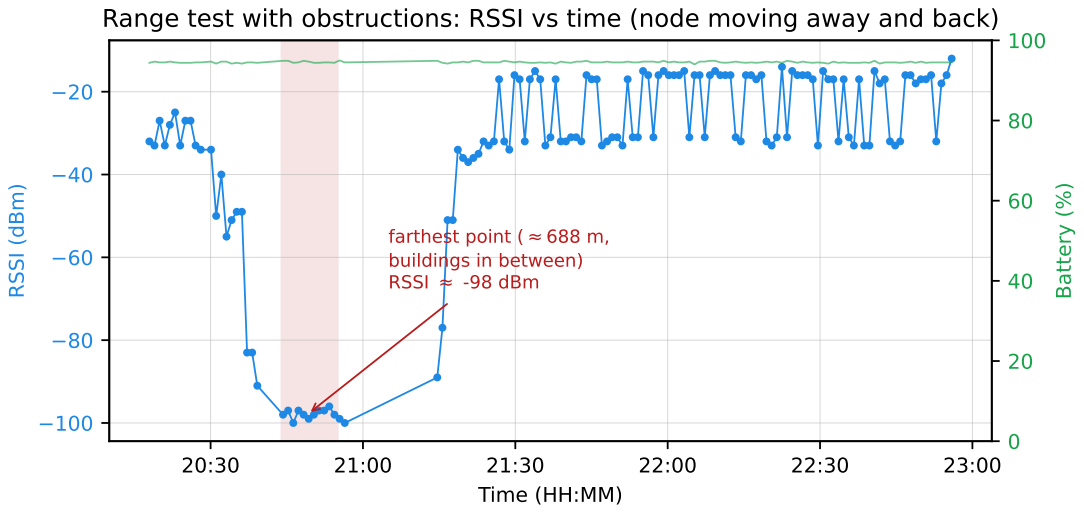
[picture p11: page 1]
RSSI (dBm); Battery (%)

Range test with obstructions: RSSI vs time (node moving away and back)

farthest point ( ≈ 688 m,
RSSI ≈ -98 dBm

buildings in between)

Time (HH:MM)

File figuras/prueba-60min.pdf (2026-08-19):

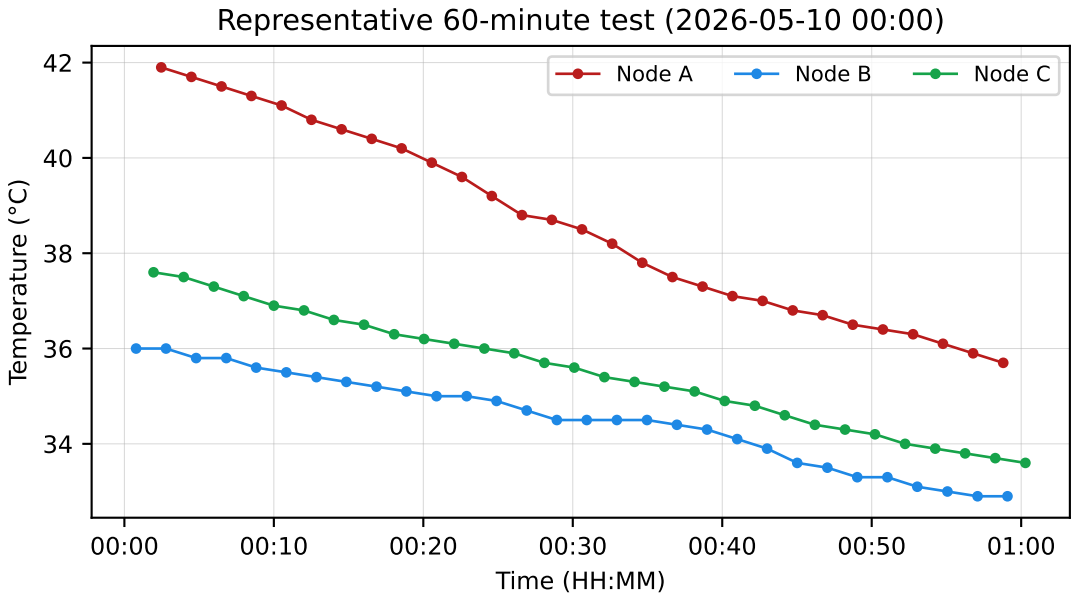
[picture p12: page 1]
Temperature (°C); Node A; Node B; Node C

Representative 60-minute test (2026-05-10 00:00)

Time (HH:MM)

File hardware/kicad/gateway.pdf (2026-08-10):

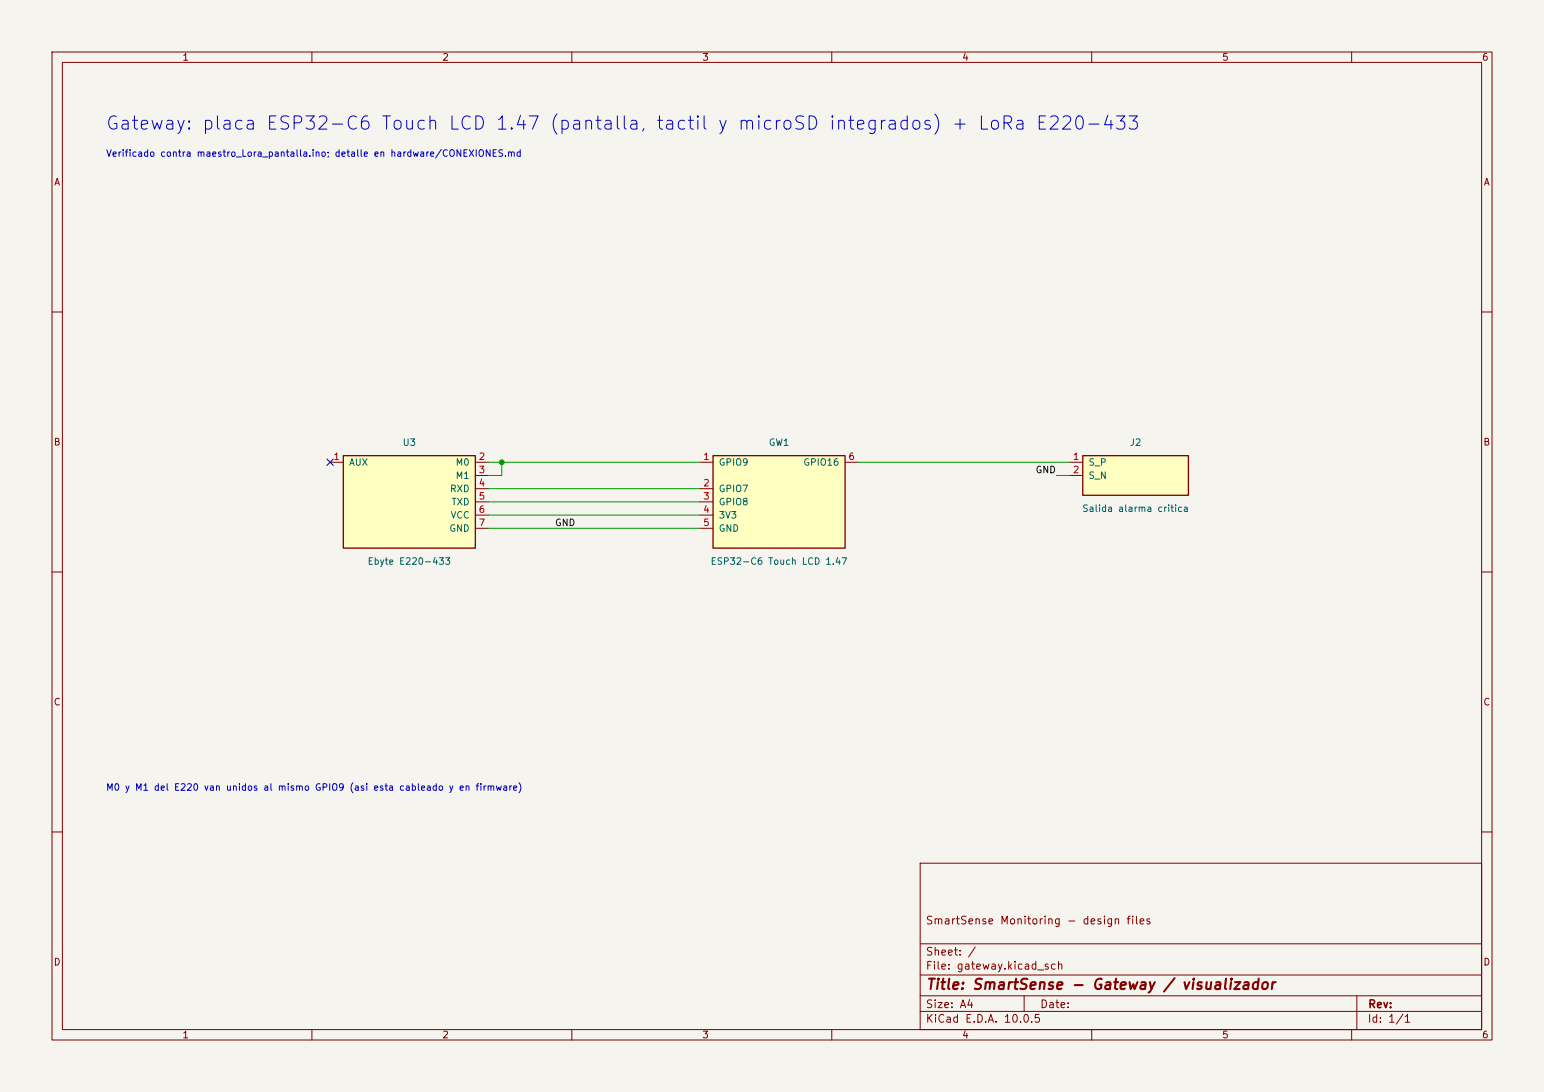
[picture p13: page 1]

GND Gateway: placa ESP32-C6 Touch LCD 1.47 (pantalla, tactil y microSD integrados) + LoRa E220-433

Verificado contra maestro_Lora_pantalla.ino; detalle en hardware/CONEXIONES.md M0 y M1 del E220 van unidos al mismo GPIO9 (asi esta cableado y en firmware)

SmartSense Monitoring - design files

Sheet: /
File: gateway.kicad_sch
Title: SmartSense - Gateway / visualizador

Size: A4 | Rev:
KiCad E.D.A. 10.0.5 | Id: 1/1

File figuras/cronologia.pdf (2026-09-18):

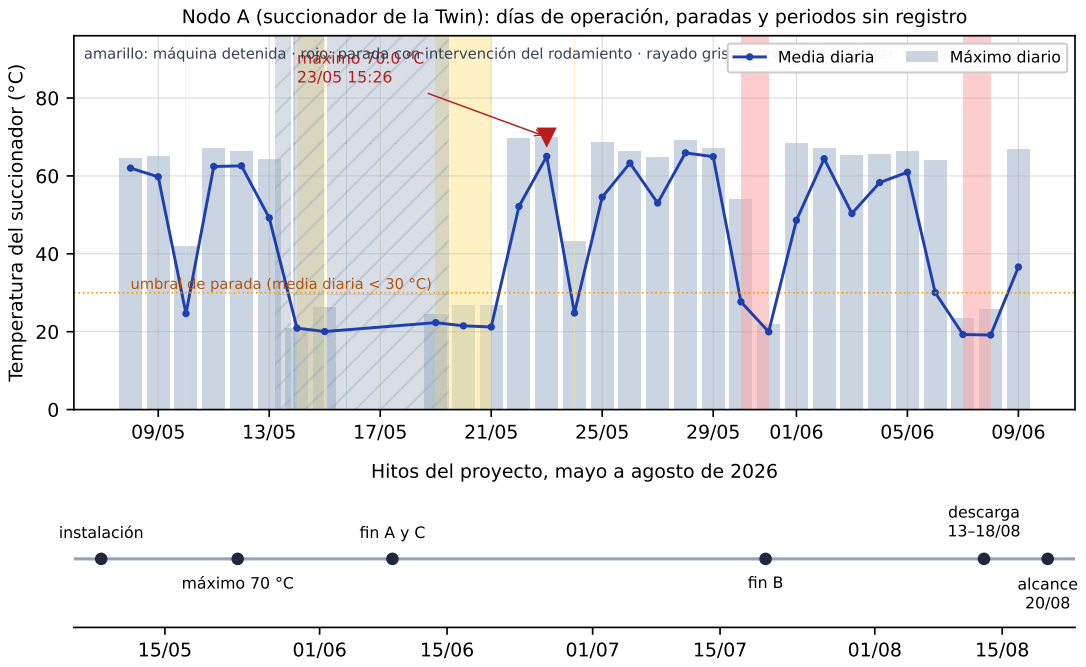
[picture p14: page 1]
máximo 70.0 °C 23/05 15:26; umbral; de parada (media diaria <; Media diaria; Máximo diario; instalación; máximo 70 °C; fin A y C; fin B; descarga 13–18/08; alcance 20/08

Nodo A (succionador de la Twin): días de operación, paradas y periodos sin registro

amarillo: máquina detenida · rojo: parada con intervención del rodamiento · rayado gris: gateway sin registrar

Temperatura del succionador (°C)

Hitos del proyecto, mayo a agosto de 2026

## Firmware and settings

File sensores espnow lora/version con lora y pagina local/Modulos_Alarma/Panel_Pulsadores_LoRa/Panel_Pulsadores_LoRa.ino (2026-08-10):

#include <Arduino.h>
#include <WiFi.h>
#include <ArduinoOTA.h>
#include "driver/gpio.h"
#include "esp_sleep.h"
#include "esp_mac.h"
#include <esp_arduino_version.h>
#include <math.h>

// =====================================================
// PANEL DE PULSADORES LORA
// - 4 botones de emergencia
// - protocolo compacto por ADDR con CRC16 y secuencia
// - envio con ACK y reintentos al central de alarma
// - heartbeat periodico con ACK
// - wake por boton o por timer para heartbeat
// - reset fisico manteniendo los 4 botones 5 segundos
// - si ya hay una alarma activa, una nueva alarma espera
//   500 ms para confirmar que no era el combo de reset
// =====================================================

#define BUTTON_PIN_BITMASK(GPIO) (1ULL << (GPIO))

static constexpr bool AUTO_CONFIGURE_ON_BOOT = false;
static constexpr bool LOG_DEBUG = false;
static constexpr bool ENABLE_BATTERY_MONITOR = false;

#define PANEL_DEBUG_LOGF(...) do { if (LOG_DEBUG) Serial.printf(__VA_ARGS__); } while (0)
#define PANEL_DEBUG_LOGLN(msg) do { if (LOG_DEBUG) Serial.println(msg); } while (0)

static constexpr uint16_t THIS_MODULE_ADDR = 21;
static constexpr uint16_t ALARM_MODULE_ADDR = 2;
static constexpr uint8_t LORA_CHANNEL = 23;

static constexpr int PIN_E220_RX = 17;
static constexpr int PIN_E220_TX = 19;
static constexpr int PIN_E220_M0M1 = 20;


static constexpr int PIN_BTN_FIRE = 5;
static constexpr int PIN_BTN_ACCIDENT = 2;
static constexpr int PIN_BTN_EVAC = 1;
static constexpr int PIN_BTN_MEDICAL = 0;

static constexpr bool BUTTON_ACTIVE_LOW = true;
static constexpr bool OUTPUT_ACTIVE_HIGH = true;
static constexpr int PIN_OUT_FIRE = 22;
static constexpr int PIN_OUT_ACCIDENT = 23;
static constexpr int PIN_OUT_EVAC = 21;
static constexpr int PIN_OUT_MEDICAL = 18;

static constexpr uint32_t PWM_FREQ = 5000;
static constexpr uint8_t PWM_RESOLUTION = 8;
static constexpr uint8_t PWM_DUTY_ACTIVE = 30;  // 30 de 255


static constexpr uint8_t PWM_CH_FIRE = 0;
static constexpr uint8_t PWM_CH_ACCIDENT = 1;
static constexpr uint8_t PWM_CH_EVAC = 2;
static constexpr uint8_t PWM_CH_MEDICAL = 3;


static constexpr unsigned long DEBOUNCE_MS = 45UL;
static constexpr unsigned long INPUT_SCAN_MS = 12UL;
static constexpr unsigned long ACK_RETRY_MS = 3000UL;
static constexpr unsigned long WAIT_LOG_MS = 2000UL;
static constexpr unsigned long HOLD_RESET_MS = 5000UL;
static constexpr unsigned long MULTI_PRESS_GUARD_MS = 500UL;
static constexpr unsigned long HEARTBEAT_INTERVAL_MS = 600000UL;
static constexpr uint64_t HEARTBEAT_WAKE_US = 300000000ULL; // 5 minutos
static constexpr unsigned long SLEEP_IDLE_MS = 1500UL;
static constexpr unsigned long OFFLINE_SEQUENCE_START_MS = 1000UL;
static constexpr unsigned long OFFLINE_SEQUENCE_STEP_MS = 140UL;
static constexpr unsigned long OTA_HOLD_MS = 6000UL; // mantener FIRE + MEDICAL por 6 segundos
static constexpr unsigned long OTA_WIFI_RETRY_MS = 10000UL;
static constexpr unsigned long OTA_READY_SEQUENCE_STEP_MS = 110UL;
static constexpr bool ENABLE_DEEP_SLEEP = true;
static constexpr int PANEL_BATTERY_ADC_PIN = -1; // Configura aqui el pin ADC real del divisor de bateria
static constexpr float BAT_R1_OHM = 344800.0f;
static constexpr float BAT_R2_OHM = 994300.0f;
static constexpr float BAT_CAL_K = 1.000f;
static constexpr float BAT_CAL_B = 0.090f;
static constexpr float BAT_VMIN = 3.30f;
static constexpr float BAT_VMAX = 4.10f;
static constexpr int BAT_SAMPLES = 1;

// OTA_WIFI_SSID / OTA_WIFI_PASS / OTA_UPDATE_PASSWORD en secrets.h
// (no versionado; copiar secrets.example.h como secrets.h)
#include "secrets.h"
static constexpr int OTA_BTN_FIRE = PIN_BTN_FIRE;
static constexpr int OTA_BTN_MEDICAL = PIN_BTN_MEDICAL;

static constexpr int UART_BAUD_CODE = 3;
static constexpr int UART_PARITY_CODE = 0;
static constexpr int AIR_RATE_CODE = 2;
static constexpr int TRANS_MODE_CODE = 1;
static constexpr int PACKET_LEN_CODE = 0;
static constexpr int URXT_BYTE_TIME = 3;
static constexpr int POWER_CODE = 0;
static constexpr int KEY_CODE = 0;
static constexpr int LBT_CODE = 0;

struct ButtonConfig {
  int pin;
  int outputPin;
  uint8_t pwmChannel;
  const char* type;
  const char* label;
};

static constexpr ButtonConfig BUTTONS[] = {
  { PIN_BTN_FIRE, PIN_OUT_FIRE, PWM_CH_FIRE, "FIRE", "Incendio" },
  { PIN_BTN_ACCIDENT, PIN_OUT_ACCIDENT, PWM_CH_ACCIDENT, "ACCIDENT", "Accidente" },
  { PIN_BTN_EVAC, PIN_OUT_EVAC, PWM_CH_EVAC, "EVACUATION", "Evacuacion" },
  { PIN_BTN_MEDICAL, PIN_OUT_MEDICAL, PWM_CH_MEDICAL, "MEDICAL", "Auxilio medico" },
};

static constexpr size_t BUTTON_COUNT = sizeof(BUTTONS) / sizeof(BUTTONS[0]);

enum PendingMessageKind : uint8_t {
  PENDING_NONE = 0,
  PENDING_EVENT = 1,
  PENDING_HEARTBEAT = 2
};

struct PendingTx {
  bool active = false;
  PendingMessageKind kind = PENDING_NONE;
  bool desiredState = false;
  int buttonIndex = -1;
  uint32_t seq = 0;
  uint32_t sendCount = 0;
  unsigned long createdMs = 0;
  unsigned long lastSendMs = 0;
  unsigned long lastLogMs = 0;
  String payload;
};

struct DelayedAlarmTrigger {
  bool active = false;
  int buttonIndex = -1;
  unsigned long dueMs = 0;
};

RTC_DATA_ATTR uint32_t rtcWakeCounter = 0;
RTC_DATA_ATTR uint32_t rtcNextSequence = 1;

String panelUid;
bool lastStableState[BUTTON_COUNT] = { false, false, false, false };
unsigned long lastStableChangeMs[BUTTON_COUNT] = { 0, 0, 0, 0 };
unsigned long lastInputScanMs = 0;
unsigned long allPressedSinceMs = 0;
bool holdResetTriggered = false;

String radioLine;
bool radioOverflow = false;
PendingTx pendingTx;
DelayedAlarmTrigger delayedAlarmTrigger;
unsigned long lastAcceptedAlarmPressMs = 0;
int currentActiveButton = -1;
unsigned long lastActivityMs = 0;
unsigned long nextHeartbeatDueMs = 0;
uint64_t lastWakeGpioMask = 0;
size_t offlineSequenceIndex = 0;
unsigned long offlineSequenceStepStartedMs = 0;
size_t otaReadySequenceIndex = 0;
unsigned long otaReadySequenceStepStartedMs = 0;
unsigned long otaComboSinceMs = 0;
unsigned long otaLastConnectAttemptMs = 0;
bool otaModeActive = false;
bool otaReady = false;
char otaHostname[24] = { 0 };
int lastBatteryPercent = -1;

bool isPressedRaw(int pin) {
  const int state = digitalRead(pin);
  return BUTTON_ACTIVE_LOW ? (state == LOW) : (state == HIGH);
}

void markActivity() {
  lastActivityMs = millis();
}

void setupPwmOutput(int pin, uint8_t channel) {
#if ESP_ARDUINO_VERSION_MAJOR >= 3
  ledcAttachChannel(pin, PWM_FREQ, PWM_RESOLUTION, channel);
#else
  ledcSetup(channel, PWM_FREQ, PWM_RESOLUTION);
  ledcAttachPin(pin, channel);
#endif
}

void writePwmOutput(int pin, uint8_t channel, uint8_t duty) {
#if ESP_ARDUINO_VERSION_MAJOR >= 3
  ledcWrite(pin, duty);
#else
  ledcWrite(channel, duty);
#endif
}

uint8_t getPwmChannelByPin(int pin) {
  for (size_t i = 0; i < BUTTON_COUNT; ++i) {
    if (BUTTONS[i].outputPin == pin) {
      return BUTTONS[i].pwmChannel;
    }
  }
  return 0;
}

void writeAlarmOutput(int pin, bool active) {
  const uint8_t channel = getPwmChannelByPin(pin);
  uint8_t duty = 0;

  if (OUTPUT_ACTIVE_HIGH) {
    duty = active ? PWM_DUTY_ACTIVE : 0;
  } else {
    duty = active ? 0 : PWM_DUTY_ACTIVE;
  }

  writePwmOutput(pin, channel, duty);
}

bool batteryMonitorConfigured() {
  return ENABLE_BATTERY_MONITOR && PANEL_BATTERY_ADC_PIN >= 0;
}

void setupBatteryADC() {
  if (!batteryMonitorConfigured()) return;
  analogReadResolution(12);
  analogSetPinAttenuation(PANEL_BATTERY_ADC_PIN, ADC_11db);
  pinMode(PANEL_BATTERY_ADC_PIN, INPUT);
}

float readBatteryVoltage() {
  if (!batteryMonitorConfigured()) return NAN;

  uint32_t acc = 0;
  for (int i = 0; i < BAT_SAMPLES; ++i) {
    acc += static_cast<uint32_t>(analogReadMilliVolts(PANEL_BATTERY_ADC_PIN));
    delay(2);
  }

  float mvAdc = static_cast<float>(acc) / static_cast<float>(BAT_SAMPLES);
  float vAdc = mvAdc / 1000.0f;
  float vBat = vAdc * ((BAT_R1_OHM + BAT_R2_OHM) / BAT_R2_OHM);
  vBat = vBat * BAT_CAL_K + BAT_CAL_B;

  if (vBat < 0.0f) vBat = 0.0f;
  if (vBat > 6.0f) vBat = 6.0f;
  return vBat;
}

float batteryPercentFromVoltage(float vbat) {
  float pct = (vbat - BAT_VMIN) / (BAT_VMAX - BAT_VMIN);
  if (pct < 0.0f) pct = 0.0f;
  if (pct > 1.0f) pct = 1.0f;
  return pct * 100.0f;
}

int readBatteryPercent() {
  if (!batteryMonitorConfigured()) return -1;
  const float vbat = readBatteryVoltage();
  if (!isfinite(vbat)) return -1;
  const float pct = batteryPercentFromVoltage(vbat);
  int result = static_cast<int>(lroundf(pct));
  if (result < 0) result = 0;
  if (result > 100) result = 100;
  return result;
}

void updateAlarmOutputs() {
  for (size_t i = 0; i < BUTTON_COUNT; ++i) {
    writeAlarmOutput(BUTTONS[i].outputPin, static_cast<int>(i) == currentActiveButton);
  }
}

void resetOfflineLinkSequence() {
  offlineSequenceIndex = 0;
  offlineSequenceStepStartedMs = 0;
}

void resetOtaReadySequence() {
  otaReadySequenceIndex = 0;
  otaReadySequenceStepStartedMs = 0;
}

void disconnectOtaWifi() {
  if (WiFi.getMode() != WIFI_OFF) {
    WiFi.disconnect(true, true);
    WiFi.mode(WIFI_OFF);
  }
}

bool shouldAnimateOfflineLink(unsigned long now) {
  if (currentActiveButton >= 0) return false;
  if (!pendingTx.active || pendingTx.kind != PENDING_HEARTBEAT) return false;
  return (now - pendingTx.createdMs) >= OFFLINE_SEQUENCE_START_MS;
}

void applyOfflineLinkSequence() {
  const uint8_t phase = static_cast<uint8_t>(offlineSequenceIndex % 4);
  const bool fireAndMedicalOn = (phase == 0);
  const bool accidentAndEvacOn = (phase == 2);

  writeAlarmOutput(PIN_OUT_FIRE, fireAndMedicalOn);
  writeAlarmOutput(PIN_OUT_MEDICAL, fireAndMedicalOn);
  writeAlarmOutput(PIN_OUT_ACCIDENT, accidentAndEvacOn);
  writeAlarmOutput(PIN_OUT_EVAC, accidentAndEvacOn);
}

void applyOtaReadySequence() {
  const uint8_t phase = static_cast<uint8_t>(otaReadySequenceIndex % 6);
  const bool fireAndMedicalOn = (phase % 2) == 0;
  const bool accidentAndEvacOn = phase < 3;

  writeAlarmOutput(PIN_OUT_FIRE, fireAndMedicalOn);
  writeAlarmOutput(PIN_OUT_MEDICAL, fireAndMedicalOn);
  writeAlarmOutput(PIN_OUT_ACCIDENT, accidentAndEvacOn);
  writeAlarmOutput(PIN_OUT_EVAC, accidentAndEvacOn);
}

void serviceOfflineLinkSequence(unsigned long now) {
  if (!shouldAnimateOfflineLink(now)) {
    if (offlineSequenceStepStartedMs != 0 || offlineSequenceIndex != 0) {
      resetOfflineLinkSequence();
      updateAlarmOutputs();
    }
    return;
  }

  if (offlineSequenceStepStartedMs == 0) {
    offlineSequenceStepStartedMs = now;
    offlineSequenceIndex = 0;
    applyOfflineLinkSequence();
    return;
  }

  if ((now - offlineSequenceStepStartedMs) < OFFLINE_SEQUENCE_STEP_MS) return;

  offlineSequenceStepStartedMs = now;
  offlineSequenceIndex = (offlineSequenceIndex + 1) % 4;
  applyOfflineLinkSequence();
}

bool shouldAnimateOtaReady() {
  return otaModeActive && otaReady && WiFi.status() == WL_CONNECTED;
}

void serviceOtaReadySequence(unsigned long now) {
  if (!shouldAnimateOtaReady()) {
    if (otaReadySequenceStepStartedMs != 0 || otaReadySequenceIndex != 0) {
      resetOtaReadySequence();
      updateAlarmOutputs();
    }
    return;
  }

  if (otaReadySequenceStepStartedMs == 0) {
    otaReadySequenceStepStartedMs = now;
    otaReadySequenceIndex = 0;
    applyOtaReadySequence();
    return;
  }

  if ((now - otaReadySequenceStepStartedMs) < OTA_READY_SEQUENCE_STEP_MS) return;

  otaReadySequenceStepStartedMs = now;
  otaReadySequenceIndex = (otaReadySequenceIndex + 1) % 6;
  applyOtaReadySequence();
}

void setModeConfig() {
  digitalWrite(PIN_E220_M0M1, HIGH);
  delay(80);
}

void setModeNormal() {
  digitalWrite(PIN_E220_M0M1, LOW);
  delay(80);
}

void clearRadioInput() {
  while (Serial1.available() > 0) {
    Serial1.read();
  }
}

String readATResponse(uint32_t timeoutMs = 800) {
  String out;
  uint32_t t0 = millis();

  while ((millis() - t0) < timeoutMs) {
    while (Serial1.available() > 0) {
      const char c = static_cast<char>(Serial1.read());
      out += c;
      t0 = millis();
    }
  }

  out.trim();
  return out;
}

bool sendAT(const String& cmd, const char* expected = "=OK", uint32_t timeoutMs = 800) {
  clearRadioInput();

  Serial.print("[E220][TX] ");
  Serial.println(cmd);

  Serial1.print(cmd);
  Serial1.print("\r\n");

  const String resp = readATResponse(timeoutMs);
  Serial.print("[E220][RX] ");
  Serial.println(resp.length() ? resp : "<sin respuesta>");

  if (!expected || expected[0] == '\0') return true;
  return resp.indexOf(expected) >= 0;
}

bool queryAT(const String& cmd, uint32_t timeoutMs = 800) {
  clearRadioInput();

  Serial.print("[E220][TX] ");
  Serial.println(cmd);

  Serial1.print(cmd);
  Serial1.print("\r\n");

  const String resp = readATResponse(timeoutMs);
  Serial.print("[E220][RX] ");
  Serial.println(resp.length() ? resp : "<sin respuesta>");

  return resp.length() > 0;
}

bool configureE220() {
  bool ok = true;

  Serial.println("[E220] Entrando en modo configuracion...");

  ok &= queryAT("AT+DEVTYPE=?");
  ok &= queryAT("AT+FWCODE=?");
  ok &= sendAT("AT+ADDR=" + String(THIS_MODULE_ADDR));
  ok &= sendAT("AT+CHANNEL=" + String(LORA_CHANNEL));
  ok &= sendAT("AT+UART=" + String(UART_BAUD_CODE) + "," + String(UART_PARITY_CODE));
  ok &= sendAT("AT+RATE=" + String(AIR_RATE_CODE));
  ok &= sendAT("AT+TRANS=" + String(TRANS_MODE_CODE));
  ok &= sendAT("AT+PACKET=" + String(PACKET_LEN_CODE));
  ok &= sendAT("AT+URXT=" + String(URXT_BYTE_TIME));
  ok &= sendAT("AT+KEY=" + String(KEY_CODE));
  ok &= sendAT("AT+LBT=" + String(LBT_CODE));
  ok &= sendAT("AT+POWER=" + String(POWER_CODE));

  Serial.printf("[E220] Configuracion final: %s\n", ok ? "OK" : "ERROR");
  return ok;
}

bool bootConfigureIfEnabled() {
  if (!AUTO_CONFIGURE_ON_BOOT) {
    return true;
  }

  setModeConfig();
  delay(150);

  Serial1.begin(9600, SERIAL_8N1, PIN_E220_RX, PIN_E220_TX);
  delay(200);

  const bool ok = configureE220();

  setModeNormal();
  delay(150);

  Serial1.end();
  delay(50);

  return ok;
}

String getFieldValue(const String& line, const String& key) {
  const String needle = key + "=";
  const int start = line.indexOf(needle);
  if (start < 0) return "";

  const int valueStart = start + needle.length();
  int end = line.indexOf(',', valueStart);
  if (end < 0) end = line.length();
  return line.substring(valueStart, end);
}

bool parseUInt32Field(const String& value, uint32_t& out) {
  if (value.isEmpty()) return false;
  char* end = nullptr;
  const unsigned long parsed = strtoul(value.c_str(), &end, 10);
  if (end == value.c_str() || *end != '\0') return false;
  out = static_cast<uint32_t>(parsed);
  return true;
}

String normalizeUid(String uid) {
  String out;
  out.reserve(uid.length());
  for (size_t i = 0; i < uid.length(); ++i) {
    const char c = uid[i];
    if (isAlphaNumeric(static_cast<unsigned char>(c))) {
      out += static_cast<char>(toupper(static_cast<unsigned char>(c)));
    }
  }
  return out;
}

uint16_t crc16Ccitt(const uint8_t* data, size_t len) {
  uint16_t crc = 0xFFFF;
  for (size_t i = 0; i < len; ++i) {
    crc ^= static_cast<uint16_t>(data[i]) << 8;
    for (uint8_t bit = 0; bit < 8; ++bit) {
      if (crc & 0x8000) {
        crc = static_cast<uint16_t>((crc << 1) ^ 0x1021);
      } else {
        crc <<= 1;
      }
    }
  }
  return crc;
}

String formatHex16(uint16_t value) {
  char buffer[5];
  snprintf(buffer, sizeof(buffer), "%04X", value);
  return String(buffer);
}

bool parseHex16(String text, uint16_t& out) {
  text.trim();
  if (text.length() != 4) return false;
  char* end = nullptr;
  const unsigned long parsed = strtoul(text.c_str(), &end, 16);
  if (end == text.c_str() || *end != '\0' || parsed > 0xFFFFUL) return false;
  out = static_cast<uint16_t>(parsed);
  return true;
}

String buildProtocolFrame(const String& body) {
  const uint16_t crc = crc16Ccitt(reinterpret_cast<const uint8_t*>(body.c_str()), body.length());
  return String("!") + body + "*" + formatHex16(crc);
}

bool extractProtocolBody(String line, String& bodyOut) {
  line.trim();
  const int start = line.indexOf('!');
  if (start < 0) return false;
  const int star = line.indexOf('*', start + 1);
  if (star < 0) return false;

  const String body = line.substring(start + 1, star);
  String crcText = line.substring(star + 1);
  crcText.trim();
  if (crcText.length() < 4) return false;
  crcText = crcText.substring(0, 4);

  uint16_t expected = 0;
  if (!parseHex16(crcText, expected)) return false;

  const uint16_t actual = crc16Ccitt(reinterpret_cast<const uint8_t*>(body.c_str()), body.length());
  if (actual != expected) return false;

  bodyOut = body;
  return true;
}

int splitCsvFields(const String& text, String fields[], int maxFields) {
  int count = 0;
  int start = 0;
  while (count < maxFields) {
    const int comma = text.indexOf(',', start);
    if (comma < 0) {
      fields[count++] = text.substring(start);
      break;
    }
    fields[count++] = text.substring(start, comma);
    start = comma + 1;
  }
  return count;
}

bool parseProtocolFrame(String line, char& cmdOut, String fields[], int& fieldCountOut) {
  String body;
  if (!extractProtocolBody(line, body)) return false;
  fieldCountOut = splitCsvFields(body, fields, 8);
  if (fieldCountOut <= 0 || fields[0].isEmpty()) return false;
  cmdOut = fields[0].charAt(0);
  return true;
}

uint8_t buttonIndexToTypeCode(int buttonIndex) {
  if (buttonIndex < 0 || buttonIndex >= static_cast<int>(BUTTON_COUNT)) return 0;
  return static_cast<uint8_t>(buttonIndex + 1);
}

int typeCodeToButtonIndex(uint8_t typeCode) {
  if (typeCode == 0 || typeCode > BUTTON_COUNT) return -1;
  return static_cast<int>(typeCode - 1);
}

String protocolTypeLabel(uint8_t typeCode) {
  const int index = typeCodeToButtonIndex(typeCode);
  if (index < 0) return "";
  return String(BUTTONS[index].type);
}

String readPanelUid() {
  uint8_t mac[6] = { 0 };
  if (esp_read_mac(mac, ESP_MAC_WIFI_STA) != ESP_OK) {
    return "000000000000";
  }

  char buffer[13];
  snprintf(buffer,
           sizeof(buffer),
           "%02X%02X%02X%02X%02X%02X",
           mac[0],
           mac[1],
           mac[2],
           mac[3],
           mac[4],
           mac[5]);
  return String(buffer);
}

String panelShortUid() {
  if (panelUid.length() <= 4) return panelUid;
  return panelUid.substring(panelUid.length() - 4);
}

String debugRadioText(const String& text) {
  String out;
  out.reserve(text.length() * 4);
  for (size_t i = 0; i < text.length(); ++i) {
    const uint8_t c = static_cast<uint8_t>(text.charAt(i));
    if (c >= 32 && c <= 126) {
      out += static_cast<char>(c);
    } else {
      char buf[5];
      snprintf(buf, sizeof(buf), "\\x%02X", c);
      out += buf;
    }
  }
  return out;
}

String friendlyAlarmType(String type) {
  type.trim();
  type.toUpperCase();
  if (type == "FIRE") return "Incendio";
  if (type == "ACCIDENT") return "Accidente";
  if (type == "EVACUATION") return "Evacuacion";
  if (type == "MEDICAL") return "Auxilio medico";
  return type;
}

void sendAddressed(uint16_t addr, const String& msg) {
  const uint8_t addrH = (addr >> 8) & 0xFF;
  const uint8_t addrL = addr & 0xFF;
  Serial1.write(addrH);
  Serial1.write(addrL);
  Serial1.write(LORA_CHANNEL);
  Serial1.print(msg);
  Serial1.print("\n");
  Serial1.flush();
  delay(25);
  markActivity();
}

String buildEventMessage(int buttonIndex, bool state, uint32_t seq) {
  const uint8_t typeCode = buttonIndexToTypeCode(buttonIndex);
  const String body = String("E,") + String(THIS_MODULE_ADDR)
                    + "," + String(typeCode)
                    + "," + (state ? "1" : "0")
                    + "," + String(seq);
  return buildProtocolFrame(body);
}

String buildHeartbeatMessage(uint32_t seq) {
  const uint8_t typeCode = buttonIndexToTypeCode(currentActiveButton);
  lastBatteryPercent = readBatteryPercent();
  String body = String("H,") + String(THIS_MODULE_ADDR)
              + "," + (currentActiveButton >= 0 ? "1" : "0")
              + "," + String(typeCode)
              + "," + String(seq);
  if (lastBatteryPercent >= 0) {
    body += "," + String(lastBatteryPercent);
  }
  return buildProtocolFrame(body);
}

String buildAckMessage(char ackFor, uint32_t seq) {
  const String body = String("K,") + String(THIS_MODULE_ADDR)
                    + "," + String(ackFor)
                    + "," + String(seq);
  return buildProtocolFrame(body);
}

void sendPendingTx(unsigned long now) {
  if (!pendingTx.active) return;

  sendAddressed(ALARM_MODULE_ADDR, pendingTx.payload);
  pendingTx.lastSendMs = now;
  pendingTx.sendCount++;

  if (pendingTx.kind == PENDING_EVENT) {
    PANEL_DEBUG_LOGF("[PANEL][TX #%lu] %s\n",
                     static_cast<unsigned long>(pendingTx.sendCount),
                     pendingTx.payload.c_str());
  } else if (pendingTx.kind == PENDING_HEARTBEAT) {
    PANEL_DEBUG_LOGF("[PANEL][HB TX #%lu] uid=%s seq=%lu\n",
                     static_cast<unsigned long>(pendingTx.sendCount),
                     panelUid.c_str(),
                     static_cast<unsigned long>(pendingTx.seq));
  }
}

uint32_t nextSequence() {
  return rtcNextSequence++;
}
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
void loop() {
  const unsigned long now = millis();
  handleRadioRx();
  scanButtons();
  serviceHoldReset(now);
  serviceOtaTrigger(now);
  serviceDelayedAlarmTrigger(now);
  servicePendingTx(now);
  serviceHeartbeat(now);
  serviceOfflineLinkSequence(now);
  serviceOtaMode(now);
  readUsbSerial();
  serviceSleep(now);
}

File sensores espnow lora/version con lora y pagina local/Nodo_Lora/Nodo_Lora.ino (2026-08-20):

#include <Arduino.h>
#include <Preferences.h>
#include <esp_system.h>
#include <esp_mac.h>
#include <SPI.h>
#include <Adafruit_MAX31865.h>
#include <math.h>

// =====================================================
// CONFIG GENERAL
// =====================================================
static constexpr bool AUTO_CONFIGURE_ON_BOOT = false;
static constexpr uint16_t CONFIG_WINDOW_CYCLES = 30; // si dep seleep 120 entonces son 60 minutos para configurar

// =========================
// E220 - XIAO ESP32-C6
// =========================
static constexpr int PIN_E220_RX = 17;  // D7  <- TXD del E220
static constexpr int PIN_E220_TX = 19;  // D8  -> RXD del E220
static constexpr int PIN_E220_M0 = 18;  // D10
static constexpr int PIN_E220_M1 = 20;  // D9

// Dirección propia del nodo y destino maestro
static constexpr uint16_t NODE_ADDR = 13;
static constexpr uint8_t NODE_CH = 23;

static constexpr uint16_t MASTER_ADDR = 1;
static constexpr uint8_t MASTER_CH = 23;

// =========================
// CONFIGURACIÓN POR DEFECTO
// =========================
#define DEFAULT_SLEEP_TIME 60

// =========================
// PINES MAX31865 (SPI software)
// =========================
#define PIN_SCK  16
#define PIN_MISO 23
#define PIN_MOSI 22
#define PIN_CS   21

// =========================
// PIN ACTIVAR SENSOR
// =========================
#define PIN_SENSOR_PWR 2

// =========================
// LECTURA BATERÍA
// =========================
#define BAT_ADC_PIN 0

#define BAT_R1_OHM 344800.0f
#define BAT_R2_OHM 994300.0f

#define BAT_CAL_K 1.000f
#define BAT_CAL_B 0.090f

#define BAT_VMIN 3.30f
#define BAT_VMAX 4.10f

#define BAT_SAMPLES 1

// =========================
// CONFIG PT100
// =========================
#define RREF 421.1f
#define RNOMINAL 100.0f

// =========================
// DEBUG
// =========================
#define DBG 1
#if DBG
  #define DPRINT(...) Serial.print(__VA_ARGS__)
  #define DPRINTLN(...) Serial.println(__VA_ARGS__)
  #define DPRINTF(...) Serial.printf(__VA_ARGS__)
#else
  #define DPRINT(...)
  #define DPRINTLN(...)
  #define DPRINTF(...)
#endif

// =========================
// CÓDIGOS AT E220
// =========================
static constexpr int UART_BAUD_CODE   = 3;   // 9600
static constexpr int UART_PARITY_CODE = 0;   // none
static constexpr int AIR_RATE_CODE    = 2;   // 2.4kbps
static constexpr int TRANS_MODE_CODE  = 1;   // fixed
static constexpr int PACKET_LEN_CODE  = 0;   // 200 bytes
static constexpr int URXT_BYTE_TIME   = 3;
static constexpr int POWER_CODE       = 0;
static constexpr int KEY_CODE         = 0;
static constexpr int LBT_CODE         = 0;

// =========================
// OBJETOS
// =========================
Preferences prefs;
Adafruit_MAX31865 rtd(PIN_CS, PIN_MOSI, PIN_MISO, PIN_SCK);

// =========================
// CONFIG ACTUAL
// =========================
uint32_t sleepTime = DEFAULT_SLEEP_TIME;
uint16_t configCyclesRemaining = CONFIG_WINDOW_CYCLES;

// =========================
// TIMING / ESTADO
// =========================
static uint32_t bootMs = 0;
static String radioRxLine;
static bool g_gotConfigReply = false;

// Contador de paquetes para calcular PDR en el gateway.
// RTC_DATA_ATTR sobrevive al deep sleep; se reinicia solo al cortar la
// alimentación (el gateway detecta ese reinicio porque SEQ vuelve a 1).
RTC_DATA_ATTR uint32_t txSeq = 0;

// =====================================================
// DECLARACIONES ADELANTADAS
// =====================================================
static void saveConfig();

// =====================================================
// UTILIDADES
// =====================================================
static void getMyMac(uint8_t* mac) {
  esp_read_mac(mac, ESP_MAC_WIFI_STA);
}

static String macToString(const uint8_t* mac) {
  char buf[18];
  snprintf(buf, sizeof(buf), "%02X:%02X:%02X:%02X:%02X:%02X",
           mac[0], mac[1], mac[2], mac[3], mac[4], mac[5]);
  return String(buf);
}

static String getMacString() {
  uint8_t mac[6];
  getMyMac(mac);
  return macToString(mac);
}

static void printWakeReason() {
  esp_sleep_wakeup_cause_t c = esp_sleep_get_wakeup_cause();
  DPRINT("[BOOT] wake_cause=");
  switch (c) {
    case ESP_SLEEP_WAKEUP_TIMER:    DPRINTLN("TIMER"); break;
    case ESP_SLEEP_WAKEUP_EXT0:     DPRINTLN("EXT0"); break;
    case ESP_SLEEP_WAKEUP_EXT1:     DPRINTLN("EXT1"); break;
    case ESP_SLEEP_WAKEUP_TOUCHPAD: DPRINTLN("TOUCH"); break;
    case ESP_SLEEP_WAKEUP_ULP:      DPRINTLN("ULP"); break;
    default:                        DPRINTLN("POWERON/OTHER"); break;
  }
}

static void printCurrentConfig(const char* tag) {
  DPRINTF("[%s] sleep=%lus mac=%s cfg_cycles=%u\n",
          tag,
          (unsigned long)sleepTime,
          getMacString().c_str(),
          configCyclesRemaining);
}

static void handleConfigWindowByWakeCause() {
  esp_sleep_wakeup_cause_t cause = esp_sleep_get_wakeup_cause();

  if (cause == ESP_SLEEP_WAKEUP_TIMER) {
    if (configCyclesRemaining > 0) {
      configCyclesRemaining--;
      DPRINTF("[CFG_WINDOW] wake=TIMER -> ciclos restantes: %u\n", configCyclesRemaining);
      saveConfig();
    } else {
      DPRINTLN("[CFG_WINDOW] wake=TIMER -> ventana cerrada");
    }
  } else {
    configCyclesRemaining = CONFIG_WINDOW_CYCLES;
    DPRINTF("[CFG_WINDOW] wake=POWERON/OTHER -> ventana reiniciada a %u ciclos\n",
            CONFIG_WINDOW_CYCLES);
    saveConfig();
  }
}

// =====================================================
// PERSISTENCIA
// =====================================================
static void loadConfig() {
  prefs.begin("cfg", true);
  sleepTime = prefs.getUInt("sleep", DEFAULT_SLEEP_TIME);
  configCyclesRemaining = prefs.getUShort("cfg_cycles", CONFIG_WINDOW_CYCLES);
  prefs.end();

  if (sleepTime < 5) sleepTime = 5;
  if (sleepTime > 7200) sleepTime = 7200;
}

static void saveConfig() {
  prefs.begin("cfg", false);
  prefs.putUInt("sleep", sleepTime);
  prefs.putUShort("cfg_cycles", configCyclesRemaining);
  prefs.end();
}

// =====================================================
// BATERÍA
// =====================================================
static void setupBatteryADC() {
  analogReadResolution(12);
  analogSetPinAttenuation(BAT_ADC_PIN, ADC_11db);

  pinMode(BAT_ADC_PIN, INPUT);
  pinMode(PIN_SENSOR_PWR, OUTPUT);
  digitalWrite(PIN_SENSOR_PWR, LOW);
}

static float readBatteryVoltage() {
  uint32_t acc = 0;

  for (int i = 0; i < BAT_SAMPLES; i++) {
    acc += (uint32_t)analogReadMilliVolts(BAT_ADC_PIN);
    delay(2);
  }

  float mv_adc = (float)acc / (float)BAT_SAMPLES;
  float v_adc = mv_adc / 1000.0f;
  float v_bat = v_adc * ((BAT_R1_OHM + BAT_R2_OHM) / BAT_R2_OHM);
  v_bat = v_bat * BAT_CAL_K + BAT_CAL_B;

  if (v_bat < 0.0f) v_bat = 0.0f;
  if (v_bat > 6.0f) v_bat = 6.0f;

  //DPRINTF("[BAT] adc=%.1f mV v_adc=%.3f V v_bat=%.3f V\n",(double)mv_adc, (double)v_adc, (double)v_bat);

  return v_bat;
}
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

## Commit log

2026-08-10 Mover credenciales del firmware a secrets.h no versionado
    Los 4 sketches con claves WiFi/OTA/AP quemadas ahora incluyen secrets.h
    (gitignored); se versiona secrets.example.h como plantilla. Las claves del
    historial deben rotarse antes de hacer publico el repo.
2026-08-10 Agregar replica Docker con carga masiva CSV y dashboard neutro
    Flask + SQLite en un servicio. Boton de importacion masiva de exportes CSV
    (acepta ; o , y coma decimal), historico por sensor con grafica y
    estadisticas, branding configurable por .env. Puerto 8500 (8080-8161
    ocupados por otros servicios locales). Validaciones de archivo, encabezado,
    rango fisico PT100 y fechas; selftest incluido.
2026-08-10 Agregar design files KiCad, BOM y plantilla oficial HardwareX
    Esquematicos de nodo y gateway generados por gen_esquematicos.py con
    cableado real, validados con kicad-cli ERC (0 errores, 0 advertencias) y
    exportados a PDF/SVG. Tabla de conexiones verificada contra el firmware,
    BOM en formato HardwareX y plantilla oficial del journal (Zenodo, CC-BY).
    [BOM.csv, gateway.kicad_sch, nodo_sensor.kicad_sch]
2026-08-10 Insertar esquematicos y arquitectura como figuras del articulo IEEE
    Reemplaza el placeholder de arquitectura por la figura real del
    anteproyecto y agrega los esquematicos recortados del nodo y el gateway
    con sus referencias en el texto.
2026-08-10 Aceptar el formato de export real de la planta en la carga masiva
    El CSV exportado usa mac_sensor, nombre_sensor, maquina, fecha, hora y
    temperatura_c. Se reconoce mac_sensor como identidad, y nombre/maquina se
    guardan en una tabla aparte para mostrar etiquetas amigables en el
    selector de sensores. Selftest actualizado con el encabezado real.
2026-08-10 Agregar figuras y tabla de validacion con datos reales de planta
    Analisis de las 51338 muestras reales: serie de temperatura de 32 dias con
    el evento del succionador, mapa de cobertura que evidencia interrupciones
    simultaneas entre nodos (gateway apagado, no fallas de enlace) y cadencia
    de recepcion. Nueva subseccion de resultados con tabla de disponibilidad:
    disponibilidad del enlace >97% excluyendo paradas de planta. Script
    reproducible en analisis/figuras_validacion.py.
2026-08-10 Redactar articulo HardwareX en ingles sobre la plantilla oficial
    Version en ingles estructurada segun la plantilla del journal:
    specifications table, hardware in context, hardware description, design
    files summary, bill of materials, build/operation instructions y
    validation and characterization con los datos reales de planta
    (disponibilidad de enlace >97%, cadencia, caso del succionador). Reutiliza
    las figuras de validacion y el BOM ya existentes.
2026-08-10 Agregar PDF compilado del articulo HardwareX
    PDF de 9 paginas con las figuras de validacion, para revision y muestra.
2026-08-10 Instrumentar PDR: contador de secuencia en el nodo y calculo en el gateway
    El nodo agrega un contador SEQ (persistente en deep sleep via RTC_DATA_ATTR)
    a cada trama de datos. El gateway parsea SEQ y calcula en vivo, por nodo,
    enviados/recibidos/perdidos/PDR, imprimiendolos en el monitor serie como
    evidencia reproducible para la validacion. Compatible con nodos sin
    reflashear (sin SEQ no generan linea PDR). Incluye protocolo de prueba.
2026-08-10 Actualizar tesis segun la revision: resultados en pasado, tabla de criterios y aporte
    - Tabla criterio vs. resultado (disponibilidad cumplida; PDR, latencia,
    error, autonomia y recuperacion como 'por medir' con la prueba de cada uno).
    - Distincion explicita entre disponibilidad y PDR.
    - Aporte/novedad reformulados (diseno y validacion experimental de una
    arquitectura de bajo costo, no un componente nuevo).
    - Figura de arquitectura con desglose por nodo (PT100->MAX31865->ESP32->LoRa).
    - Verbos en futuro de trabajo ya hecho pasados a pasado; abstract y
    conclusiones actualizados (disponibilidad hecha, PDR instrumentado).
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2026-08-19 Arreglos de revision: arquitectura unica, descarga no lineal, Fluke 71.0, floats del articulo
    - Tesis: eliminada la figura de arquitectura duplicada (queda la de cadena de
    senal por nodo); muestreo corregido a 120 s (era 60).
    - Autonomia: curva de descarga modelada como LiPo no lineal (meseta central),
    ~10 meses por el modelo y ~177 d por la lineal (cota inferior); texto y
    figura actualizados en tesis y articulo.
    - Evidencia: foto del Fluke reemplazada por la de 71.0 C para que coincida con
    el dashboard (antes 65.2 vs 71.0 se veia desfasado).
    - Articulo: placeins + FloatBarrier para que las figuras no caigan entre las
    referencias.
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2026-08-21 Prueba de alcance (>600 m) con RSSI + carcasas STL/3MF
    - Prueba al aire libre 20-ago: RSSI de -15 dBm (cerca) a -98 dBm a >600 m,
    enlace operativo cerca del limite de sensibilidad; bateria plana ~94% en
    2.6 h (respalda autonomia). Figura y subseccion en tesis y articulo.
    - RSSI ya medido (el firmware nuevo lo capturo): se actualizan las notas de
    'RSSI no disponible'; SNR sigue como limitacion del E220.
    - Carcasas STL + 3MF (sensor, gateway y tapas) en hardware/carcasa/ como
    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
    [carcasa-gateway.stl, carcasa-sensor.stl, tapa-gateway.stl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]
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2026-09-15 Agregar fotos de mediciones, evidencias adicionales y correcciones del articulo HardwareX (PDFs recompilados)
    [Correciones IA a tener en cuenta.xlsx]
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2026-09-17 Tesis: componentes identificados, criterios del anteproyecto, capitulo de fundamentos, modelo de consumo, cronologia e incertidumbre; tono de resumen a anexos
    [BOM.csv, cronologia.csv]
2026-09-18 Fotos del diseno final (carcasas, nodo instalado, Fluke), paradas del rodamiento fechadas y cronologia actualizada
    [cronologia.csv]
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2026-09-23 Documentar origen de compra de la PT100 y actualizar los PDF de entrega
    [BOM.csv]
2026-09-23 Identificar la sonda PT100 (ZUIDID, pelicula delgada, cable -60 a +200 C) y actualizar los PDF de entrega
    [BOM.csv]
2026-09-29 Comparacion termica con parejas Fluke verificables por hora contra el CSV; retirar el 0,4 C y las parejas sin registro
    [parejas_fluke.csv]
2026-09-29 Agregar las dos parejas Fluke del 5 de junio: seis parejas estables verificables
    [parejas_fluke.csv]
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
